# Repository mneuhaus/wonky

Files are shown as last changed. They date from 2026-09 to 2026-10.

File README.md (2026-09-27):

# wonky

A pre-release CAD kernel written in Rust, with Onshape FeatureScript and build123d
frontends. Geometry uses floating-point coordinates with exact predicates for
sign and topology decisions. Unsupported or undecidable operations return named
refusals rather than fabricated geometry or silent partial success.

## Status

The Rust kernel is under active development. FeatureScript compatibility and
solid-modeling coverage are incomplete. [CAD-Acid](docs/cad-acid.md) is the public
benchmark; its per-case evidence and explicit failures matter, not a blanket
compatibility claim. Other CAD kernels are independent validation oracles, not
production geometry engines.

## Layout

- `rust/`: Rust workspace, geometry kernel, contracts and vendored dependencies.
- `src/`: JavaScript frontends, interpreter, bridges and export integration.
- `bin/`: command-line entry points.
- `viewer/`: model inspection UI.
- `fixtures/`: public synthetic cases and frozen reference data with provenance.
- `docs/`: architecture, algorithms, research and known limitations.
- `twin/`: experimental hardware-protocol simulator.

## Build and test

Install JavaScript dependencies with `pnpm install --frozen-lockfile` when using a
pnpm lockfile, or `npm ci` with the checked-in npm lockfile. Python tools use `uv`.

```sh
cd rust && cargo test --offline --locked --workspace
# From the repository root:
NODE_OPTIONS=--max-old-space-size=8192 node scripts/test-lane.mjs full --jobs=2
uv run --project twin pytest twin/tests
```

The Node suite explicitly skips local-only fixtures and unavailable retired Bend
inputs. Rust dependencies are vendored. Some integration tests additionally need
Python oracle dependencies; consult their diagnostics for requirements.

## Local-only fixtures

Product sources and derived captures are not all public. In particular, R20
sources and derived geometry, and the historical r10b product fixtures, are not
included. Tests that require these inputs report an explicit local-only skip.
A passing public suite does not validate the omitted products. Private report
terms can be supplied via `WONKY_PRIVATE_TERMS`; publication environments should
set `WONKY_REQUIRE_PRIVATE_TERMS=1` to require that local list.

## Bend kernel (retired)

The Bend code is retained as historical work, not an active implementation.
It does not build from a public checkout: the unlicensed vendored
bend-collections library and four copyleft reference ports are intentionally
excluded. Native Bend captures are also local-only. No new Bend work is planned.

## Licence

No licence has been granted for wonky's own code yet; all rights reserved.
Third-party material retains its respective licences and attribution.
See [THIRD_PARTY_NOTICES.md](THIRD_PARTY_NOTICES.md).

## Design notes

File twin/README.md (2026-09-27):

# Wonky twin

Kinematic SKR Pico endpoints and a Feetech SC servo bus speaking the pinned
sorter's protocols over three real PTYs in one process. Run from the workspace
root with `uv run --project twin wonky-twin up --with-backend`; stop with Ctrl-C.
Tests: `uv run --project twin pytest`. The backend source is the read-only
`tmp/twin-sorter/8bd54541` archive. Its unchanged dependency lock permits reuse
of `tmp/twin-sorter/65472c9d/software/sorter/backend/.venv` without writing the
source archive. The launcher writes only isolated run state and enables servos.

The ideal-drive joint trajectory is a staircase of microstep pulses. Events
are timestamped at 100 µs boundaries, speed updates at 1 ms boundaries. Before
every command and snapshot, events are advanced to that instant, never into
the future. Endstop threshold crossings therefore occur at the actual joint
pulse time; HOME observes a crossing no later than the next 100 µs poll.
This is not continuous mechanical/contact simulation or measured hardware.

Protocol quirks intentionally retained: a fragment shorter than eight encoded
bytes survives its delimiter and corrupts the next frame; 246-byte PING has no
reply; INIT preserves position while simulated reboot resets the counter but
holds the mechanical pose. Handler validation uses the declared header length,
including PING truncation. A declaration exceeding the received payload gets
an explicit NACK, rather than emulating firmware reads into CRC/stale memory.
TMC configuration writes use the firmware's shadow CHOPCONF, independent of raw
register writes; INIT leaves TOFF=3 while the separate nEN gate is disabled.

## SC bus and trace

The default tray is id 2, SC09 (300°). `--tray-id 17` selects SC15 (210°)
instead; two servos never compete for the same `rock` joint. Ids 15/16 are SC15
flaps shown as numbers, id 18 drives `return`. Joint limits, axes and home pose
come from the frozen `fixtures/r20-motion.json`. All EEPROM limits, `zero_raw`
and `raw_per_deg` are **nominal**, not calibration measurements. Limits round
to the nearest raw count (at most half a count, also exposed in the snapshot).

Implemented: PING/READ/WRITE, big-endian EEPROM/PID/torque registers, 6-byte
GOAL_POSITION with nonzero goal time and zero speed, interpolated
PRESENT_POSITION, MOVING, nominal zero LOAD/CURRENT and nominal voltage/temp.
Unsupported writes/instructions and speed-controlled/zero-time goals return
status 0x40, angle-limit violations 0x02. Bad checksums get echo only. The PTY
emulates adapter echo even when a servo is missing or does not answer.
Retargeting starts from the actual in-flight pose, not the old target.

Torque off holds the tray/flaps at their instantaneous pose. The return arm
instead **snaps home under idealized gravity**, cancelling its trajectory. This
is an explicit kinematic assumption, not a gravity/contact-time simulation.
Unpowered goals do not move the joint; re-enabling requires a fresh goal.

Snapshots add `sc_bus` (raw actual/goal, trajectory timestamps, torque, nominal
calibration/telemetry, fault events and instantaneous coupling error), and
`joints.rock` / `joints.return`. Every 1 ms tick is retained in a bounded 120 s
numeric ring. On shutdown the CLI writes `sc-trace-<epoch>.json` and
`sc-samples-<epoch>.json` beside its run file. Samples are
`[sim_ns, rock_deg, return_deg, rock_torque, return_torque]`. The wire history is
bounded to 20,000 transactions; use short isolated runs for full-stroke checks.
`wonky_twin.sc_trace.check_trace` independently replays accepted wire goals and
torque commands, compares every retained pose tick and PRESENT_POSITION read,
and counts every coupling violation. Dump/transition ticks are NOT exempt.

For programmatic fault scenarios, call `twin.sc.inject(id, kind, count)` under
`twin.lock`: `nack_goal` refuses with status 0x02, `no_reply_goal` refuses with
no servo response, `uncalibrated` exposes EEPROM 500..520. Counts are wire
transactions, so three unanswered attempts exhaust the backend's retries.
This is pre-execution refusal, not lost ACK after executing a command.

Run the real-backend diagnostic (sandbox, no HTTP listener) with
`uv run --project twin python -m wonky_twin.sc_acceptance --output
 twin/evidence/sc-acceptance.json`. It records the normal double-drop reject
branch, then separately labelled controller-component probes using real
absolute-degree TrayServo objects, real ScServoBus clients and synthetic
perception counts. Exit 1 preserves evidence of unmet upstream acceptance; it
does not patch the backend or convert those blockers into passing tests.
The full-app Safe Home proof lives in `tests/test_live_backend.py`.

## OPEN

- **TW5 return trigger:** pinned `controller.py:_servo_or_none` omits
  `zero_raw` / `raw_per_deg` when constructing TrayServo. The actual confirmed
  double-drop reject path therefore sets `return_skipped` and routes to the
  chute. Supplying an absolute servo in a component probe is NOT application
  end-to-end acceptance.
- **TW5 NACK:** `ScServoBus._transact` records nonzero status but returns a
  successful payload. A refused GOAL_POSITION does not fault the tray. No
  reply does fault it; uncalibrated limits refuse initialization.
- **TW5 coupling/dwell:** `(return=180, rock=-45)` differs by 90° from the
  literal coupling law. Even excluding that deliberate dump pose, the pinned
  planner begins lowering before rock has interpolated back to -135°. The
  trace checker reports this transition violation instead of teleporting the
  joint or widening the 5° tolerance. A timed target dwell is not necessarily
  a full 1 s at the measured pose.

- **D5, blocked:** the backend's background `waveshare_inventory` calls
  `serial.tools.list_ports.comports()` without consulting `SORTER_MCU_PORTS`.
  The MCU-bus override is not a global no-enumeration guarantee. Requires a
  sorter-side inventory/discovery gate. The sandbox prevents real serial
  access, but does not prevent enumeration; no monkeypatch/workaround here.
- **D6, blocked:** backend `main.py` hard-codes port 8000 and has a conflicting
  process guard. Requires a sorter-side configurable-port/ownership seam.
  Launch refuses an occupied 8000 without touching its listener. Refusal is
  not alternate-port support; no port interception or backend patch here.

The full suite retains the failing D5/D6 acceptance tests. Neither is skipped
or relabeled as passing. A passing homing run does not close those blockers.

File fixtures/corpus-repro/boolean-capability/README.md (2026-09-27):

# Repros: cluster boolean-capability

Minimal FeatureScript inputs for the corpus cluster "opBoolean outside the
admitted Boolean paths" ([analysis](../../../docs/corpus/cluster-boolean-capability.md)).
Each feature is one real corpus failure reduced to the refused `opBoolean` and
the operations that build its operands. Corpus numbers are kept where the
failure depends on them. The files do not read anything from `~/Workspace/cad`.

Checked on 2026-09-23 (00:38, and again at 04:13 against the unchanged production
Boolean code) with the production CLI on the default JS path:
`node bin/wonky.mjs fixtures/corpus-repro/boolean-capability/<file> --check --feature <feature>`.
The messages are shortened after the first clause; all four are exactly the
corpus messages of the cluster. Each feature runs in 0 to 3 s.

| file `#feature` | sub-cause | stands for (corpus units) | observed |
|---|---|---|---|
| `coaxial-revolution.fs#ringUnion` | coaxial-revolution | fs95 ring unions (56) | `61:9: opBoolean supports coaxial cylinder primitives, … general trimmed-face booleans are not implemented` |
| `coaxial-revolution.fs#countersunkHead` | coaxial-revolution | countersunk screws: cylinder ∪ cone (26) | `70:9:` same message |
| `through-hole-admission.fs#obliqueHole` | pierce-admission (oblique caps) | hopper panels fs421/fs269/fs244 (13) | `61:5: opBoolean through holes need a tool axis perpendicular to exactly two faces of the target` |
| `through-hole-admission.fs#steppedHole` | pierce-admission (extra perpendicular faces) | fs87/fs88 diagonals (4) | `61:5:` same as above |
| `through-hole-admission.fs#arcPlateHole` | pierce-admission (arc edges) | fs422/fs425 guides (8) | `61:5: opBoolean supports coaxial cylinder primitives, …` (the pierce gate excludes ranged edges) |
| `through-hole-admission.fs#unitedPlateHole` | pierce-admission (ranged line edges) | switchPinCapR4, drilledHangerU2, upperMotorHanger (3) | `61:5:` general message |
| `general-trimmed-face.fs#socketHex` | general | hex sockets in coaxial screws fs95/fs88/fs273 (18) | `57:5:` general message |
| `general-trimmed-face.fs#bandNotch` | general | channel bases fs398/fs550/fs386 (16) | `57:5:` general message |
| `general-trimmed-face.fs#bossUnion` | general | rounded ends (stadium unions) fs276/fs398/fs509 (6) | `62:5:` general message |
| `general-trimmed-face.fs#ringBoss` | general | fs95 screw bosses on ring walls (next blocker of 28) | `62:5:` general message |
| `general-trimmed-face.fs#spokeTrim` | general-trim | fs95 bottomSpoke/switchBracket, fs88 motorBracket (10) | `57:5: opBoolean through hole must land in material; this axis misses the face it would pierce` |
| `nary-union.fs#threeToolUnion` | nary | `unite(context, id, [a, b, c])` helpers (13) | `34:9: opBoolean currently requires two tools for union/intersection, or one target and one tool for subtraction` |
| `nary-union.fs#bridgedThreeToolUnion` | nary (first two tools disjoint, the third connects them) | fs95 `motorBracket` `join` | `48:9:` same as above |

After W1 (2026-09-23), production `opBoolean` is N-ary
(`ModelingContext.naryBoolean`): both `nary-union.fs` features build one body
of 15000 mm³ with the production CLI. See
[docs/corpus/w1.md](../../../docs/corpus/w1.md).

## Through the bake-off route

`node scripts/corpus/boolean-bakeoff.mjs` freezes the operands of each refused
`opBoolean` (production probe), runs them through the corefine mesh Boolean
and the recover prototype (native CPU builds), exports STEP with the kernel's
serializer and measures it with OpenCascade. Results:
`out/corpus/boolean-capability/bakeoff.json`.

| repro | result | volume vs closed form |
|---|---|---|
| ringUnion, countersunkHead, steppedHole, arcPlateHole, unitedPlateHole, socketHex, bandNotch, spokeTrim | exact: OCCT-valid STEP | ≤ 2.4e-14 relative |
| obliqueHole | recovered, but the kernel's cylinder pcurve export refuses it (`InvalidSource`): the rims are circles on the F64 tool axis, the caps are the planar kernel's F32 planes, tilted by 3e-7 rad | – |
| bossUnion | recover refuses: `mesh boundary does not traverse its exact curve once` (plane tangent to the cylinder at the stadium corners) | – |
| ringBoss | recover refuses: `cylinder/cylinder intersection off a common axis is a space quartic` (the axes are parallel, so the exact curves are lines) | – |

Both N-ary features build one body of 15000 mm³ (closed form: 6000 + 2 × 4500)
once the call is decomposed into binary calls
(`WONKY_CORPUS_STUB=nary node scripts/corpus/boolean-probe.mjs <file> <feature>`).
`bridgedThreeToolUnion` needs the component-aware decomposition: a left fold
that continues with the first result body returns two bodies, because the
first pair is disjoint.

## With F32x2 prisms (simulation)

With every polygon prism built by the existing F32x2 line/arc extruder
(`WONKY_CORPUS_SIMULATE=linearc node scripts/corpus/boolean-probe.mjs <file> <feature>`,
the fix proposed by the boolean-invalid-topology analysis), `obliqueHole`,
`steppedHole`, `unitedPlateHole`, `bossUnion` and `spokeTrim` all refuse with
the general message. Every F32x2 prism edge carries a `curveRange` (18 of 18
on `steppedHole`), and the pierce gate (`src/boolean.mjs:108`) keeps ranged
edges out. That fix therefore needs the gate to admit ranged lines at the
same time.

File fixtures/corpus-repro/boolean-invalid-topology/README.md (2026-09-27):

# Repros: planar arrangement Boolean refuses F32-built operands

Cluster `boolean-invalid-topology` of the corpus run. The analysis is in
[docs/corpus/cluster-boolean-invalid-topology.md](../../../docs/corpus/cluster-boolean-invalid-topology.md).
Every file is standalone and does not depend on `~/Workspace/cad`.

All were re-checked on 2026-09-23 at 04:13 with the production CLI on the
default JS path (`node bin/wonky.mjs <file> --check [--feature F]`). The
records are in `out/corpus/boolean-invalid-topology/repros-recheck.jsonl`,
with `uptime` per record. These are inputs, not tests: they document current
behaviour.

## After W2 (2026-09-23, 19:25)

Production now builds polygon prisms and their rigid copies in F32x2 in Bend
(`kernel/polygon-prism.bend`, wired in `src/kernel.mjs`; docs/corpus/w2-plan.md task D).
W2 also fixed a false negative in the planar arrangement's plane equality
(`kernel/ports/planar-boolean-arrangement.bend` `plane_equal`): its F32x2 cross filter
required an exactly zero cross, but `R.mul` is not commutative in its last bits, so a
prism side face of `slanted-prism-union.fs` was not equal to itself and the face
ownership map refused (stage 6). The exact certificate still decides.
Re-checked with the production CLI on the JS path (`tmp/w2/wire/repros.sh`):

| File (feature) | Observed after W2 |
|---|---|
| `wedge-union.fs` (`slanted`) | builds: 41 vertices, 79 edges, 40 faces, 319 mm³ |
| `wedge-union.fs` (`diag45`, `square`) | unchanged: 394 mm³, 494 mm³ |
| `slanted-prism-union.fs` | builds: 56 vertices, 106 edges, 52 faces, 206767.2 mm³ |
| `slanted-prism-cut.fs` | builds: 48 vertices, 91 edges, 45 faces, 48766.666667 mm³ |
| `rotated-box-cut.fs` | builds: 8 vertices, 12 edges, 6 faces, 36339.234517 mm³ |
| `slanted-prism-intersection.fs` | builds: 16 vertices, 24 edges, 10 faces, 43659.488134 mm³ |
| `many-vertex-prism-cut.fs` | unchanged: `37:9: … subtraction unresolved: UnsupportedArrangement (stage 1, detail 0)` (input size) |
| `next-blocker-chamfer.fs` (`chamferOnEdge`) | builds: 12 vertices, 20 edges, 10 faces, 2170 mm³ (= 2800 − 14 · 45) |
| `next-blocker-chamfer.fs` (`slantedCut`) | builds: 14 vertices, 23 edges, 11 faces, 2285.694444 mm³ (= 2800 − 14 · 36.736111) |
| `next-blocker-chamfer.fs` (`chamfer45`) | unchanged: 1904 mm³ |

Both chamfers get further than the simulation below predicted (`AmbiguousContact` stage 2
and `UnsupportedArrangement` stage 6): the simulation built line/arc-extruder bodies with
other carrier words, and it ran before the `plane_equal` fix.

## Before W2

The last column is the result with the fix simulated, which builds every
polygon prism and its rigid copies in F32x2
(`node scripts/corpus/diagnose-planar-admission.mjs <file> [feature] --simulate linearc`).

| File (feature) | Stands for | Observed | With the fix simulated |
|---|---|---|---|
| `wedge-union.fs` (`slanted`) | **minimal**: a 3-vertex wedge with a 35° hypotenuse, united with a box | `33:5: Native planar arrangement union unresolved: InvalidTopology (stage 1, detail 0)` | builds, 319 mm³ |
| `wedge-union.fs` (`diag45`) | control: 45° hypotenuse | builds: 41 vertices, 79 edges, 40 faces, 394 mm³ | builds |
| `wedge-union.fs` (`square`) | control: rectangle | builds: 44 vertices, 84 edges, 42 faces, 494 mm³ | builds |
| `slanted-prism-union.fs` | fs95 unions, e.g. `interface-r3.fs#bottomSpoke` | `33:9: … union unresolved: InvalidTopology (stage 1, detail 0)` | builds, 206767.2 mm³ |
| `slanted-prism-cut.fs` | `project-component-4c7a33fe.fs` `noseCut`, fs95 `retainingKey`/`switchBracket` cuts | `33:9: … subtraction unresolved: InvalidTopology (stage 1, detail 0)` | builds, 48766.667 mm³ |
| `rotated-box-cut.fs` | the 8 r10b copies `r10bTransferEdge` (`buildTransferEdge > cut`), unchanged r10b numbers | `35:9: … subtraction unresolved: InvalidTopology (stage 1, detail 0)` | builds, 36339.2345 mm³ |
| `slanted-prism-intersection.fs` | fs95 `bottomSpoke` R4/R5 (`flareClip`) | `33:9: Native convex-tool intersection unresolved: UnsupportedArrangement (tool 0, face 0)` | builds, 43659.488 mm³ |
| `many-vertex-prism-cut.fs` | `channel-bases-r7.fs`: a 384-vertex polygonized arc band | `37:9: … subtraction unresolved: UnsupportedArrangement (stage 1, detail 0)` | unchanged: input size limit (256 vertices) |
| `next-blocker-chamfer.fs` (`chamferOnEdge`) | second level: a slanted face that starts on an existing edge | `37:5: … subtraction unresolved: InvalidTopology (stage 1, detail 0)` | `AmbiguousContact (stage 2, detail 11)` |
| `next-blocker-chamfer.fs` (`slantedCut`) | second level: a slanted cut in general position | `37:5: … subtraction unresolved: InvalidTopology (stage 1, detail 0)` | `UnsupportedArrangement (stage 6, detail 0)` |
| `next-blocker-chamfer.fs` (`chamfer45`) | control: 45° chamfer | builds: 22 vertices, 40 edges, 20 faces, 1904 mm³ | builds |

On the bake-off `recover` route
(`scripts/corpus/boolean-invalid-topology/bakeoff-recover.mjs`):

- with today's F32 operands, the wedge, slanted union, slanted cut and rotated
  cut are refused at leaf intake (`vertex off its surface by 7.7e-7 … 3.6e-5`);
- with F32x2 operands, all four build as OCCT-valid exact B-reps;
- both second-level chamfers build as OCCT-valid exact B-reps from bake-off
  `prism` primitives.

The last column of the table is the expected result once the F32x2
construction exists. `wedge-union.fs` also states it in its header (319 mm³,
that is 175 + 180 − 36).

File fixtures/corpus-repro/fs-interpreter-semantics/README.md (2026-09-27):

# Repros: fs-interpreter-semantics

Minimal FeatureScript inputs for the cluster "Interpreter semantic gaps"
(67 units, 58 files, 13 families; see
[docs/corpus/cluster-fs-interpreter-semantics.md](../../../docs/corpus/cluster-fs-interpreter-semantics.md)).
They do not depend on `~/Workspace/cad`. These are inputs, not tests.

Checked on 2026-09-22 with `node bin/wonky.mjs <file> --check` on the default JS
path. The "with prototype fix" column runs the same CLI with the in-memory
prototype, `node --import ./scripts/corpus/fs-interpreter-semantics/prototype/register.mjs bin/wonky.mjs <file> --check`.
It does not change any file under `src/`.

| File | Units | Production CLI | With prototype fix |
|---|---:|---|---|
| `length-bounds-default.fs` | 21 | `13:9: Expected a length with units (for example 10 * millimeter)` | builds, 25 mm cube (LENGTH_BOUNDS default 0.025 m) |
| `boolean-default.fs` | 15 | `12:9: Feature precondition failed` | builds (`open` = false) |
| `annotation-filter-and.fs` | 16 | `15:50: FeatureScript conditions must be boolean` | builds (only the annotation's `Default` is evaluated). An unpicked query parameter is not resolved by this feature; a feature that resolves one gets an explicit capability error (supply it with --param, e.g. part=qNothing()). |
| `angle-bound-spec.fs` | 9 | `8:14: Expected AngleBoundSpec` | builds |
| `color-type-tag.fs` | 2 | `16:9: Expected Color` | builds (`color()` returns a `Color`-tagged map) |
| `units-source-error.fs` | 4 | `15:22: Incompatible units in expression` | same error. This is correct: the corpus source adds a unitless vector to a length vector. |

With explicit parameters, production already builds the first two, for example
`--param 'size=25*millimeter'` and `--param 'open=false'`.

Re-checked on 2026-09-23: same results.

After W1 (2026-09-23), the production CLI gives the "with prototype fix"
results: `length-bounds-default.fs` 15625 mm³, `boolean-default.fs`,
`annotation-filter-and.fs`, `angle-bound-spec.fs` and `color-type-tag.fs`
1000 mm³ each. `units-source-error.fs` still fails with
`15:22: Incompatible units in expression`. See
[docs/corpus/w1.md](../../../docs/corpus/w1.md).

The two files in `next/` are not part of this cluster. They are the Boolean
that 19 units hit once the cluster is fixed, and they fail in production today
independent of it. Both are the boolean-capability cluster's
`pierce-admission` subcause: after earlier planar cuts or unions, the cap
planes are split into several coplanar faces and the edges are ranged.

| File | Units | Production CLI | Bake-off recover route |
|---|---:|---|---|
| `next/lochwand-hole-in-notched-panel.fs` | 17 lochwand + 1 gt2 mini-r1 (through holes) | `29:9`: general trimmed-face `opBoolean` message | exact, OCCT-valid, volume 1189758.850 mm³ (closed form) |
| `next/blind-pilot-in-stepped-body.fs` | 1 mini_camera (blind pilot bore, 1 mm floor) | `31:9`: same message | exact, OCCT-valid, volume 12146.907 mm³ (closed form) |

The same hole in the panel without the notch builds in production. A
through-hole admission fix ("pierce v2") would cover the first file but not
the second: a blind pocket needs a floor the hole arm does not build. The
bake-off run is `scripts/corpus/fs-interpreter-semantics/next-bakeoff.mjs`;
see `docs/corpus/cluster-fs-interpreter-semantics.md` §4.4.

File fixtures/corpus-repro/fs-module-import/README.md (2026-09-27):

# fs-module-import repros

Minimal inputs for the cluster "FeatureScript module imports cannot be
resolved". The analysis is in
[docs/corpus/cluster-fs-module-import.md](../../../docs/corpus/cluster-fs-module-import.md).
The inputs do not depend on `~/Workspace/cad`. They are inputs, not tests. They
record current behavior and need no change to stay valid. All were checked on
2026-09-23 with the production CLI on the default JS path.

## Unresolved imports (the corpus signature)

Run `node bin/wonky.mjs <file> --check` from the repository root.

| File | Stands for | Observed |
|---|---|---|
| `part-studio-import.fs` | `NS::build` of a Part Studio, 95 files. Reduced from `cad-project-040/src/buildplate-r16-rear.fs`. | `13:23: Unresolved Onshape module 'Parts': d9c8543f8a347821ee2e2194 at version 188904c7a670c9866e4b06de. Supply its frozen source or B-rep snapshot.` |
| `feature-studio-import.fs` | `NS::function` of a Feature Studio in another document, 3 files. Reduced from `machine-interface-r11/top-full-module-r4/module-r4.fs`. | `12:5: Unresolved Onshape module 'SourceR11': 889f3a9e…/3a4a721e…/6d0c52f9… at version 929e2218…. Supply its frozen source or B-rep snapshot.` |
| `local-path/main.fs` + `lib.fs` | An fsocct `version: "local"` library, 1 file. Reduced from `cad-project-043/fsocct/examples/canonical_m3_tool.fs`. | `12:5: Unresolved Onshape module 'M3': ./lib.fs at version local. Supply its frozen source or B-rep snapshot.` |

## With a snapshot present (`snapshot/ (local only)`)

`snapshot/ (local only)idioms.fs` imports the `base` Part Studio of r10b at the r10b
microversion. `snapshot/ (local only)modules.json` uses schema `wonky-onshape-inputs/1`. It
is bound to the SHA-256 of `idioms.fs` and holds one captured body, the `T06
R6d 249.2mm rear hopper wall` (part `Zu2DD`). The files
`modules/base/parts.json` and `modules/base/Zu2DD.body.json` are byte copies
of the files in `fixtures/r10b/modules/base/`. Their hashes therefore match the
r10b capture of 2026-09-21. Each feature exercises one corpus idiom.

Run `node bin/wonky.mjs fixtures/corpus-repro/fs-module-import/snapshot/ (local only)idioms.fs --check --feature <name>`.

| Feature | Corpus idiom (cluster files) | Observed before stage 1 | After stage 1 (revision-keyed loader) |
|---|---|---|---|
| `nameLookup` | `loadedContext` plus a name table, as in r10b (36 files) | builds: `model/src/wall: 16 vertices · 24 edges · 10 faces · volume not evaluated · closed topology` (positive control) | builds (unchanged) |
| `instantiatorIdQuery` | `qCreatedBy(<instantiator id>)` after `instantiate` (15 files) | the file's own check: `42:15: qCreatedBy(instantiator id) found 0 bodies; Onshape finds 1` | builds: 1 body (the instantiator id is recorded in `createdBy`) |
| `noLoadedContext` | `addInstance` without `loadedContext` (56 files) | `51:5: loadedContext must belong to the specified frozen module build` | `51:5` refusal lifted; next: `Body 'P10 R6d 180mm upper core - raised accessible idler' was not captured in this input snapshot` (the snapshot holds 1 of 17 parts; all solids are selected) |
| `instanceTransform` | `addInstance` with a `transform` (14 files) | `62:5: addInstance field 'transform' is not implemented` | builds: the wall moved by +10 mm in z |
| `sourceFeatureId` | `qCreatedBy(makeId("<source feature id>") + …)` (3 files) | `74:89: 'makeId' is not defined or not implemented by this prototype` | unchanged if `makeId` is missing; with `makeId`: `qCreatedBy over an imported source context is not implemented: frozen Onshape inputs do not record which source feature created each part` |
| `containsPoint` | `qNthElement(qContainsPoint(qBodyType(qEverything(…))))` (56 files select source parts dynamically) | `85:68: 'qNthElement' is not defined or not implemented by this prototype` | unchanged (stage 3) |
| `importedVolume` | an imported source body identified by `evVolume` (fs95, 14 files) | builds: evVolume integrates the imported body in Bend (kernel/volume.bend, closed form, bound in the operation evidence) | fixed (r20-gate analytic-volume) |
| `importedBox` | an imported source body identified by `evBox3d` (fs10, fs11, fs16, fs19: 7 files) | `111:5: Tight bounds over analytic imported faces are not implemented` | unchanged (stage 3) |

Before stage 1, the source binding refused an existing capture for any other
source, even one that imports the same immutable Onshape revision:

```sh
node bin/wonky.mjs fixtures/corpus-repro/fs-module-import/snapshot/ (local only)idioms.fs --check --feature nameLookup \
  --modules fixtures/r10b/modules.json
# …/idioms.fs: Frozen module manifest does not match the FeatureScript source SHA-256
```

This is why 16 corpus files failed even though they import only revisions
that are already captured for r10b (same element and microversion). After
stage 1 manifests bind revisions ([docs/onshape-inputs.md](../../../docs/onshape-inputs.md)),
so the same command builds `model/src/wall`, and the body records
`provenance.sourceBinding: "mismatch"`. The inputs in this directory are
unchanged; `test/modules-revision.test.mjs` runs every feature above.

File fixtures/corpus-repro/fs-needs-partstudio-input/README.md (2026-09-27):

# fs-needs-partstudio-input repros

Analysis: [docs/corpus/cluster-fs-needs-partstudio-input.md](../../../docs/corpus/cluster-fs-needs-partstudio-input.md).
Checked on 2026-09-23 (04:12 and later) with the production CLI on the default JS path
(`node bin/wonky.mjs <file> --check`). These are inputs, not tests.

| File | Stands for | Observed |
|---|---|---|
| `modify-existing-part.fs` | 26 fixed-frame R29/R30 files, 4 c-channel files, 3 return-hardware files, the flush-return guide and the rotor closure (count guard, then a bounds guard) | `15:19: Derive exactly one source part into this Part Studio first` |
| `volume-selected-source.fs` | 14 TOP-clearance files (source part picked by `evVolume`) | `14:15: Expected exactly the declared current TOP source body; matching count=0` |
| `source-block.fs` | The 40 x 20 x 10 mm part both repros expect. It stands in for the earlier Part Studio feature. | builds: `model/block: 8 vertices · 12 edges · 6 faces · 8000 mm³` |
| `catch-without-binding.fs` | 2 misclassified files: `cad-project-028/sorter.fs`, `cad-project-038/scripts/skirt_collar.fs` | `14:143: Expected '(', found '{'` (parser gap; the corpus probe flagged it as a model throw). After W1 (2026-09-23): builds, 2 bodies of 1000 mm³ |

Next blockers behind the guard (they need no Part Studio input; the lines are
copied unchanged from the corpus):

| File | Stands for | Observed |
|---|---|---|
| `next-blocker-fixed-frame-n3.fs` | Level 1 of 20 fixed-frame R29/R30 files: `n3 = n1 - n2` (`fixed-frame-r30.fs:81-83`) | `33:9: Native planar arrangement subtraction unresolved: InvalidTopology (stage 1, detail 0)`. F32-built slanted operands; with F32x2 prisms simulated: `AmbiguousContact (stage 2, detail 15)` |
| `next-blocker-line-arc-joins.fs --feature tinyFilletArcJoin` | Level 2 of the same 20 files: a 0.19° fillet arc between two lines (sketch `n4s0`) | `27:9: Native line/arc sketch unsupported: SelfIntersectionOrTouch` |
| `next-blocker-line-arc-joins.fs --feature splitStraightEdge` | Level 1 of 5 older fixed-frame files (sketch `n2s0`): two exactly collinear consecutive lines | `46:9: Native line/arc sketch unsupported: SelfIntersectionOrTouch` |

Both Part Studio repros build a through hole once `source-block.fs` runs first
in the same context. The CLI cannot do that. The prototype harness can
(`tmp/corpus/cluster-partstudio/seeded-build.mjs`, analysis only):

```
node tmp/corpus/cluster-partstudio/seeded-build.mjs \
  fixtures/corpus-repro/fs-needs-partstudio-input/modify-existing-part.fs \
  --seed-fs fixtures/corpus-repro/fs-needs-partstudio-input/source-block.fs
# {"ok":true,"bodies":1,...}
```

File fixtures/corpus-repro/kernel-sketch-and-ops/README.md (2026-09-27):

# Repros: sketch/profile validation and operation limits

Cluster `kernel-sketch-and-ops` of the corpus run. The analysis is in
[docs/corpus/cluster-kernel-sketch-and-ops.md](../../../docs/corpus/cluster-kernel-sketch-and-ops.md).
Every file is standalone: it does not depend on `~/Workspace/cad`. All were checked
on 2026-09-23 with the production CLI on the default JS path
(`node bin/wonky.mjs <file> --check [--feature F]`), first at 00:10 and again at 04:20
(`node scripts/corpus/kernel-sketch-and-ops/recheck.mjs`, output in
`out/corpus/cluster-kernel-sketch-and-ops.recheck.jsonl`). The observed output is below.

These are inputs, not tests. They document current behaviour.

## After W2 (2026-09-23, 19:25)

Production now builds every polygon prism with the Bend profile ring merge and the F32x2
polygon prism (`kernel/profile-ring.bend`, `kernel/polygon-prism.bend`, wired in
`src/kernel.mjs` `extrudeInBend`/`transformInBend`; docs/corpus/w2-plan.md task D).
Re-checked with the production CLI on the JS path; the table further down is the record
from before W2.

| File (feature) | Observed after W2 |
|---|---|
| `cap-normal-far-from-origin.fs` (`tiltedOctagonFar`) | builds: 16 vertices, 24 edges, 10 faces, 7677.8832 mm³ |
| `cap-normal-far-from-origin.fs` (`tiltedRectangleFar`) | builds: 8 vertices, 12 edges, 6 faces, 1454.4 mm³ (the key pocket, 40.4 × 6 × 6) |
| `cap-normal-far-from-origin.fs` (`tiltedOctagonNear`) | unchanged: 7677.8832 mm³ |
| `through-hole-tilted-panel.fs` | builds: 10 vertices, 15 edges, 7 faces, 62690.946551 mm³ (= 280 · 70 · 3.2 − π · 1.7² · 3.2) |
| `collinear-polyline-vertex.fs` | builds: 8 vertices, 12 edges, 6 faces, 1600 mm³; vertex 2 merged exactly (deviation 0) |
| `profile-over-256-vertices.fs` | builds: 600 vertices, 900 edges, 302 faces, 2513.090386 mm³ (= 120000 · sin 1.2°) |
| `next-tilted-pocket-subtraction.fs` | `27:9: Native planar arrangement subtraction unresolved: UnsupportedArrangement (stage 6, detail 0)` |
| `next-pierce-after-copy.fs` | builds: 3959.787614 mm³, then 3919.575228 mm³ (pierce gate, W2 task A) |
| `loft-*.fs`, `line-arc-sketch-with-holes.fs` | unchanged (not in W2's scope) |

Near-collinear vertices (0 < deviation ≤ the profile tolerance) are merged too and recorded
as a regularization (`construction.profileMerge`, `exactness: 'regularized'`);
`src/kernel.mjs` `PROFILE_MERGE` switches that off. Whether it stays on under `strict` is
Marc's decision.

## Before W2

| File (feature) | Cause | Observed |
|---|---|---|
| `cap-normal-far-from-origin.fs` (`tiltedOctagonFar`) | cap normal | `19:5: Face vertices do not lie on the analytic plane` |
| `cap-normal-far-from-origin.fs` (`tiltedRectangleFar`) | cap normal | `19:5: Plane frame is not orthonormal` |
| `cap-normal-far-from-origin.fs` (`tiltedOctagonNear`) | control | builds: 16 vertices, 24 edges, 10 faces, 7677.88 mm³ |
| `through-hole-tilted-panel.fs` | cap normal, seen by the through-hole Boolean | `23:9: opBoolean through holes need a tool axis perpendicular to exactly two faces of the target` |
| `loft-two-polygons.fs` (`prismatoid`) | loft, planar sides | `27:9: opLoft currently requires two coaxial circular profiles` |
| `loft-two-polygons.fs` (`twistedOctagon`) | loft, twisted sides | `36:9: opLoft currently requires two coaxial circular profiles` |
| `loft-two-polygons.fs` (`squareToCircle`) | loft, polygon to circle | `47:9: opLoft currently requires two coaxial circular profiles` |
| `loft-tapered-slot.fs` (`taperedSlot`) | loft, lines and concentric arcs (next blocker of 10 fs398 channel-base units) | `32:9: opLoft currently requires two coaxial circular profiles`; exact result 4140 + 798π = 6646.990938 mm³ |
| `loft-tapered-slot.fs` (`slotExtrudeControl`) | control | builds: 8 vertices, 12 edges, 6 faces, 7865.574951 mm³ |
| `collinear-polyline-vertex.fs` | collinear vertex | `13:9: Profile has collinear or nearly collinear consecutive edges` (after W2 task C, before D: `15:9: Face loop has collinear or nearly collinear consecutive edges`) |
| `profile-over-256-vertices.fs` | vertex limit | `16:9: A profile must have 3–256 vertices` |
| `line-arc-sketch-with-holes.fs` | inner loops | `18:9: A line/arc sketch cannot mix entities with rectangle, polyline or circle profiles` |
| `next-pierce-after-copy.fs` | next blocker (not this cluster) | `wonky: Bend Real serialization requires a finite magnitude <= 1e20 without F32 exponent underflow` (JS RangeError, no source location) |
| `next-tilted-pocket-subtraction.fs` | next blocker (cluster boolean-invalid-topology) | `27:9: Native planar arrangement subtraction unresolved: InvalidTopology (stage 1, detail 0)` |

With the analysis harness (`scripts/corpus/kernel-sketch-and-ops/harness.mjs`,
analysis stubs only, no production change), these build:

- `--stub frame`: both far cap-normal features and the tilted-panel hole;
- `--stub loftplanar`: `prismatoid`, with volume 3626.6667 mm³ (the exact
  prismatoid volume);
- `--stub collinear`: `collinear-polyline-vertex.fs`;
- `--stub pvol`: `next-pierce-after-copy.fs`.

Other in-flight fixes, simulated in memory (04:20 re-check):

- **F32x2 polygon prism** (the boolean-invalid-topology fix,
  `scripts/corpus/diagnose-planar-admission.mjs --simulate linearc`): both far
  cap-normal features build (7677.8832 mm³). The tilted pocket moves from
  `InvalidTopology (stage 1)` to `UnsupportedArrangement (stage 6, detail 0)`.
  The tilted-panel hole reports the general-Boolean refusal, because the
  simulation's bodies carry curve ranges that the through-hole arm does not
  take. That result is a limit of the simulation.
- **Bake-off route** (`WONKY_CORPUS_STUB=hybrid-all scripts/corpus/boolean-probe.mjs`,
  corefine and recover prototypes, test only):
  - The tilted pocket is recovered from the F32 operands. OCCT reports it
    valid, with 11 faces and 7316.39927 mm³ against the closed-form
    7316.4 mm³ (relative error 1.0e-7).
  - The tilted-panel hole is recovered and the kernel validator accepts it,
    but STEP export refuses it: `STEP cylindrical parameter curves unresolved:
    InvalidSource`.

The cap-normal failures depend on how the F32 coordinates round. The
coordinates are therefore computed exactly as in the corpus source. A
hand-rounded origin can make the same prism build.

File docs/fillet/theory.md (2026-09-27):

# Fillets and chamfers: mathematics and algorithms

Status: 23 September 2026, fillet landscape part 1 (survey). Nothing in this
document is implemented. It is the theory that the prototype ports of part 2
should be built from and judged against.

**Labels.** Every claim that matters carries one of:

- **DOCUMENTED**: stated in a source that was read (the deep-read notes in
  `docs/research/sources/`, a paper, vendor docs, or kernel code).
- **MEASURED**: checked by running something in this repo. The numeric checks
  are in `tmp/fillet/theory-checks.mjs` (run with `node`).
- **INFERRED**: derived here from documented facts. The derivations are
  written out so that they can be checked.
- **HEARSAY**: remembered or second-hand and not verified in this pass.

The sources are cited by their note name, for example
`occt-modeling-algorithms-guide-and-tkfillet-chfi3d-fillets-c.md` (short:
"OCCT note"). The notes carry the URLs, licences and page references.

**Licences, short form** (the notes have the details):

| source | licence | what may be used |
|---|---|---|
| OCCT (ChFiKPart, BlendFunc, ChFi3d) | LGPL-2.1 + exception | ideas and algorithms only; AGENTS.md forbids OCCT in production, and translated code would be LGPL-derived. OCCT is an oracle via `uv run`, never a dependency |
| monstertruck / truck | Apache-2.0 | may be ported with attribution |
| remus | Apache-2.0 | contract layer and types may be ported with attribution |
| Onshape std library (`fillet.fs`, enums, bounds) | MIT | may be copied with the notice |
| Parasolid FD, ACIS docs | proprietary documentation | vocabulary and behaviour only, no text |
| HP/CoCreate patents US5615317A, US6133922A | expired | methods free to implement |
| Geomagic setback patent US8004517B1 | in force until 2027-12-17 | check before any commercial release |
| papers (Choi-Ju, Kós-Martin-Várady, Lukács, Dahl, Shene, Wallner-Pottmann, Rossignac-Requicha) | journal copyright | mathematics may be re-derived freely |

## 0. Reading guide and the one-page summary

1. A constant-radius fillet is the envelope of a ball of radius `r` that
   touches both faces. Its **spine** (the ball-centre path) is the
   intersection of the two faces' offsets by `r` toward the ball; its **contact
   curves** are the spine moved back by `r` along each face normal; its cross
   section is a circular arc. Everything else in this document is a special
   case, an existence condition, or what happens at the ends (section 2).
2. **Two symmetry theorems decide when the fillet is analytic** (section 4):
   - if both faces are invariant under one translation direction `d` (planes
     containing `d`, cylinders with axis parallel to `d`) the problem is a 2D
     fillet in the plane perpendicular to `d`, and the fillet is a
     **cylinder**;
   - if both faces are surfaces of revolution about one common axis (plane
     perpendicular to it, coaxial cylinder, cone, torus, sphere centred on it)
     the problem is a 2D fillet in the meridian half-plane, and the fillet is a
     **torus** (a **sphere** when the arc centre lies on the axis).

   Every other pair gives a pipe surface around a non-circular spine. That is
   exact only as a procedural surface or a rational B-spline, never as a
   plane, cylinder, cone, sphere or torus.
3. Chamfers follow the same two theorems: **plane** in the translation family,
   **cone** (or plane or cylinder) in the rotation family, a rational ruled
   surface otherwise.
4. The dihedral angle enters through the angle `θ` between the face normals:
   contact setback `r·tan(θ/2)`, centre distance `r/cos(θ/2)`, arc angle `θ`,
   section area `r²(tan(θ/2) − θ/2)` (section 3).
5. Vertices: a **sphere** corner exists whenever three blends of equal radius
   and uniform convexity meet (section 6). Everything else (unequal radii,
   mixed convexity, valence ≥ 4 without a common point) needs a setback
   n-sided patch, which is a new non-analytic surface type.
6. **wonky today** (MEASURED by reading `kernel/analytic.bend` and grepping
   `src/`): surfaces `Plane`, `Cylinder`, `Cone`; curves `Line`, `Circle`,
   `Ellipse`. Sphere and torus exist only in `kernel/proto/recover/geom.bend`
   (`SSphere`, `STorus`) and the bake-off test serializer. So wonky can hold
   exactly, today: every chamfer of the two symmetric families, plane/plane and
   other translation-family fillets, and linear variable-radius plane/plane
   fillets (a cone, section 8). It needs `Torus` and `Sphere` for cap-edge
   fillets and sphere corners, which are the most common FDM cases after
   plane/plane (section 11).

## 1. Conventions and definitions

### 1.1 Orientation

- A face `F` has a carrier surface and a `same_sense` flag
  (`kernel/analytic.bend`, type `Face`). `n_F(p)` is the **outward** unit
  normal of the face at `p`: the surface normal, negated when `same_sense` is
  false.
- Loops run counter-clockwise when viewed from outside, i.e. looking along
  `−n_F`, so material is on the left of each coedge. (INFERRED as the kernel
  convention; confirm against `kernel/topology.bend` before implementing.)
- An edge `E` between faces `F1` and `F2` has a unit tangent `t(p)` oriented
  **as the coedge of `F1`**.

### 1.2 Convexity

The edge is **convex** at `p` iff

```
(n1 × n2) · t > 0          n_i = n_{F_i}(p), t oriented along F1's coedge
```

concave iff `< 0`, and smooth (tangent faces) iff `n1 × n2 = 0`. INFERRED;
checked on a box: top face `n1 = +z`, front face `n2 = −y`, the top face's
counter-clockwise loop runs along `+x` on the front edge, and
`(z × −y)·x = +1`, which is convex, as it should be.

- Onshape's `EdgeConvexityType` has a fourth value, `VARIABLE`, for an edge
  whose convexity changes along its length (DOCUMENTED, Onshape FS note). ACIS
  refuses such edges with `BL_NON_U_CVXTY` and asks the user to split them
  (DOCUMENTED, ACIS note). The same test gives it: the sign of
  `(n1 × n2)·t` changes along the edge.
- The sign test is an exact-predicate candidate. Near zero the edge is nearly
  smooth and the fillet nearly vanishes (section 3.2). Decide with the
  filtered or exact path and return "smooth or undecidable" rather than
  guessing.

### 1.3 Ball side and oriented offsets

- The ball of a **convex** edge lies inside the material; it removes material
  (a *round*). The ball of a **concave** edge lies outside the material; it
  adds material (a *fillet*). DOCUMENTED (ACIS `…ad`, Rossignac thesis
  property 3.35).
- The **ball-side normal** of face `F_i` is `m_i = −n_i` for a convex edge and
  `m_i = +n_i` for a concave edge. It points from the surface toward the ball
  centre.
- The **oriented offset** of face `F_i` by `r` is `O_i = { p + r·m_i(p) }`.
  Dahl's thesis handles the same choice by oriented surfaces and signed ball
  radii (DOCUMENTED, Dahl §2.2, Fig. 2.2): the ball is placed where its
  orientation agrees with both surfaces.

### 1.4 Two semantics of "fillet"

- **Global (morphological)**, Rossignac & Requicha (DOCUMENTED, Rossignac
  note):
  - rounding `R_r(S) = (S↓r)↑r`, the opening: the union of all balls of
    radius `r` inside `S`;
  - filleting `F_r(S) = (S↑r)↓r`, the closing.
  - Properties: `R_r(S) ⊂ S ⊂ F_r(S)`, idempotence, `R_a(R_r S) = R_r S` for
    `a ≤ r`.
  - Side effects: global rounding disconnects thin necks (< 2r), global
    filleting bridges gaps (< 2r) between disjoint features and fills slots.
- **Edge-local (what CAD does)**: only the selected edges are blended; the ball
  touches exactly the two faces of the edge (plus overflow rules, section 10).
  This is Onshape/Parasolid, ACIS, OCCT.
- **Relation (INFERRED, from the Rossignac note):** away from the edge ends,
  and when the ball fits, the edge-local fillet equals the boundary of
  `R_r(Q)` (convex) or `F_r(Q)` (concave) for the local wedge `Q` at the edge.
  That makes the global operators a **test oracle** for the local operation.
  They are not the semantics wonky should implement for `opFillet`.

### 1.5 Vocabulary

Wonky should use the shared vocabulary of Parasolid, ACIS and Onshape so that
errors and docs line up with public material (DOCUMENTED terms, see the Vida,
ACIS and Parasolid notes):

| term | meaning |
|---|---|
| primary / support faces | the two faces being blended |
| spine | the path of the ball centre |
| spring curve / contact curve / trimline | where the blend touches a support |
| cross section / profile | the blend's curve in a plane transverse to the spine |
| cross curve | the blend's boundary where it stops (setback plane, cap face) |
| range | a blend's distance from a support (two ranges = asymmetric) |
| terminal / internal vertex | one / several blended edges end there |
| bi-blend | two blends meeting tangentially at a vertex |
| miter | two blends meeting non-tangentially |
| end cap / side cap | a face that terminates a blend / trims one side of it |
| setback | distance from a vertex at which an edge blend is stopped |
| overflow (smooth, cliff, cliff-end, notch) | Parasolid's names for a blend leaving its support faces |
| cliff edge | an existing edge that forms a blend boundary without tangency |

## 2. Constant-radius rolling-ball blends

### 2.1 Construction

For supports `S1`, `S2` with ball-side normals `m1`, `m2` and radius `r`
(DOCUMENTED as the standard construction: Choi-Ju note, Kós-Martin-Várady
§3.2 Fig. 6, Dahl Remark 2.1, ACIS `…bg`, Parasolid FD §29.2):

1. **Offsets.** `O_i = S_i + r·m_i`.
2. **Spine.** `s(t) ∈ O1 ∩ O2`. For each spine point there are parameters
   `(u_i, v_i)` with `S_i(u_i, v_i) + r·m_i(u_i, v_i) = s(t)`.
3. **Contacts.** `P_i(t) = s(t) − r·m_i(u_i(t), v_i(t))`. They come with their
   surface parameters, i.e. they are exact pcurves up to the accuracy of the
   spine.
4. **Section.** The characteristic circle of the ball at `s(t)` is the great
   circle in the plane through `s(t)` perpendicular to `s'(t)`. Both contacts
   lie on it: `s − P_i = r·m_i`, and `m_i ⟂ s'` because `s` moves on the
   offset `O_i`, whose normal at `s` is `m_i`. (INFERRED, standard.)
5. **Blend** = the shorter arc of the characteristic circle from `P1` to
   `P2` ("the portion of the pipe between the spring curves with smaller arc
   length", DOCUMENTED ACIS `…bg`).

The whole ball envelope is a **pipe surface**
`F(t, v) = s(t) + r·(cos v·N(t) + sin v·B(t))` with `(T, N, B)` the Frenet
frame of the spine (DOCUMENTED, Patrikalakis-Maekawa-Cho 11.6).

### 2.2 The exact cross-section arc

With `a = (P1 − s)/r`, `b = (P2 − s)/r`, `cos θ = a·b` (`θ` is the arc angle;
section 3 shows it equals the angle between the face normals):

- control points `P1`, `T`, `P2` with the apex
  `T = s + r·(a + b)/(1 + a·b)`, the intersection of the two contact tangents
  in the section plane, at distance `r/cos(θ/2)` from `s`;
- weights `(1, w, 1)` with `w = cos(θ/2) = sqrt((1 + a·b)/2)`;
- `B(σ) = [(1−σ)²P1 + 2σ(1−σ)w·T + σ²P2] / [(1−σ)² + 2σ(1−σ)w + σ²]`.

DOCUMENTED (Choi-Ju note, citing Lee 1987; the same arc is in monstertruck's
`ContactCircle`). The arc is exact for every `θ < π`. A single rational
quadratic cannot represent `θ ≥ π`; fillet arcs are always `< π` because
`θ < π` (section 3).

- Wonky has `Circle` curves already, so a cross curve that is an arc needs no
  rational form in the kernel. The rational form matters for (a) conic
  profiles (section 9), (b) NURBS export of non-analytic blends, and (c) the
  G1 end conditions of n-sided corner patches.

### 2.3 Existence conditions

A blend of radius `r` exists and is a regular surface when all of these hold.
Each is a named failure when it does not (section 10).

1. **Regular offsets.** The offset of `S_i` toward the ball must not have a
   cusp in the contact region:

   ```
   1 − r·κ_i > 0   for both principal curvatures κ_i of S_i,
   κ measured positive when S_i bends toward the ball
   ```

   DOCUMENTED as the offset singularity condition `κ = −1/d` (Patrikalakis
   11.3.1-11.3.2) and as ACIS's "geometric limitation on the blend radius"
   (a convex support whose radius is below the blend radius makes the spring
   curve loop; ACIS fails). For wonky's surfaces this is a scalar test
   (INFERRED):
   - plane: always true;
   - cylinder or cone of radius `ρ` with the ball **inside** it (`m` points to
     the axis): `r < ρ` (for a cone, `ρ` is the local radius divided by the
     cosine of the half-angle, the principal radius of curvature, evaluated
     over the contact region);
   - ball outside a cylinder or cone: always true;
   - sphere of radius `ρ`, ball inside: `r < ρ`;
   - torus: the tightest principal radius toward the ball, which is the minor
     radius (tube side) or `major − minor` on the inner equator
     (Patrikalakis note, "κmax is attained on the inner equator").
2. **The offsets intersect.** `O1 ∩ O2` must be non-empty near the edge. It
   is empty when, for example, the ball is larger than the available gap
   (a plane and a cylinder whose offsets miss each other).
3. **The pipe is regular on the used arc.** The pipe `F(t, v)` above has
   `|F_t × F_v| = r·|1 − r·κ_s(t)·cos v|·|s'|` (standard canal-surface
   Jacobian). With `v` measured from the spine's principal normal `N`
   (toward the spine's centre of curvature), the used arc must satisfy

   ```
   r·κ_s(t)·cos v < 1    for every v on the arc from P1 to P2
   ```

   DOCUMENTED for the whole pipe as "local self-intersection iff r·κ ≥ 1"
   (Patrikalakis 11.6; Dahl Thm 3.26). The **restriction to the used arc** is
   INFERRED and matters: remus found that the old bound `r ≤ ρ/2` for an inside
   plane/cylinder torus "refused sound geometry" because the used quarter tube
   never reaches the self-intersecting part of a spindle torus (DOCUMENTED,
   remus note). Section 4.6 works this out.
4. **No global self-intersection.** Two distant parts of the pipe must not
   meet: spine self-distance `> 2r` between non-neighbouring parameters,
   plus end-circle checks (DOCUMENTED, Patrikalakis 11.6.3 body/body,
   end/body, end/end).
5. **Contacts stay on their faces.** `P_i(t)` must lie inside face `F_i` for
   every `t` of the edge. When it does not, the blend overflows (section 10.3).

### 2.4 The general (non-closed-form) solver

For pairs outside the symmetric families the spine has no closed form. Two
documented residual systems solve one section at a time:

- **OCCT `BlendFunc_ConstRad`** (DOCUMENTED, OCCT note, LGPL, ideas only).
  Unknowns `(u1, v1, u2, v2)`; guide point `G(t)` on a guide curve, section
  plane normal `ν = G'/|G'|`:
  - `E1 = ν·(P1 + P2)/2 − ν·G(t) = 0`: the contact midpoint lies in the
    section plane;
  - `E2..4 = P1 + r·(ν·n1·ν − n1)/|ν × n1| − P2 − r·(ν·n2·ν − n2)/|ν × n2| = 0`:
    the centres computed from both contacts, with normals projected into the
    section plane, coincide.

  Newton per section, marching along `t` (`BRepBlend_Walking`).
- **monstertruck contact circle** (DOCUMENTED, monstertruck note, Apache-2.0,
  portable). For a point `p` on the edge and current contacts `p0`, `p1` with
  normals `n0`, `n1`:
  - solve the 3×3 linear system with rows `(e', n0, n1)` (edge tangent, then
    the two normals) and right-hand side
    `(e'·p, n0·p0 − s·r, n1·p1 − s·r)` for the centre `c`;
  - target contacts `q_i = c + s·r·n_i`;
  - project each surface onto its target by one Gauss-Newton step with the
    first fundamental form, `[Su·Su Su·Sv; Su·Sv Sv·Sv]·Δ = [Su·d, Sv·d]`;
  - iterate (up to 100 times in monstertruck).

  v-derivatives of any order come from differentiating the linear system by
  Leibniz expansion (DOCUMENTED, `der_routine`).
- **Kós-Martin-Várady inner projection** (DOCUMENTED, Kós note §3.2.3): move a
  point onto the spine by `x ← x + α·v1 + β·v2` with
  `[1 g; g 1]·[α β]ᵀ = [r − d1, r − d2]ᵀ`, `g = v1·v2`, then slide along
  `v1 × v2`. Its sensitivity `dc/dR = (v1 + v2)/(1 + v1·v2)` is the spine's
  derivative with respect to the radius, useful for radius sweeps and for the
  "largest radius that fits" diagnostic.

**Section-plane choice matters.** OCCT and monstertruck put the section plane
perpendicular to a guide (the original edge). The rolling-ball definition puts
it perpendicular to the spine. They coincide in both symmetric families
(section 4) and differ in general. For constant radius the surface is the same
pipe either way; only its parametrisation differs. For variable radius the
choice changes the geometry (section 8). INFERRED.

**Bend fit** (INFERRED, consistent with the notes): the per-section work is
small, uniform and branch-light (3×3 or 4×4 solves, surface evaluation), so
sample sections at fixed `t`, solve each independently (fork-join or GPU
lanes), certify chord deviation between samples, and subdivide failing
intervals. That replaces the sequential marcher. The existence tests of
section 2.3 are per-sample and should run before any construction.

### 2.5 Certification oracle for any constant-radius blend

Independent of how a blend was built (INFERRED from the Kós and Choi-Ju
notes; the maximum-ball residual is DOCUMENTED in Kós §3.3):

- sample points `x` on the blend face; for each, the ball centre is
  `c = x + r·N_blend(x)` (with the blend normal pointing to the ball side);
- assert `dist(c, S1) = dist(c, S2) = r` (to tolerance), with the closest
  points inside `F1`, `F2`;
- assert the blend normal equals `m_i` at the contacts (G1);
- the plane/plane closed form of the maximum-ball radius (DOCUMENTED, Kós
  §3.3.1, elimination INFERRED there):
  `(R−d1)² − 2g(R−d1)(R−d2) + (R−d2)² = (1−g²)R²`, larger root.

This catches wrong side, wrong spine, wrong radius and wrong trim without
reusing construction code.

## 3. The dihedral angle

Let `θ ∈ [0, π)` be the angle between the face normals at the edge point,
`cos θ = n1·n2 = m1·m2` (the `m`s differ from the `n`s by the same sign), and
`φ = π − θ` the opening angle of the wedge the ball sits in (the material
angle for a convex edge, the air angle for a concave one).

### 3.1 Plane/plane quantities

With `e` a point on the edge (INFERRED; the centre formula MEASURED in
`tmp/fillet/theory-checks.mjs`):

| quantity | formula | note |
|---|---|---|
| ball centre | `c = e + r·(m1 + m2)/(1 + m1·m2)` | satisfies `m_i·(c − e) = r`; no trig |
| centre distance from the edge | `r/cos(θ/2) = r/sin(φ/2)` | Onshape `findRadiusToOffsetRatio` uses `1/cos(θ/2)` (DOCUMENTED) |
| contact distance along each face | `r·tan(θ/2) = r·cot(φ/2)` | at 90° this is `r` |
| contact chord ("width") | `r·|m1 − m2| = 2r·sin(θ/2)` | Onshape converts width to radius by `radius = width/|n0 − n1|` (DOCUMENTED) |
| arc angle | `θ` | |
| arc length | `r·θ` | |
| section area between the corner and the arc | `r²·(tan(θ/2) − θ/2)` | MEASURED at `θ = 60°` (0.0537514 sampled vs 0.0537515) |
| volume removed or added along a straight edge of length `L` | `L·r²·(tan(θ/2) − θ/2)` | at 90°: `L·r²(1 − π/4)` |

Numerically stable forms (INFERRED): `tan(θ/2) = |n1 × n2|/(1 + n1·n2)`,
`cos(θ/2) = sqrt((1 + n1·n2)/2)`. No `acos` is needed except for the arc
angle itself, and the rational arc of section 2.2 needs only `cos(θ/2)`.

**A documented bug to avoid.** remus computed the contact setback from half
the normal angle where it needed the wedge half-angle. The two coincide only
at 90°; on a 178.9° ridge the contacts landed about `100·r` away instead of
about `0.01·r` (DOCUMENTED, remus note). Write every formula in terms of `m1`,
`m2` as above and test at 10°, 90°, 170° and 179°.

### 3.2 What the angle does

- **Sharp edges** (`θ → π`, wedge `φ → 0`, a knife edge): contacts run away as
  `r·tan(θ/2) → ∞`. The fillet needs ever wider faces; it overflows or fails
  with `FILLET_FACE_RANGE_TOO_LARGE` long before the formulas degenerate.
  The largest radius that fits a face of available width `w` is
  `r_max = w/tan(θ/2)`. INFERRED; this is also the useful diagnostic value
  ("radius 3 does not fit; 2.4 would").
- **Nearly smooth edges** (`θ → 0`): the fillet shrinks to nothing:
  contact distance `≈ r·θ/2`, section area `≈ r²θ³/24`. The blend is
  numerically delicate (two nearly equal normals) and topologically delicate
  (the fillet face is a sliver tangent to both supports). An exactly smooth
  edge has nothing to fillet: Onshape reports `FILLET_FAIL_SMOOTH` "Could not
  fillet smooth edges" (DOCUMENTED, Onshape FS note).
- **Right angle**: every quantity simplifies (`r`, `r·√2`, `π/2`); this is the
  dominant FDM case and must never be the only test angle.
- **Chamfer width** depends on the chamfer definition (section 5): for
  `FACE_OFFSET` it shrinks as the dihedral opens, for in-face distances it does
  not (DOCUMENTED, ACIS and Parasolid notes).
- **Convex vs concave with the same `θ`**: the section geometry is identical;
  only the side of the ball, the offset direction, the Boolean sign
  (remove vs add), and the curvature condition of section 2.3 change.

### 3.3 Convex vs concave in practice

| | convex edge (round) | concave edge (fillet) |
|---|---|---|
| ball | inside material | outside material |
| `m_i` | `−n_i` | `+n_i` |
| effect | removes material | adds material |
| offset regularity (section 2.3) bites when | a support curves toward the inside of the material, e.g. the top edge of a thin boss (ball inside the cylinder: `r < ρ`) | a support curves toward the air, e.g. the floor edge of a blind hole (ball inside the hole: `r < ρ`) |
| global side effect (section 1.4) | can consume faces and obliterate holes | can fill slots and bury small features |
| terminal-vertex capping (section 6.1) | an extended tool that leaves the body removes nothing, so over-extension is harmless when the neighbours are also convex | an extended tool that leaves the body adds material, so the blend must be cut by the cap face |

Plane/cylinder convexity is easy to get wrong; remus records it as a real
bug: reading the cylinder's `reversed` flag alone as "concave" (DOCUMENTED,
remus note). The convexity of section 1.2 decides, and the table below is its
consequence:

| configuration | edge | ball |
|---|---|---|
| top edge of a boss (cylinder's own end cap) | convex | inside the cylinder |
| rim of a through hole | convex | outside the hole cylinder |
| base of a post standing on a plate | concave | outside the post cylinder |
| floor edge of a blind hole | concave | inside the hole cylinder |

DOCUMENTED (remus `analytic.rs:798-814` table); the ball column INFERRED.

## 4. Analytic special cases

### 4.1 The two symmetry theorems

A constant-radius pipe is a cylinder iff its spine is a line, a torus iff its
spine is a circle, and a sphere iff the spine degenerates to a point.
(DOCUMENTED, ACIS `…bg`: "a straight-line spine gives a cylinder, a
circular-arc spine a torus, a point spine a sphere".) So the question "when is
a fillet analytic" is "when is `O1 ∩ O2` a line or a circle".

**Translation family (INFERRED, standard).** A surface is invariant under
translation along a unit direction `d` if it is a plane containing `d` or a
cylinder with axis parallel to `d`. If both supports are invariant under the
same `d`:

- their offsets are invariant too (offsets commute with the translation);
- their intersection, and therefore the spine, is a union of lines parallel
  to `d`;
- the whole construction is the extrusion along `d` of a 2D fillet in a plane
  perpendicular to `d`;
- the fillet is a **cylinder** of radius `r` with axis parallel to `d`; the
  contacts are lines; a chamfer is a **plane**.

Pairs: plane/plane (`d = n1 × n2`, always); plane/cylinder with the axis
parallel to the plane (`a·n = 0`); cylinder/cylinder with parallel axes.

**Rotation family (INFERRED, standard).** A surface is invariant under
rotation about an axis line `A` if it is a plane perpendicular to `A`, or a
cylinder, cone or torus with axis `A` (the same line, not only a parallel
one), or a sphere whose centre lies on `A`. If both supports are invariant
about the same `A`:

- the spine is a union of circles about `A` (parallels);
- the construction is the revolution about `A` of a 2D fillet in the meridian
  half-plane;
- the fillet is a **torus** with axis `A`, major radius = the radial coordinate
  of the 2D arc centre, minor radius `r`; a **sphere** when that radial
  coordinate is zero; the contacts are circles; a chamfer is a **cone** (a
  plane when the chamfer segment is perpendicular to `A`, a cylinder when it
  is parallel).

Common axes: plane + any coaxial surface → that surface's axis; plane + sphere
→ the line through the centre along the plane normal (always exists); sphere +
sphere → the line through both centres (always exists); sphere + cylinder,
cone or torus → that axis iff the centre lies on it; cylinder/cone/torus pairs
→ iff their axes are the same line.

**Evidence that this is the complete analytic list** (DOCUMENTED): Kós et al.
§4 table ("the blend is a cylinder: plane–plane (any angle); plane–cylinder
with axis ∥ plane; cylinder–cylinder with parallel axes. Torus: plane–sphere;
plane–{cylinder, cone, torus} with axis ⟂ plane; sphere–{cylinder, cone,
torus} with the sphere centre on the axis; coaxial {cylinder, cone, torus}
pairs"), Shene 1998 Thm 16 ("two cones can be blended by a torus if and only
if their axes are identical"), and OCCT's `ChFi3d_KParticular` table, which is
a subset. The claim that nothing outside the two families has a line or
circle spine is INFERRED; no counter-example is known.

**Degenerate spines.** A plane/cylinder pair whose plane contains the axis is
in the translation family. Its rotation-family look-alike, a plane containing
a torus or cone axis, is **not**: the offset plane no longer contains the axis
and the spine becomes a spiric or conic section. The same trap applies to
line edges in general: **a line edge does not imply a cylinder fillet.** A
plane through a cone's apex cuts the cone in generator lines, but the offset
plane misses the offset cone's (shifted) apex, the spine is a conic, and the
fillet is a pipe around a conic (INFERRED).

### 4.2 The 2D fillet solver

Both families reduce to one 2D problem: a circle of radius `r` tangent to two
oriented primitives in a plane. Primitives (INFERRED; each case is a textbook
construction, and Kós §4.3 gives the same bisector view):

- a **line** `{x : ν·x = δ}` with unit `ν` pointing to the ball side;
- a **circle** `{x : |x − q| = ρ}` with `σ = +1` if the ball is outside it,
  `σ = −1` if inside.

Offsets: line → `ν·x = δ + r`; circle → `|x − q| = ρ + σ·r`. The offset
circle must have positive radius: `σ = −1` needs `r < ρ` (section 2.3,
condition 1; equality is a degenerate case, see below).

Centre `c` = intersection of the two offsets:

| pair | solve | failure / degeneracy |
|---|---|---|
| line/line | 2×2 linear: `[ν1; ν2]·c = [δ1 + r; δ2 + r]` | `det = ν1 × ν2 → 0`: parallel lines, a smooth edge |
| line/circle | parametrise the offset line `x(s) = p0 + s·τ` (`p0 = (δ + r)ν`, `τ ⟂ ν`); `s² + 2s·τ·(p0 − q) + |p0 − q|² − (ρ + σr)² = 0` | discriminant `< 0`: the offsets miss, no spine; `= 0`: tangent offsets |
| circle/circle | offset radii `R_i = ρ_i + σ_i r`, `d = |q2 − q1|`, `a = (d² + R1² − R2²)/(2d)`, `h² = R1² − a²`, `c = q1 + a·u ± h·u⊥` | `h² < 0`: no spine; `d = 0`: concentric, no edge |

- **Root choice.** Two roots are the normal case (a line cuts a circle
  twice). Take the root whose contacts lie on the actual face segments
  adjacent to the corner `e` (the 2D image of the edge), i.e. whose ball sits
  in the wedge at `e`. Nearest-to-`e` is the usual heuristic (OCCT takes the
  intersection "closest to the spine start", DOCUMENTED); the contact-on-face
  test is the correct criterion and doubles as the range check.
- **Contacts.** Line: `c − r·ν`. Circle: `q + ρ·(c − q)/|c − q|` (the same
  formula for both `σ`).
- **Arc.** The arc of the circle `(c, r)` between the contacts that faces `e`.
  Its angle equals the angle between the primitives' ball-side normals at
  the contacts.

Extrusion (translation family): the fillet is the cylinder through `c` with
axis `d`, radius `r`; the contact lines are the contacts extruded along `d`.

Revolution (rotation family), in the meridian half-plane with coordinates
`(ρ, h)` (radial, axial):

- torus centre = axis origin `+ h_c·a`, axis `a`, **major `= ρ_c`, minor `= r`**;
- contact circles: the parallels at the two contacts' `(ρ, h)`;
- **sphere** when `ρ_c = 0` (radius `r`, centre on the axis);
- `ρ_c < 0` means the ball crosses the axis: refuse;
- regularity on the used arc (section 2.3, condition 3, specialised; see 4.6):
  every point of the used arc must have `ρ > 0`, except a single touching
  point on the axis in the sphere case.

### 4.3 Plane/plane

- Always the translation family, for any angle. Fillet: **cylinder**, axis
  `c + λ·t` with `c = e + r·(m1 + m2)/(1 + m1·m2)`, radius `r`. Contacts:
  lines `c − r·m_i + λ·t`. DOCUMENTED (OCCT `FilPlnPln`:
  `C = Pv + (R/cos(θ/2))·normalize(D1 + D2)`, which is the same point).
- Chamfer: **plane** (section 5).
- Representation today: exact (`Cylinder`, `Line`). End cross curves: a
  `Circle` arc when the cap face is a plane perpendicular to the edge, an
  `Ellipse` arc for an oblique planar cap (the plane/cylinder section,
  `kernel/analytic.bend` `plane_cylinder`), a quartic for a cylindrical cap
  that is not coaxial (not representable; section 11).
- FDM: box edges, `roundX` in `fixtures/r10b/r10b.fs` (DOCUMENTED, Onshape FS
  note), every edge of an extruded polygon.

### 4.4 Plane/cylinder

Three configurations (DOCUMENTED as a list in the Kós §4 table and the OCCT
eligibility table; the oblique case in the Choi-Ju note and Dahl Thm 2.6):

1. **Axis parallel to the plane** (plane normal `⟂` axis; the edge is a
   generator line; the plane at distance `δ < ρ` from the axis cuts the
   cylinder in two lines, `δ = ρ` is tangent): translation family,
   line/circle 2D solve, **cylinder** fillet. OCCT `FilPlnCyl` line overload:
   offset the cylinder to `ρ ± r`, fail if the concave case gives `r ≥ ρ`
   ("the fillet does not pass"), intersect with the offset plane, take the
   line closest to the spine start (DOCUMENTED).
2. **Axis perpendicular to the plane** (the cap edge, a circle): rotation
   family, **torus** or **sphere**. Closed form (DOCUMENTED, OCCT
   `FilPlnCyl` circle overload; signs INFERRED): plane at height `h0`,
   cylinder radius `ρ`, axis `a`.
   - `σ_h = sign(m_plane·a)` (ball above or below the plane), `σ_r = +1` if
     the ball is outside the cylinder (`m_cyl` points away from the axis).
   - Centre height `h0 + σ_h·r`; **major `= ρ + σ_r·r`**, minor `r`.
   - Contacts: circle of radius `ρ + σ_r·r` on the plane at height `h0`;
     circle of radius `ρ` on the cylinder at height `h0 + σ_h·r`.
   - `σ_r = −1` (boss top, blind-hole floor): valid iff `r < ρ` for a torus;
     `r = ρ` gives a **sphere** (OCCT switches to a sphere when
     `|ρ − r| ≤ Precision::Confusion()`, DOCUMENTED); `r > ρ` fails.
   - `σ_r = +1` (hole rim, post base): always a ring torus.
   - `ρ/2 < r < ρ` with `σ_r = −1` gives a **spindle torus** (major < minor).
     It is valid because the used band never reaches the self-intersection
     (section 4.6), but see section 11.2 for the STEP consequence.
3. **Oblique axis**: the edge is an ellipse; offset plane ∩ offset cylinder is
   an **ellipse** spine; the fillet is a pipe around an ellipse, which is not
   analytic. DOCUMENTED (Kós §3.2.5: plane/cylinder spines are conics;
   Dahl Thm 2.6: the plane/cone blend, cylinders included as cones with the
   apex at infinity, is rational of minimal bidegree (4, 2)).
   - Contact on the plane: the spine ellipse translated by `−r·m_plane`, an
     ellipse (DOCUMENTED, Choi-Ju note citing Dahl-Krasauskas eq. 2.10).
   - Contact on the cylinder: the spine point scaled radially from
     `ρ ± r` to `ρ`; because every spine point is at radius `ρ ± r`, the
     scaling factor is constant, so the contact is an affine image of a planar
     ellipse, i.e. a planar **ellipse** (INFERRED, derivation in the Choi-Ju
     note).
   - So both trim curves are types wonky has (`Ellipse`); only the surface is
     new. FDM: a boss or hole meeting a sloped face, a pipe through an
     inclined wall.

### 4.5 Plane/cone, cylinder/cylinder, cylinder/cone, cone/cone

- **Plane/cone.** Plane perpendicular to the cone axis: rotation family, 2D
  line/line in the meridian plane, **torus** (or sphere). OCCT `FilPlnCon`
  does exactly this (DOCUMENTED). Every other plane: the spine is a conic
  (ellipse, parabola or hyperbola, DOCUMENTED Kós §3.2.5, Dahl §2.3), the
  fillet is a rational pipe of bidegree (4, 2) (DOCUMENTED, Dahl Thm 2.6 for
  the ellipse; the hyperbolic and parabolic cases "can be derived using the
  same approach"). Wonky has no `Hyperbola` or `Parabola` curve; the hybrid
  Boolean plan already lists the plane/cone hyperbola as an Unresolved cause
  (hex-nut; DOCUMENTED, `docs/hybrid-boolean-plan.md` §2.3).
- **Cylinder/cylinder, "coaxial vs crossed".**
  - Coaxial cylinders of different radii never share an edge; equal radii are
    the same surface. So "coaxial cylinder/cylinder" has no fillet; its
    rotation-family relatives are cylinder/plane (cap edges), cylinder/cone
    and cylinder/torus.
  - **Parallel axes**: translation family, 2D circle/circle, **cylinder**
    fillet. FDM: vertical edges between arc segments of an extruded profile.
  - **Crossed axes (intersecting)**: the edge is a space quartic in general
    (two ellipses when the radii are equal, the Steinmetz case). The spine is
    the intersection of the two **offset** cylinders, radii `ρ1 ± r` and
    `ρ2 ± r`. It is a pair of planar ellipses iff the offset radii are equal
    and the axes intersect; otherwise a space quartic (INFERRED from the
    Steinmetz fact applied to the offsets). Equal offset radii happen for a
    concave tee of equal pipes (`ρ + r` on both sides) but not for a
    cross-drilled hole in a boss unless `ρ_boss − ρ_hole = 2r`.
    - With two points of oriented contact the blend is rational of minimal
      bidegree (6, 2); with one, (12, 2) (DOCUMENTED, Dahl §2.6, cones
      including cylinders).
    - Dahl's classification: fixed-radius blends of natural quadrics are
      rational **for every r** only in four configurations: plane/cone,
      cone/cone with two or with one point of oriented contact, cone/sphere
      with one point of oriented contact (DOCUMENTED, Dahl §1.1.1, §2.7).
      INFERRED consequence: a general unequal-radius tee has no rational
      blend; it must be approximated with a certified tolerance or refused.
    - remus refuses cross-drilled cylinder/cylinder rim fillets (DOCUMENTED,
      remus README); OCCT routes all cylinder/cylinder to walking (DOCUMENTED).
  - **Skew axes**: quartic spine, not rational in general (INFERRED).
- **Cylinder/cone, cone/cone.** Coaxial: rotation family, **torus**
  (DOCUMENTED, Kós table; Shene Thm 16). Otherwise quartic or conic spines as
  above.
- **Dupin cyclides are not constant-radius fillets.** A cyclide blending two
  cones with a common inscribed sphere is a *variable*-radius rolling-ball
  blend with circular trims (DOCUMENTED, Dupin note: Chandru-Dutta-Hoffmann
  p. 14, Shene Thm 16). Using one for `opFillet` would not reproduce Onshape's
  geometry. They are relevant for an explicit "transition" feature and for
  corner patches (Dahl 2014 uses one at a heterogeneous corner), not for
  constant-radius fillets.

### 4.6 Sphere and torus supports; the spindle-torus bound

- **Plane/sphere**: always rotation family (axis through the centre along the
  plane normal): **torus** (or sphere). The spine is a circle (DOCUMENTED,
  Kós §3.2.5 lists plane-sphere as a conic spine; Kós §4: torus).
- **Sphere/sphere**: always rotation family (axis through both centres):
  2D circle/circle, **torus** or sphere. monstertruck tests its generic
  rolling-ball surface against the closed form of exactly this case
  (DOCUMENTED, `tests/rbf_surface.rs`).
- **Sphere/cylinder, sphere/cone, sphere/torus**: torus iff the sphere centre
  is on the axis; otherwise a space quartic spine (the proto recover code
  already refuses the off-axis sphere/cylinder *intersection* as "a space
  quartic (curve type missing)", DOCUMENTED `kernel/proto/recover/geom.bend`).
- **Plane/torus**: torus iff the plane is perpendicular to the torus axis.
  A plane containing the axis cuts the torus in meridian circles, but the
  fillet is not a torus (section 4.1, degenerate spines). This is the
  "fillet of a fillet" case: e.g. a second fillet between a plate and an
  earlier cap-edge fillet.
- **Torus/cylinder, torus/cone, torus/torus**: torus iff coaxial.

**The used-arc bound for an inside torus (INFERRED; matches remus's
DOCUMENTED argument).** For `σ_r = −1` the spine circle has radius
`M = ρ − r` and curvature `κ_s = 1/M`; the principal normal points to the
axis. The used arc runs from the plane contact (the section direction along
the axis, `cos v = 0`) to the cylinder contact (radially outward,
`cos v = −1`). So `r·κ_s·cos v ≤ 0 < 1` on the whole used arc for every
`M > 0`. Equivalently, every point of the used band has radial coordinate
`M − r·cos v ≥ M > 0`. The self-intersecting part of a spindle torus
(`M + r cos v' < 0` in the outward convention) lies on the inner side of the
tube, which the fillet never uses. Hence the correct admission bound is
`r < ρ` (plus `r = ρ` as the sphere), not `r ≤ ρ/2`.

### 4.7 Case table

Legend for the last column: **today** = representable with wonky's current
types; **+T/S** = needs `Torus` and/or `Sphere`; **+pipe** = needs a
non-analytic pipe surface (procedural or rational B-spline); **+curve** = also
needs a curve type wonky lacks.

| supports | configuration | spine | fillet | contacts | chamfer | wonky |
|---|---|---|---|---|---|---|
| plane/plane | any angle | line | cylinder | lines | plane | today |
| plane/cylinder | axis ∥ plane | line | cylinder | lines | plane | today |
| plane/cylinder | axis ⟂ plane (cap edge) | circle | torus; sphere at `r = ρ` inside | circles | cone | +T/S (chamfer today) |
| plane/cylinder | oblique | ellipse | pipe, rational (4,2) | ellipses | rational ruled | +pipe |
| plane/cone | axis ⟂ plane | circle | torus / sphere | circles | cone | +T/S (chamfer today) |
| plane/cone | other planes | conic | pipe, rational (4,2) | conics | rational ruled | +pipe, +curve (hyperbola, parabola) |
| plane/sphere | any | circle | torus / sphere | circles | cone | +T/S |
| plane/torus | plane ⟂ axis | circle | torus / sphere | circles | cone | +T/S |
| plane/torus | other | spiric (quartic) | pipe | quartics | ruled | +pipe, +curve |
| cylinder/cylinder | parallel axes | line | cylinder | lines | plane | today |
| cylinder/cylinder | crossed, equal offset radii | two ellipses | pipe, rational (6,2) | quartics | ruled | +pipe, +curve |
| cylinder/cylinder | crossed or skew, general | quartic | pipe, not rational in general | quartics | ruled | +pipe (approximate), +curve |
| cylinder/cone, cone/cone | coaxial | circle | torus / sphere | circles | cone / plane / cylinder | +T/S (chamfer today) |
| cylinder/cone, cone/cone | other | conic or quartic | pipe | | ruled | +pipe, +curve |
| sphere/sphere | any | circle | torus / sphere | circles | cone | +T/S |
| sphere/{cyl, cone, torus} | centre on axis | circle | torus / sphere | circles | cone | +T/S |
| sphere/{cyl, cone} | centre off axis | quartic (rational for one oriented contact point, (8,2)) | pipe | | | +pipe, +curve |
| torus/{cyl, cone, torus} | coaxial | circle | torus / sphere | circles | cone | +T/S |

Sources: section 4.1-4.6 (DOCUMENTED Kós, OCCT, Dahl, Shene; INFERRED
completeness).

## 5. Chamfers

### 5.1 Three definitions of "distance"

Chamfers are simpler than fillets geometrically (a ruled surface between two
contact curves) and harder semantically, because kernels disagree on what the
distance measures (DOCUMENTED, ACIS note §2, Parasolid FD §29.2.2, Onshape
help):

| definition | contacts | who |
|---|---|---|
| **face offset** | offset the supports by `d1`, `d2` toward the chamfer side, intersect the offsets (a spine, as for fillets), project the spine back onto each support | Parasolid ("offset surfaces … intersected; the resulting curves … projected"), Onshape `ChamferMethod.FACE_OFFSET` (the default, UI "Offset"), ACIS R10 and R17-advanced as "two balls of different radii rolling together" |
| **in-support distance** | the contact on each face lies at distance `a_i` from the edge, measured in that face | ACIS R17 standard chamfer; Onshape `APEX_RANGE` (UI "Tangent", "measured from the intersection of the tangent of the two adjacent faces") |
| **distance + angle** | distance `a` on one face, chamfer at angle `α` to that face | Onshape `OFFSET_ANGLE` (bounds 0.1° to 179.9°, default 45°) |

The mapping of Onshape's two methods onto the kernel definitions is INFERRED
(Onshape FS and help notes). For planar faces at 90° all definitions agree;
off 90° and on curved supports they differ. Which of Onshape's `width1` /
`width2` belongs to which face under `TWO_OFFSETS` must be probed with the
Onshape bridge, as must `APEX_RANGE` on curved faces (HEARSAY that it projects
tangent-line points onto the faces; not documented anywhere read).

### 5.2 Plane/plane formulas

In the section plane, edge at the origin, face 1 along the positive x axis,
face 2 along `(cos φ, sin φ)`, the chamfer on the wedge side (`φ` the wedge
angle, section 3). INFERRED derivation; the face-offset and distance-plus-angle formulas are MEASURED numerically in `tmp/fillet/theory-checks.mjs`:

- **Face offset** `d1`, `d2`: the spine point is `(x, d1)` with
  `x·sin φ − d1·cos φ = d2`, so the in-face contact distances are

  ```
  s1 = (d2 + d1·cos φ)/sin φ     on face 1
  s2 = (d1 + d2·cos φ)/sin φ     on face 2
  ```

  - Symmetric `d`: `s = d·cot(φ/2) = d·tan(θ/2)`. At 90°, `s = d`; the chamfer
    narrows as the dihedral opens, which is Parasolid's documented behaviour.
  - At 90° the offset of face 1 appears as the in-face distance on face 2.
    Naming must be pinned by an oracle.
  - **Undefined chamfer**: `s1 ≤ 0` iff `d2 ≤ −d1·cos φ`, which can only happen
    for an obtuse wedge (`φ > 90°`) and `d2/d1 ≤ |cos φ|`. This is Parasolid's
    "if there is a great difference between the ranges … the chamfer is not
    defined at all" (Fig. 29-5) as a formula.
- **In-support** `a1`, `a2`: contacts at `(a1, 0)` and `a2·(cos φ, sin φ)`
  directly.
- **Distance + angle** `a`, `α`: contact 1 at `(a, 0)`; the chamfer line leaves
  it at angle `α` to face 1 (the triangle's interior angle at contact 1);
  contact 2 is its intersection with face 2:
  `a2 = a·sin α / sin(φ + α)`, valid iff `0 < α < π − φ` (law of sines in the
  triangle edge, contact 1, contact 2, whose angles are `φ`, `α` and
  `π − φ − α`). At 90° and 45° this gives `a2 = a`.
- The chamfer surface is the **plane** through the two contact lines. It is
  not tangent to either support ("In general, chamfer blends are not tangent
  continuous with the faces adjoining the original edge", DOCUMENTED Parasolid
  §29.2).

### 5.3 The families

- **Translation family**: contacts are two lines parallel to `d`, so the
  chamfer is a **plane**. The 2D contacts come from the same line/line,
  line/circle, circle/circle offsets as section 4.2 with the ranges `d1`, `d2`
  in place of `r` (face offset), or from arc length along the 2D primitives
  (in-support).
- **Rotation family**: the chamfer segment in the meridian half-plane from
  `(ρ1, h1)` to `(ρ2, h2)` revolves into a **cone** with half-angle
  `α = atan2(ρ2 − ρ1, h2 − h1)` measured from the axis; a **plane** (annulus)
  when `h1 = h2`, a **cylinder** when `ρ1 = ρ2`. Cap-edge chamfers of holes
  and bosses, the most common FDM chamfer (the 45° countersink-like edge),
  are cones. DOCUMENTED as OCCT's `ChPlnCyl` → cone or plane and `ChPlnCon` →
  cone; ACIS limits standard chamfers to plane and cone.
  - Wonky's `Cone{origin, axis, x, radius, angle}` holds this exactly.
    Put `origin` at the axis point at `h1`, `radius = ρ1`, and the half-angle
    with the sign convention of `kernel/analytic.bend` (confirm whether
    `angle` is signed before implementing).
- **Everything else**: the chamfer is the ruled surface joining corresponding
  contact points. For the oblique plane/cylinder face-offset chamfer the two
  contacts are planar ellipses (section 4.4), and the correspondence through
  the rationally parametrised spine ellipse is rational, so the chamfer is a
  rational ruled surface of bidegree (2, 1) (INFERRED). It needs a B-spline
  or ruled-surface type; it is not a quadric in general.

### 5.4 Representation today

Every chamfer of the two symmetric families is representable **today**:
planes, cones, cylinders, with line and circle trims. This is the cheapest
complete tier of the whole fillet/chamfer feature, and for FDM (45° chamfers
on down-facing edges to avoid overhangs) it is as important as fillets
(INFERRED, Onshape help note: "Chamfers matter as much as fillets").

## 6. Vertex blends

### 6.1 Terminal vertices: one blended edge ends

The blend runs until the ball stops rolling onto the faces it meets and is
trimmed there by a **capping face** (DOCUMENTED, ACIS `…ca`). For each end:

- **Cap face perpendicular to the edge** (Marc's `roundX`: X-parallel edges of
  a box end at the ±X faces): the cross curve is the blend surface cut by the
  cap plane, a **circular arc** for a cylinder fillet. The cap face loses a
  corner and gains the arc. Exact today.
- **Oblique planar cap**: cylinder ∩ plane is an **ellipse** arc
  (`plane_cylinder` in `kernel/analytic.bend`). Exact today. For a torus
  fillet cut by a plane the section is a circle only when the plane contains
  the axis or is perpendicular to it; otherwise a spiric quartic
  (DOCUMENTED as a refusal reason in `kernel/proto/recover/geom.bend`,
  "plane/torus section is a spiric curve").
- **Curved cap**: cylinder fillet ∩ non-coaxial cylinder is a space quartic
  (not representable).
- **Capping by extension.** When the end face does not reach the blend (the
  blend is wider than the end face locally, typical at mixed-convexity
  vertices), the cap face's carrier is extended until it cuts the blend
  (DOCUMENTED, ACIS: "Extending capping faces"; Parasolid: "extending at most
  two of the adjoining faces"). For analytic carriers extension is free (the
  carrier is unbounded); for B-spline carriers it is a known failure source
  (`FILLET_REQUIRES_SURFACE_EXTENSION`, Parasolid `bsurf_c`).
- **Convexity decides whether over-extension is harmless** (INFERRED; section
  3.3): a convex blend's removal region extended beyond a convex end face lies
  in the air and removes nothing, so a Boolean construction does not need an
  exact cap there; a concave blend's added region extended beyond the end face
  adds material in the air, so it must be cut by the end face's half-space;
  a convex blend ending at a **concave** corner would cut into the neighbouring
  material if extended, so it must be capped exactly (this is the
  mixed-convexity capping that ACIS special-cases, DOCUMENTED `…ca`).

Parasolid: one blended edge at a 3-edge vertex "normally possible", failing
when "the end surface is undefined"; at a vertex with more edges only if the
ranges are small enough that the blend ends on edges at that vertex
(DOCUMENTED, Parasolid FD §29.3-29.4).

### 6.2 Two blended edges at a vertex

- **Tangent (bi-blend)**: the edges continue each other with G1 faces; the two
  blends share the characteristic circle at the vertex and "mate exactly"
  (DOCUMENTED, ACIS `…se`). See section 7.
- **Mitered**: the edges meet at an angle, both of the **same convexity**.
  The two blend surfaces are cut along their mutual intersection, the miter
  curve. For two equal-radius cylinder fillets whose axes intersect (two
  top edges of a box meeting at a corner whose vertical edge stays sharp) the
  two cylinders have equal radii and intersecting axes, so they meet in
  **planar ellipses** in the bisector planes (INFERRED, the Steinmetz fact);
  the miter is an `Ellipse` arc, exact today. ACIS uses a "curved miter" for
  constant rounds on coplanar straight or circular edges and requires at most
  two other, non-smooth edges (DOCUMENTED). Parasolid: two of three edges at
  a vertex are legal only if both add or both remove material (DOCUMENTED
  §29.4). Whether Onshape's result equals the intersection miter must be
  checked with an oracle.
- **Mixed convexity** (one convex, one concave): not unique. ACIS refuses to
  fix a mixed-convexity miter in one step; the order in which the user
  applies the blends gives two different valid shapes (DOCUMENTED, ACIS
  `…ve`, Figs. 1-33/1-34). Parasolid returns `PK_blend_fault_edge_c`
  (`FILLET_ADJOINING_EDGE_NOT_FILLETED`) for mixed two-of-three. Wonky should
  refuse with a "non-unique; sequence the fillets" error.

### 6.3 Blend meeting a sharp edge of opposite convexity: the horn torus

A common FDM case: a rectangular boss on a plate, the concave base edges
filleted, the boss's vertical (convex) edges left sharp. At the vertex where a
vertical edge meets the plate, the ball rolling along one base edge must get
round the sharp convex edge to the next base edge.

- By the closing definition (section 1.4) the ball stays outside the material,
  touching the plate and the **edge line** itself while it pivots. Its centre
  is at height `r` above the plate and at distance `r` from the edge line, so
  it moves on a circle of radius `r` about the edge line (INFERRED).
- The envelope is a **horn torus** (major radius = minor radius = `r`) with the
  vertical edge as its axis, used over the exterior angle of the corner
  (90° of sweep for a right-angled boss). It is tangent to the plate, meets
  both base-edge cylinders G1 along their end cross circles, and touches the
  vertical edge at a single point at height `r`, where the horn torus is
  singular.
- DOCUMENTED support: ACIS entity-entity blending allows exactly one
  "stationary blend", "the osculating torus of a plane against a line normal
  to it", and vertex-face geometry is "only the torus against a plane"
  (ACIS note §9). Parasolid's `vx_blend_data` smooths blends "past sharp
  edges of opposite convexity" (DOCUMENTED §30.3.8). Whether Onshape
  produces the horn torus by default is HEARSAY; it needs an oracle fixture.
- If the sharp edge is **not perpendicular** to the plate, the centre locus is
  offset plane ∩ cylinder of radius `r` about the edge line, an ellipse: a
  pipe around an ellipse, not a torus (INFERRED).
- The dual case: convex rounds on the top edges of an L-shaped extrusion
  meeting at a sharp **concave** vertical edge give the same horn torus with
  the ball inside the material.
- Representation: `Torus` with major = minor, plus a degenerate vertex where
  the torus touches its axis. STEP needs care (section 11.2).

### 6.4 Three or more blended edges: the sphere corner

**Planar corner** (DOCUMENTED as OCCT `ChFiKPart_Sphere`, Parasolid "a piece
of sphere at the vertex", ACIS "simple vertex blend surfaces … spheres, tori";
the linear system is from the Várady-Rockwood note):

- all faces at the vertex planes `n_i·x = d_i`, all blended edges the same
  radius `r`, uniform convexity (all convex or all concave);
- the centre `c` solves `m_i·c = m_i·p_i + r` for every face (`p_i` on face
  `i`), i.e. `n_i·c = d_i − r` for convex, `d_i + r` for concave;
- valence 3: a 3×3 solve, solvable whenever the three normals are independent
  (a genuine corner);
- valence ≥ 4: overdetermined; a sphere exists iff the offset planes share a
  point (true for symmetric pyramids, false in general). Decide by an exact
  rank test on the plane coefficients (Várady-Rockwood note);
- the corner face is a **spherical polygon** bounded by the edge fillets'
  cross curves. Each edge cylinder's axis passes through `c` (its axis is the
  locus at distance `r` from its two planes on the ball side, and `c` is on
  it), so each cylinder is tangent to the sphere along the **great circle** in
  the plane through `c` perpendicular to that axis. The corner is bounded by
  arcs of those great circles; for a box, a spherical octant with three 90°
  arcs.

**Curved corners** (INFERRED generalisation): for any three faces blended
pairwise with the same `r` and uniform convexity, the three spines
`O1∩O2`, `O2∩O3`, `O1∩O3` meet at the point `O1∩O2∩O3` (three equations,
three unknowns; generically isolated). The ball there touches all three faces,
and each edge blend's characteristic circle at that point is a great circle of
that ball. So the sphere corner exists whenever the point exists and the three
great-circle arcs bound a proper spherical triangle (angles below `π`). This
covers, for example, a box corner where one edge was already a cylinder fillet
of the same radius. Check the triangle condition explicitly; OCCT implements
only the planar case (DOCUMENTED).

**Oracle.** Rounding all edges of a convex polyhedron with one radius equals
`(S↓r) ⊕ ball(r)` (Minkowski sum of the inner parallel body with a ball;
Rossignac: `S = R_r(S) ⇔ S = A↑r`). For an `a×b×c` box,
`V = a'b'c' + 2r(a'b' + b'c' + a'c') + πr²(a' + b' + c') + (4/3)πr³` with
`a' = a − 2r` etc. (DOCUMENTED formula in the Rossignac note, from the Steiner
formula).

Representation: `Sphere` surface plus great-circle `Circle` arcs; the vertices
where three arcs meet are the contact points. Needs `Sphere` (not in
production today).

### 6.5 Unequal radii, mixed convexity, valence ≥ 4: setback patches

No sphere fits when the radii differ or convexity is mixed. The options,
cheapest first:

1. **Sequential blending (order semantics).** Blend the edges one feature at
   a time; later blends see earlier blend faces as supports. Parasolid and
   ACIS both document that results depend on the order and that overlapping
   blends that fail together can succeed one after another (DOCUMENTED:
   Parasolid `overlap_c`, ACIS "Vertex Blend Order"). This is how most
   Onshape users build parts anyway (one fillet feature per radius), and it
   **stays analytic in the common FDM case**. INFERRED example: an extruded
   rounded rectangle (vertical edges already arcs of radius `R_v`, i.e.
   cylinder faces) whose top edges are then filleted with `r`:
   - along the flat sides: plane/plane → cylinders;
   - around each corner: top plane / vertical cylinder, axis perpendicular to
     the plane → a cap-edge torus with major `R_v − r` (ball inside, convex);
   - a **sphere** when `r = R_v`; **refuse or overflow** when `r > R_v`
     (condition 1 of section 2.3; what Onshape does there is HEARSAY and a
     fixture);
   - the chain cylinder → torus → cylinder is G1 (section 7).
2. **Setback vertex blend** (Várady-Rockwood; ACIS `VBL_SURF`; Parasolid
   setbacks). Each edge blend is stopped at a setback distance from the
   vertex by a cross curve; the hole is filled by one multi-sided patch.
   - Boundary structure: up to `2n` sides, `n` cross (profile) curves
     alternating with `n` spring curves on the primary faces; a
     uniform-convexity vertex gives `n` sides (the springs shrink to points),
     a mixed one more (DOCUMENTED, ACIS and the Geomagic patent via the
     Várady-Rockwood note).
   - **No-setback rule** (DOCUMENTED, ACIS): intersect each edge's spring
     curves with the neighbouring edges' spring curves, take the intersection
     farther from the vertex, put the cross curve through it: "the smallest
     practical setback". INFERRED planar formula: on a face where edge `e1`
     (spring line at distance `s1 = r1·tan(θ1/2)` inside the face) and edge
     `e2` (spring line at `s2`) meet at angle `β`, the spring lines cross at
     distance `x = (s2 + s1·cos β)/sin β` along `e1` from the vertex; take the
     larger `x` of `e1`'s two faces.
   - **Setback plane**: perpendicular to the edge through the point at the
     setback distance; its section of a constant-radius blend is a circular
     arc (DOCUMENTED, ACIS). Oblique setbacks tilt it.
   - **Patch**: an n-sided transfinite surface interpolating position and
     cross-boundary derivative ("ribbons") on every side. The classic form is a
     convex combination of linear Taylor interpolants,
     `Σ_k W_k(p)·(C_k(s_k(p)) + d_k(p)·D_k(s_k(p)))` with Charrot-Gregory
     weights `W_k = Π_{j≠k} d_j² / Σ_m Π_{j≠m} d_j²` (Choi-Ju note; the exact
     domain mapping is unverified there). ACIS adds a **bulge** factor in
     `[0, 2]` for interior fullness, 0 suggested for mixed convexity
     (DOCUMENTED).
   - Guarantees: G1 only as good as the ribbon compatibility at the corners;
     no fairness or non-self-intersection guarantee (DOCUMENTED, Choi-Ju and
     Várady-Rockwood notes). ACIS exports the patch as `n` four-sided
     B-splines (DOCUMENTED).
3. **Explicit refusal** with the Onshape names:
   `FILLET_VERTEX_EDGES_COMPLICATED` for complex vertices (Parasolid
   `vertex_c`: some 4-valent vertices and valence ≥ 5 unless every edge is
   blended), `FILLET_ADJOINING_EDGE_NOT_FILLETED` for illegal two-of-three.

Representation: a setback patch is a **new non-analytic surface type**
(Gregory or multi-sided Bézier, exported as B-splines). It can satisfy wonky's
"approximations need explicit tolerances" rule only if the patch is *exact by
definition*: its defining data (ribbons, weights, bulge) is the model, and
there is no "true" surface being approximated (INFERRED, Várady-Rockwood
note). Every other kernel with open source stops here: OCCT fills unequal
corners with approximated Plate/Coons surfaces, monstertruck has no corner
logic, ogeom-rs discards the corner state (DOCUMENTED, Várady-Rockwood note).

## 7. Edge chains and tangent continuation

- **Chains.** A fillet request on one edge normally extends to the maximal
  chain of edges connected G1 (tangent-continuing) with it ("The fillet is
  automatically extended to all edges in a smooth continuity with the original
  edge", DOCUMENTED OCCT guide; OCCT's `ChFiDS_Spine`). Onshape makes this
  `tangentPropagation`: default **false** in `opFillet` and in the
  programmatic `fillet(...)` defaults, but **true** in the UI (DOCUMENTED,
  Onshape FS note). Wonky must report which edges a propagation added.
- **The ACIS six situations** are a precise propagation rule at each vertex of
  a candidate chain (DOCUMENTED, ACIS `…sm`):

  | situation | at the vertex | result |
  |---|---|---|
  | 1 | exactly two tangent-continuing non-smooth edges, same convexity | continue; the vertex disappears from the blend |
  | 2 | two tangent-continuing edges of different convexity | stop |
  | 3 | two non-smooth edges not tangent-continuing, needing a G1-discontinuous face without an edge | unsupported |
  | 4 | more edges: the two same-convexity edges continue, the rest are smooth "slant" edges | continue; blend faces join G1 across iso-parametric cross edges where the springs hit the slant edges |
  | 5 | as 4 but some other edges are non-smooth | stop; miter where the springs meet the unblended edges |
  | 6 | no tangent-continuing edge | stop |

- **Why a tangent chain is G1** (INFERRED): at a shared vertex of two
  tangent-continuing edges, the supports on each side are G1 across the
  vertex, so both blends have the same ball there, and both are tangent to
  that ball along the same characteristic circle. Two surfaces tangent to one
  sphere along one circle are G1 along it. The join is **not G2** in general
  (a cylinder meets a torus with a curvature jump across the circle).
- **Supports change along the chain** (situation 4). The top-edge chain of a
  rounded rectangle keeps the top plane on one side while the other side
  changes plane → cylinder → plane across smooth slant edges. The blend
  changes type (cylinder → torus → cylinder) at cross circles where the
  springs cross the slant edges. Each piece is analytic; the pieces meet along
  exact circles. That is the most common FDM fillet chain, and it is
  representable with `Cylinder` + `Torus` + `Circle`.
- **Closed chains.** A circular cap edge is one closed edge; its torus fillet
  is a full band with a seam. The seam needs care (OCCT #1371: a closed rim
  with a seam vertex returned a self-intersecting solid while reporting
  success, DOCUMENTED). A closed chain of several edges (the top of a rounded
  rectangle) has no end caps at all ("periodic" in ACIS terms when it has no
  miters or vertex blends).
- **Radius along a chain.** A constant-radius request keeps `r` across the
  chain. Different radii on consecutive tangent edges need a variable-radius
  transition or a vertex treatment; Parasolid's `range_c`
  (`FILLET_RANGE_INCONSISTENT_EDGE`) is the fault when radii clash at a
  vertex with a tangent third edge (DOCUMENTED).
- **Convexity along a chain** must stay uniform (situation 2 stops). An edge
  whose own convexity changes is `VARIABLE` and must be split (section 1.2).

## 8. Variable radius

### 8.1 Canal surfaces

A variable-radius rolling-ball blend is the envelope of spheres with centre
`m(t)` and radius `r(t)` (DOCUMENTED, Lukács note via Peternell-Pottmann eqs.
2.1-2.4 and Dahl ch. 3):

- sphere `(x − m)² − r² = 0`, envelope condition `(x − m)·ṁ + r·ṙ = 0`;
- the characteristic circle is a **small** circle of the sphere, in a plane
  perpendicular to `ṁ` offset from the centre; the tangent cone half-angle
  `φ` satisfies `sin φ = ṙ/|ṁ|` (DOCUMENTED, Dahl p. 53);
- **reality**: the envelope exists iff `|ṁ|² − ṙ² > 0` (a radius ramp faster
  than the spine advances collapses the section). Evaluate it as
  `(|ṁ| − ṙ)(|ṁ| + ṙ)` to avoid cancellation (Lukács note);
- **regularity**: Dahl eq. 3.45, `|r| < Λ1/(cos θ − Λ1Λ2)` for all `t`, `θ`,
  reducing to `r·κ_spine < 1` for constant `r`;
- **G1 / G2 between canal pieces**: iff their curves `(m(t); r(t))` in
  Minkowski space `R^{3,1}` share tangent lines (G1) or are G2 (DOCUMENTED,
  Dahl §3.3).

The spine is no longer an offset intersection ("a variable offset is
ill-defined on a surface", DOCUMENTED ACIS `…bg`): it is a curve on the
**bisector** of the two supports, the set of centres of spheres in oriented
contact with both (Dahl p. 9-10: a 2-dimensional surface in `R^{3,1}`;
choosing a radius law is choosing a curve on it).

### 8.2 How the radius law is attached

- Onshape: radii at vertices and at points on the edge by arc length
  (`vertexSettings`, `pointOnEdgeSettings`), `smoothTransition`; zero radius
  allowed only at the ends of a chain (`VRFILLET_INTERNAL_ZERO`); bounds
  `[0, 500] m` (DOCUMENTED, Onshape FS note). The interpolation law between
  the given radii is not documented (HEARSAY; it needs probing).
- ACIS: radius as a function of the **edge** parameter; the ball of radius
  `r(v)` has its centre in the plane perpendicular to the edge at `v`
  (DOCUMENTED). OCCT `BlendFunc_EvolRad` does the same with a guide.
- Consequence (INFERRED): the section plane follows the edge, not the spine,
  so the same law on the same edge gives different surfaces in different
  kernels unless the spine is a translate of the edge. Pin the definition and
  compare to Onshape.
- Parasolid VRB rules (DOCUMENTED): radii at ≥ 2 points including both
  vertices; zero allowed at the ends, not in the middle; not on an edge
  without vertices; rho all zero or all non-zero.

### 8.3 Exact special cases

- **Linear radius along a straight plane/plane edge** (INFERRED): the centres
  lie on a line in the bisector plane (distance `r(t)/sin(φ/2)` from the edge),
  and the radius is linear in the position along that line, so the envelope
  of the spheres is a **right circular cone** whose axis is the centre line.
  The cone is tangent to both planes (every sphere is), and the contacts are
  lines through the cone apex. `Cone` holds it exactly **today**. This only
  holds if the kernel's radius law is linear in arc length along the edge;
  Onshape's default law must be checked first.
- **Rotation family with a radius varying around the axis**: not analytic.
- **Dupin cyclides** are variable-radius blends with circular trims between
  cones with a common inscribed sphere (DOCUMENTED, Dupin note). They are
  exact rational biquadratic patches, but their radius law is imposed by the
  geometry, not chosen by the user, so they do not implement Onshape's
  variable fillet.
- Everything else: a canal surface, rational only if `m` and `r` are rational
  (Dahl Lemma 3.6 / Alg. 3.8, DOCUMENTED via the Lukács note), otherwise
  approximated.

### 8.4 Failure modes specific to variable radius

- ramp too steep (`|ṙ| → |ṁ|`): the section collapses (DOCUMENTED);
- snapshot and sliding-disc surfaces leave "a slight crease" across a
  G1-but-not-G2 support edge (DOCUMENTED, ACIS `…bg`);
- OCCT routes all variable radius through walking with no closed form;
  monstertruck rejects closed wires with `f(0) ≠ f(1)` (DOCUMENTED).

Priority for FDM: low. Constant-radius plane/plane and cap-edge fillets
dominate (DOCUMENTED as a judgement in the OCCT and Lukács notes).

## 9. Cross-section profiles
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

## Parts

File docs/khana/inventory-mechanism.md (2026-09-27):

# cad_khana inventory: the mechanism side

Workflow `khana-design`, task `inv-mechanism` (2026-09-24). Scope: everything in
cad_khana that composes assemblies and checks them relationally:
`src/cad_khana/mechanism/**` (assembly, assertions, check, diagnostics, pick,
hints), `core/tessellation.py`, `_paths.py`, the mechanism-relevant CLI and
diff code, the mechanism tests, the README and the mechanism parts of the
skill. Printability (`inspect`, FDM, bores, ...) and tooling (viewer, draw,
export, environment) have their own inventories; they appear here only where
the mechanism code calls them.

Evidence legend used in every section:

- **[C]** read in code (file:line given);
- **[M]** measured by running the installed `khana` 0.0.2 on copies in
  `tmp/khana/oracle/` (the parity oracle; it never feeds the kernel);
- **[I]** inference from code or geometry, not run.

Path abbreviations:

| prefix | path |
| --- | --- |
| `U/` | `~/Workspace/cad/cad-khana/src/cad_khana/` (upstream source, read only) |
| `UT/` | `~/Workspace/cad/cad-khana/tests/` |
| `B/` | `~/.local/share/uv/tools/cad-khana/lib/python3.13/site-packages/build123d/` (build123d 0.10.0 in the installed tool) |
| `W/` | `<repo>/python/cad_khana/` (wonky's compat package) |
| `O/` | `<repo>/tmp/khana/oracle/` (oracle scripts and outputs) |

## 0. Provenance and versions

- Upstream git HEAD is `22f0ad0` (2026-06-11, "skill: document warnings +
  contact ratio") [M: `git log -1`]. The working tree is **not clean**:
  `src/cad_khana/mechanism/pick.py` and `tests/mechanism/test_pick.py` are
  untracked, `cli.py` is modified (+55 lines, only the `khana pick` command)
  and `skills/cad-khana/SKILL.md` is modified (+39 lines: the "Review loop"
  section and a fit-test label bullet) [M: `git status`, `git diff --stat`].
  pick is therefore local, uncommitted work in Marc's checkout (file mtime
  2026-06-12), not a released cad_khana feature.
- The installed tool (`uv tool`, receipt `directory = .../cad/cad-khana`) is
  version 0.0.2 and is an older snapshot: its `cad_khana/mechanism/` has no
  `pick.py` and its CLI has no `pick` command [M: `ls` of the tool's
  site-packages]. The installed skill `~/.claude/skills/cad-khana/SKILL.md`
  likewise lacks the "Review loop" section (upstream `SKILL.md:119-137`) [M:
  diff].
- Tool venv: build123d 0.10.0, cadquery_ocp 7.8.1.1.post1 (OCCT 7.8),
  ocp_tessellate 3.3.0 [M: dist-info names]. `pyproject.toml` pins only
  `build123d>=0.8`, Python `>=3.13,<3.14` [C: `pyproject.toml`]. wonky's
  build123d shim follows build123d 0.13; the numeric behavior below is 0.10.0.
- There is no `__init__.py` anywhere in upstream `src/cad_khana` (PEP 420
  namespace packages) [C: file listing].

## 1. Module map

| file | lines | public names | role |
| --- | --- | --- | --- |
| `U/mechanism/assembly.py` | 341 | `PlacedPart`, `RevoluteJoint`, `SubAssembly`, `DetailOverride`, `Assembly` | immutable assembly builder, joints, overrides, flattening |
| `U/mechanism/assertions.py` | 100 | `NoInterference`, `Clearance`, `ExpectedInterference`, `Assertion`, `evaluate` (+ `_intersection_volume`, `_placed`) | declared relational checks and their evaluation |
| `U/mechanism/check.py` | 64 | `check`, `CheckResult` (+ `_export_default`, `_set_export_default`) | coordination: export, evaluate, compute, write `mechanism.json`, exit |
| `U/mechanism/diagnostics.py` | 123 | `SCHEMA_VERSION`, `INTERFERENCE_VOLUME_EPSILON_MM3`, `BBox`, `PartDiagnostics`, `Interference`, `AssertionResult`, `Diagnostics`, `compute` (+ `_placed`, `_bbox`, `_part_diagnostics`, `_interference`) | per-part facts and all-pairs interference |
| `U/mechanism/hints.py` | 44 | `match_hint` (+ `_PATTERNS`) | regex repair hints for crashed scripts |
| `U/mechanism/pick.py` (uncommitted) | 104 | `describe_face`, `describe_edge`, `describe_vertex`, `face_relations` (+ `_EPS_DOT`, `_EPS_MM`, `_vec`, `_face`, `_edge`, `_vertex`) | viewer-index to geometry facts |
| `U/core/tessellation.py` | 32 | `TESSELLATION_TOLERANCE_MM`, `TESSELLATION_ANGULAR_TOLERANCE`, `Triangle` (+ `_triangle`, `_tessellate`) | triangle soup for printability (no mechanism caller) |
| `U/_paths.py` | 25 | `resolve_out` | `out=` anchoring |
| `U/cli.py` (mechanism parts) | 285 | `build`, `check`, `pick` commands, `_write_error_diagnostics`, `_run_script` | runs scripts, writes error `mechanism.json` |
| `U/diff.py` (mechanism parts) | 265 | `diff` (mechanism branch) | text diff of two `mechanism.json` |

## 2. Assembly model (`U/mechanism/assembly.py`)

All classes are `@dataclass(frozen=True)`; every builder method returns a new
object via `dataclasses.replace` [C: `assembly.py:15,24,64,87,102`].

| name | signature | semantics [C] |
| --- | --- | --- |
| `PlacedPart` | `(name: str, part: Part, location: Location, color: Color \| None = None, material: str \| None = None)` | a leaf: the unplaced part plus its placement (`assembly.py:15-21`). No validation of any field. |
| `RevoluteJoint` | `(axis: Axis, angle_deg: float = 0.0)` | single-DOF joint on a sub-assembly, axis in the parent's frame (`:24-36`). |
| `RevoluteJoint.with_angle` | `(angle_deg) -> RevoluteJoint` | copy with a new angle (`:38-39`). |
| `RevoluteJoint.transform` | property `-> Location` | `T(p) · R(d, angle) · T(-p)` built as `pivot * rotation * pivot.inverse()` with `rotation = Location((0,0,0), (dx,dy,dz), angle_deg)` (`:41-61`). At angle 0 it still builds the product (a float identity, not an exact one). |
| `SubAssembly` | `(name: str, assembly: Assembly, location: Location = Location(), joint: RevoluteJoint \| None = None)` | nested assembly placed in the parent frame (`:64-78`). |
| `SubAssembly.effective_location` | property | `location` without joint, `joint.transform * location` with one (`:80-84`): the joint rotates the already placed sub-assembly about an axis in the parent frame. |
| `DetailOverride` | `(part: Part, location: Location \| None = None, material: str \| None = None, color: Color \| None = None)` | one entry of `with_detailed_geometry` (`:87-99`). |
| `Assembly` | `(parts: tuple[PlacedPart,...] = (), subassemblies: tuple[SubAssembly,...] = (), assertions: tuple[Assertion,...] = ())` | the tree (`:102-106`). |
| `.with_part` | `(name, part, location=None, color=None, material=None)` | appends `PlacedPart(name, part, location or Location(), color, material)` (`:108-117`). Duplicate names are accepted silently. |
| `.with_subassembly` | `(name, assembly, location=None, joint=None)` | appends a `SubAssembly` (`:119-132`). |
| `.with_joint` | `(path: str, joint)` | dotted path (`"rotor.platform_dump"`), each segment resolved in its own frame; sets the leaf's joint; `KeyError(f"no sub-assembly named {head!r}")` if a segment is missing (`:134-158`). Every sub-assembly with the matching head name is updated (no uniqueness). |
| `.with_joint_angle` | `(path: str, angle_deg)` | as above, updates the angle; `ValueError("sub-assembly ... has no joint to update")` if the leaf has none, `KeyError` for a missing segment (`:160-189`). |
| `.with_materials` | `(mapping: dict[str,str])` | replaces `material` of every part whose name is a key, recursively (`:191-207`). |
| `.with_detailed_geometry` | `(mapping: dict[str, DetailOverride \| Part])` | bare `Part` means `DetailOverride(part=p)`; swaps recurse into the whole tree and keep placement/material/color unless the override gives them (`or` fallback, so an override can never clear a value to `None`); names not found anywhere are **additions** at the top level and need an explicit `location`, else `ValueError("with_detailed_geometry: addition ... requires an explicit location")` (`:209-264`). |
| `._swap_detail`, `._all_part_names` | private | helpers (`:247-270`). |
| `.assert_no_interference` | `(a, b, name=None)` | records `NoInterference(a, b, name or f"no_interference:{a}/{b}")` (`:272-278`). |
| `.assert_clearance` | `(a, b, min_mm, name=None)` | records `Clearance(a, b, min_mm, name or f"clearance:{a}/{b}>={min_mm}")` (`:280-293`). |
| `.assert_interference` | `(a, b, reason=None, name=None)` | records `ExpectedInterference(a, b, name or f"interference:{a}/{b}", reason)` (`:295-315`). |
| `.placed_parts` | property `-> tuple[PlacedPart,...]` | own parts first, then each sub-assembly's `placed_parts` with `location = eff * inner.location` (`:317-334`). This flat list is what every check uses. |
| `.compound` | property `-> Compound` | `Compound(children=[p.part.moved(p.location) ...] + [sub.assembly.compound.moved(sub.effective_location) ...])`, a nested compound tree (`:336-341`). Used by export. |

Module-level names that are importable from `assembly.py` only because they
are imported there: `Axis`, `Color`, `Compound`, `Location`, `Part`
(`assembly.py:5`) and `Assertion`, `Clearance`, `ExpectedInterference`,
`NoInterference` (`:7-12`).

Error behavior of the builder [C, M]:

- Assertions reference part **names** that are not checked at declaration.
  An unknown name is a `KeyError` at evaluation time inside `check()`
  (`assertions.py:42,56,81`) [M: `O/keyerror/`: `KeyError: 'ghost'`, status
  `error`, `hint: null`].
- Duplicate part names: `{p.name: ...}` dicts keep the last one
  (`assertions.py:99`, `diagnostics.py:116-117`), while all-pairs interference
  iterates the list, so a duplicate interferes with itself and is reported as
  `("a", "a")` [M: `O/probe/probe.json` `duplicate_names`:
  `parts_keys ["a"]`, `interferences [["a","a",500.0]]`].
- `part` can be any build123d shape. A `Face` "part" has volume 0, is
  `is_valid` true and never interferes [M: `probe.json` `face_as_part`].

## 3. Assertions (`U/mechanism/assertions.py`)

| name | semantics [C] | threshold |
| --- | --- | --- |
| `_intersection_volume(a, b)` | `a & b`; `None` -> 0.0; object with `.volume` -> that; else sum of member volumes (`:17-32`) | none |
| `NoInterference(a, b, name).evaluate(parts)` | passes iff `volume <= INTERFERENCE_VOLUME_EPSILON_MM3`; detail `"interference volume {v:.4f}mm^3"` (`:35-45`) | 0.001 mm³ (`diagnostics.py:13`) |
| `Clearance(a, b, min_mm, name).evaluate(parts)` | `dist = parts[a].distance_to(parts[b])`; passes iff `dist >= min_mm`; detail `"clearance {d:.4f}mm below min {min}mm"` (`:48-63`) | **no epsilon** |
| `ExpectedInterference(a, b, name, reason=None).evaluate(parts)` | passes iff `volume > 0.001`; detail `"expected interference absent (volume {v:.4f}mm^3)"` plus `"; reason: ..."` (`:66-88`) | 0.001 mm³ |
| `Assertion` | type alias `NoInterference \| Clearance \| ExpectedInterference` (`:91`) | |
| `_placed(p)` | `p.part.moved(p.location)` (`:94-95`) | |
| `evaluate(assembly)` | `parts = {p.name: _placed(p) for p in assembly.placed_parts}`; evaluates every assertion in declaration order (`:98-100`) | |

Notes [C/M]:

- For build123d `Part` inputs, `Part & Part` always returns a `Compound`,
  never `None`: `Compound.__and__` wraps any result (`B/topology/composite.py:506-513`;
  `Part` subclasses `Compound`, `composite.py:841`). The `None` branch in
  `_intersection_volume` and the `hint` about `a & b` returning `None`
  (`hints.py:12-15`) only apply to raw `Solid`s [M: `probe.json`
  `cube_states.*.and_type == "Compound"`, `solid_states.separated.and_type == "NoneType"`].
- `Compound.volume` sums the volumes of contained `Solid`s and `Shell`s
  (`composite.py:195-198`).
- Asserted pairs are intersected twice per `check()`: once in `evaluate`
  (`assertions.py:42/81`) and again in `compute` (`diagnostics.py:88`) [C].
- Failure texts round to 4 decimals, so a failing overlap of 4e-5 mm³ cannot
  occur (below epsilon) but a clearance failure can print `0.2000mm below min
  0.2mm` for `d = 0.19999999` [I from format strings].

## 4. `check()` (`U/mechanism/check.py`)

Signature: `check(assembly: Assembly, out: str | Path = "outputs", *, export: bool | None = None) -> CheckResult`
(`check.py:29-34`). `CheckResult(exports: tuple[Path,...], diagnostics: Diagnostics)` (`:15-18`).

Order of operations [C]:

1. `out_path = resolve_out(out)`; `mkdir(parents=True, exist_ok=True)` (`:35-36`).
2. Export first: `export_assembly(assembly, out_path)` when
   `export` (default: module global `_export_default`, which `khana check`
   sets to `False`, `cli.py:104-108`, `check.py:21-26,37-38`). So a failing
   check still leaves fresh `assembly.stl`/`assembly.step` (tested,
   `UT/mechanism/test_check.py:114-124`).
3. `evaluate_assertions(assembly)` (`:39`), `failed = any(not passed)` (`:40`).
4. `compute(assembly)` then `replace(..., exports=..., assertions=..., status="assertion_failed" if failed else "ok")` (`:41-46`).
5. Write `out/mechanism.json` as `json.dumps(asdict(diagnostics), indent=2) + "\n"` (`:47-49`).
6. `viewer.push(assembly)` if `khana view` enabled it; `draw.draw(...)` if
   `khana draw` enabled it (`:50-60`).
7. `raise SystemExit(1)` if any assertion failed (`:62-63`), else return.

Consequences [C/I/M]:

- `status` is only ever `"ok"` or `"assertion_failed"` from `check()`.
  Unasserted interferences do **not** affect it [M: `O/ok/outputs/mechanism.json`
  has two interferences and `status: "ok"`].
- `status: "error"` is written only by the CLI when the script raises
  (`cli.py:47-53,80-92`), into `--out` (default `<script dir>/outputs`,
  `cli.py:81-82`), **not** into the directory the script passed to
  `check(out=...)`. A script that checks into `checks/A-C0.20/` and later
  crashes leaves the previous run's `mechanism.json` there untouched [I].
- `SystemExit(1)` ends the script at the first failing `check()`. Scripts that
  loop `check()` over poses (`cad-project-003/.../preload_z/coupon.py:120-124`)
  report only up to the first failing pose [I]. The CLI re-raises
  `SystemExit` without printing anything (`cli.py:85-86`) [M:
  `O/fail/build.log` is empty, exit code 1].
- `khana check` means "no export", not "no geometry": `compute` still runs
  every pairwise Boolean [M: `O/check-mode/outputs/mechanism.json`
  `exports: []`, 5 parts].

## 5. Diagnostics (`U/mechanism/diagnostics.py`)

Constants: `SCHEMA_VERSION = "0.2"` (`:12`), `INTERFERENCE_VOLUME_EPSILON_MM3 = 0.001` (`:13`).

| dataclass | fields [C] |
| --- | --- |
| `BBox` | `min: (x,y,z)`, `max: (x,y,z)` (`:16-19`) |
| `PartDiagnostics` | `bbox`, `volume_mm3`, `surface_area_mm2`, `center_of_mass_mm`, `is_valid`, `face_count`, `edge_count`, `vertex_count` (`:22-31`) |
| `Interference` | `a`, `b`, `volume_mm3`, `centroid` (`:34-39`) |
| `AssertionResult` | `name`, `passed`, `detail = None` (`:42-46`) |
| `Diagnostics` | `schema_version = "0.2"`, `status = "ok"`, `error = None`, `hint = None`, `parts = {}`, `interferences = ()`, `assertions = ()`, `exports = ()` (`:49-58`) |

`compute(assembly) -> Diagnostics` (`:114-123`): places every part, computes
`_part_diagnostics` per name (dict: last duplicate wins), and
`_interference(a, b)` for every `itertools.combinations(placed, 2)` pair in
`placed_parts` order (so pairs read `housing/pin`, not assertion order) [M:
`O/ok`].

`_part_diagnostics(shape)` (`:73-84`) and the OCCT call under each field:

| field | build123d call | OCCT underneath [C] |
| --- | --- | --- |
| `bbox` | `bounding_box()` (`diagnostics.py:65-70`) | `BRepBndLib.AddOptimal_s` (`B/geometry.py:1098-1124`, `optimal=True` default); the `tolerance` argument does not enlarge an optimal box |
| `volume_mm3` | `Compound.volume` | sum of `BRepGProp.VolumeProperties_s` over solids and shells (`composite.py:195-198`, `shape_core.py:199-208,778-798`) |
| `surface_area_mm2` | `Shape.area` | `BRepGProp.SurfaceProperties_s` over all faces (`shape_core.py:313-320`) |
| `center_of_mass_mm` | `Compound.center()` (default `CenterOf.MASS`) | `VolumeProperties_s(...).CentreOfMass()` (`composite.py:563-590`) |
| `is_valid` | `Shape.is_valid` | `BRepCheck_Analyzer(...).IsValid()`, parallel (`shape_core.py:446-455`) |
| `face/edge/vertex_count` | `len(faces())` etc. | `TopExp_Explorer` deduplicated by `hash` (`shape_core.py:3000-3011`) |

`_interference(a, b)` (`:87-111`): `inter = placed(a) & placed(b)`; `None` ->
no row; a shape with `.volume` -> its volume and its own `center()`; a
`ShapeList` -> sum of volumes and the **largest** piece's center; drop if
`volume <= 0.001`. For `Part` inputs the result is always a `Compound`, so the
centroid is the mass centroid of **all** overlap pieces together, which for
two disjoint overlap regions lies between them, possibly outside both [C, I].

## 6. `mechanism.json` (schema 0.2)

Written by `check()` (`check.py:47-49`) and, on a script crash, by the CLI
(`cli.py:47-53`). Field order is the dataclass order. Floats are raw Python
`repr` (full precision, e.g. `5199.999999999999`); tuples become arrays.

```text
{
  "schema_version": "0.2",                      // string, constant
  "status": "ok" | "assertion_failed" | "error",
  "error": null | string,                        // full traceback text (error only)
  "hint": null | string,                         // match_hint(traceback) (error only)
  "parts": {                                     // {} on error
    "<leaf name>": {                             // placed_parts leaf name; duplicates collapse
      "bbox": {"min": [x,y,z], "max": [x,y,z]},  // mm, world frame, optimal box
      "volume_mm3": number,
      "surface_area_mm2": number,
      "center_of_mass_mm": [x,y,z],
      "is_valid": boolean,
      "face_count": int, "edge_count": int, "vertex_count": int
    }
  },
  "interferences": [                             // every pair with overlap > 0.001 mm^3
    {"a": name, "b": name, "volume_mm3": number, "centroid": [x,y,z]}
  ],
  "assertions": [                                // declaration order
    {"name": string, "passed": boolean, "detail": null | string}
  ],
  "exports": [absolute path string, ...]         // [] under `khana check` / export=False / error
}
```

There is no `kind` field (tested, `UT/mechanism/test_check.py:55-58`); `khana
diff` uses the absence of `kind` to recognize a mechanism file
(`U/diff.py:22-23`).

Real example, generated by the installed `khana build` on
`O/ok/assembly.py` (housing, lid face-touching on top, a pin through the
housing, an unasserted clip overlap, a lever in a sub-assembly on a 30°
revolute joint) [M], shortened to two of five parts:

```json
{
  "schema_version": "0.2",
  "status": "ok",
  "error": null,
  "hint": null,
  "parts": {
    "housing": {
      "bbox": {"min": [-20.0, -15.0, 0.0], "max": [20.0, 15.0, 20.0]},
      "volume_mm3": 24000.0,
      "surface_area_mm2": 5199.999999999999,
      "center_of_mass_mm": [-1.9942134277144827e-16, -3.5527136788005004e-17, 10.0],
      "is_valid": true, "face_count": 6, "edge_count": 12, "vertex_count": 8
    },
    "lever": {
      "bbox": {"min": [24.499999999999996, -2.0, 4.133974596215562],
               "max": [34.16025403784438, 2.0, 10.866025403784437]},
      "volume_mm3": 80.0, "surface_area_mm2": 136.0,
      "center_of_mass_mm": [29.33012701892219, 4.163336342344337e-18, 7.5],
      "is_valid": true, "face_count": 6, "edge_count": 12, "vertex_count": 8
    }
  },
  "interferences": [
    {"a": "housing", "b": "pin", "volume_mm3": 212.05750411731103,
     "centroid": [6.701415625141238e-17, -2.680566250056495e-16, 10.0]},
    {"a": "housing", "b": "clip", "volume_mm3": 31.999999999999993,
     "centroid": [19.000000000000004, -6.938893903907233e-18, 10.0]}
  ],
  "assertions": [
    {"name": "no_interference:lid/housing", "passed": true, "detail": null},
    {"name": "clearance:lever/housing>=0.5", "passed": true, "detail": null},
    {"name": "interference:pin/housing", "passed": true, "detail": null}
  ],
  "exports": [
    "<repo>/tmp/khana/oracle/ok/outputs/assembly.stl",
    "<repo>/tmp/khana/oracle/ok/outputs/assembly.step"
  ]
}
```

The full five-part file is `O/ok/outputs/mechanism.json`. Variants [M]:

- `O/fail/outputs/mechanism.json`: lid lowered 0.1 mm, pin moved away:
  `status: "assertion_failed"`, details `"interference volume 120.0000mm^3"`,
  `"clearance 0.0000mm below min 0.2mm"`, `"expected interference absent
  (volume 0.0000mm^3); reason: press-fit bore not modeled yet"`; exit 1, no
  stderr.
- `O/error/outputs/mechanism.json`: script crashes before `check()`:
  `status: "error"`, `error` = traceback, `hint: "Missing .part accessor — use
  ...p.part"`, `parts: {}`, `assertions: []`.
- `O/keyerror/outputs/mechanism.json`: assertion on an undeclared part:
  `status: "error"`, `KeyError: 'ghost'`, `hint: null`.
- `O/check-mode/outputs/mechanism.json`: `khana check`: `exports: []`, no STL/STEP.
- `O/diff-ok-fail.txt`: `khana diff` ok -> fail.

## 7. Hints (`U/mechanism/hints.py`)

`match_hint(error_text) -> str | None` returns the first matching hint
(`hints.py:40-44`). Only the CLI error path calls it (`cli.py:48-50`).

| # | regex (`hints.py`) | hint |
| --- | --- | --- |
| 1 | `NoneType.*has no attribute 'part'` (`:7-10`) | use `with BuildPart() as p: ...; return p.part` |
| 2 | `has no attribute 'volume'` (`:11-15`) | `a & b` returns None when solids don't overlap; guard or use `assert_no_interference()` |
| 3 | `TypeError.*Location` (`:16-20`) | `Location((x, y, z))` / `Location((x,y,z), (rx,ry,rz))` |
| 4 | `BRep_API: command not done\|BRepAlgo_BooleanOperation` (`:21-25`) | OCCT boolean failed; check validity, tolerances |
| 5 | `StdFail_NotDone` (`:26-30`) | fillet/chamfer radius too large |
| 6 | `No module named` (`:31-36`) | only build123d, bd_warehouse, cad_khana importable |

All six are OCCT/build123d-text specific; none maps a wonky capability error.

## 8. Pick (`U/mechanism/pick.py`, uncommitted) and `khana pick`

Constants: `_EPS_DOT = 1e-3` (`:20`), `_EPS_MM = 0.02` (`:21`); coordinates
rounded to 4 decimals (`_vec`, `:24-25`), areas/lengths to 3.

| name | semantics [C] |
| --- | --- |
| `describe_face(shape, index) -> dict` | `{"face", "geom": geom_type.name, "area_mm2", "center"}`; for `PLANE` also `"normal"` at the center and `"plane_offset_mm" = normal·center` (`:42-55`) |
| `describe_edge(shape, index) -> dict` | `{"edge", "geom", "length_mm", "mid", "start", "end"}` from `position_at(0.5/0/1)`; `LINE` adds `"direction"`, `CIRCLE` adds `"radius_mm"` (`:58-75`) |
| `describe_vertex(shape, index) -> dict` | `{"vertex", "position"}` (`:78-80`) |
| `face_relations(shape, indices) -> list[dict]` | for every pair: if both planar, `"angle_deg" = acos(\|na·nb\|)`, `"parallel" = \|\|cos\|-1\| < 1e-3`, if parallel `"normal_offset_mm" = na·(cb - ca)` and `"coplanar" = \|offset\| < 0.02`; always `"min_distance_mm" = fa.distance_to(fb)` (`:83-104`) |
| `_face/_edge/_vertex(shape, index)` | index into `ocp_tessellate.ocp_utils.get_faces/get_edges/get_vertices` (TopExp map order), which the comment says differs from build123d's `.faces()` order (`:28-39`) |
| `khana pick SCRIPT --part NAME [--faces i,j] [--edges k] [--vertices m]` | runs the script with `run_name="__khana_pick__"` (the `__main__` block does not run), collects every `Assembly` in the namespace, maps `placed_parts` by name (last wins), places the part and prints JSON (`cli.py:204-256`) |

Measured on `O/pick/pick_probe.py` (upstream `pick.py` copied, run in the
installed tool) [M, `O/pick/pick.json`]:

- Two top faces tilted 2° relative to each other, 30 mm apart: `parallel:
  true`, `normal_offset_mm: -0.003`, `coplanar: true`. At 3°: `parallel: false`.
  The parallel window is `acos(0.999) = 2.56°`, and coplanarity is judged at
  the two face centers only; the tilted 20 mm face deviates up to
  `10 · sin 2° = 0.35 mm` from the other plane [I].
- A cylinder face reports `geom: "CYLINDER"`, area and a "center" of
  `[-3, 0, 0]` for an r = 3 bore on the z axis: build123d `Face.center()`
  for a non-planar face is the surface point at the middle of the uv box
  (`B/topology/two_d.py:1450-1480`), not the centroid; no radius or axis is
  reported for cylinders.
- `describe_edge` of a full circle gives `start == end`, no center or axis.
- An out-of-range index raises a raw `IndexError`; the CLI prints a traceback,
  no JSON.
- On this part the viewer order equalled build123d's `.faces()` order; the
  difference the code comment claims was not reproduced [M].

## 9. `core/tessellation.py` and `_paths.py`

- `TESSELLATION_TOLERANCE_MM = 0.1`, `TESSELLATION_ANGULAR_TOLERANCE = 0.3`
  (`U/core/tessellation.py:7-8`); `Triangle(centroid, normal, area)` (`:11-15`);
  `_triangle(a, b, c)` (zero-area triangles keep a zero normal, `:18-25`);
  `_tessellate(part)` = `part.tessellate(0.1, 0.3)` mapped to `Triangle`s
  (`:28-32`). No mechanism code calls it; printability does.
- `resolve_out(out)` (`U/_paths.py:9-25`): absolute paths unchanged; relative
  paths anchored at `sys.modules["__main__"].__file__`'s directory; cwd-relative
  when there is no `__main__` file (REPL). Tested (`UT/test_cli.py:193-258`).

## 10. The OCCT calls and their numerical behavior

| step | call chain [C] | tolerance behavior |
| --- | --- | --- |
| interference / expected interference | `Shape.__and__` -> `intersect` -> `_bool_op(BRepAlgoAPI_Common)`, `SetRunParallel(True)`, then `ShapeUpgrade_UnifySameDomain` clean (`B/topology/shape_core.py:875-891,1328-1392,2109-2178`) | no `SetFuzzyValue` on Common (fuzzy is only set in fuse paths, `shape_core.py:1274`, `composite.py:492`); `IsDone`/`HasErrors` are never checked, so a failed Common yields whatever shape it has; OCCT's own confusion tolerance (1e-7) applies |
| volume | `BRepGProp.VolumeProperties_s` (OCCT numerical integration over the faces; not re-checked here) | no error bound is requested or reported [C] |
| clearance | `distance_to` -> `BRepExtrema_DistShapeShape` `LoadS1/LoadS2/Perform` with defaults, returns `Value()` (`shape_core.py:1120-1147`) | default deflection (Precision::Confusion); `InnerSolution()` is not consulted |
| bbox | `BRepBndLib.AddOptimal_s` | tight |
| validity | `BRepCheck_Analyzer` | OCCT defaults |

What the numbers do [M, `O/probe/probe.json`, `O/probe/probe2.json`]:

| configuration (10 mm cubes unless stated) | Common volume | `distance_to` | `no_interference` | `clearance(min>0)` | `assert_interference` |
| --- | --- | --- | --- | --- | --- |
| separated 10 mm | 0 | 10.0 | pass | pass if min ≤ 10 | fail |
| face touch | 0 | 0.0 | pass | fail | fail |
| edge touch | 0 | 0.0 | pass | fail | fail |
| vertex touch | 0 | 0.0 | pass | fail | fail |
| overlap 5 mm | 500 | 0.0 | fail | fail | pass |
| identical | 1000 | 0.0 | fail | fail | pass |
| 4 mm cube fully inside 20 mm cube (`Part`s) | 64 | **8.0** (InnerSolution false) | fail | **pass for min ≤ 8** | pass |
| same with raw `Solid`s | 64 | 0.0 (InnerSolution true) | fail | fail | pass |

So "interference" means "Common volume > 0.001 mm³". Touching of any kind
(face, edge, vertex) is **not** interference: it passes
`assert_no_interference`, fails any `assert_clearance(min_mm > 0)` (distance
0) and fails `assert_interference`. There is no "contact" category in the
JSON; a touching pair is indistinguishable from a separated one in
`interferences`. The containment row is a real false pass: a part hidden
entirely inside another passes a 5 mm clearance assertion
(`probe2.json` `contained_part_clearance_min5: passed true`) while
`no_interference` fails with 64 mm³.

Overlap depth sweep (overlap of depth d over a square contact patch) [M]:

| contact patch | d = 1e-7 | 1e-6 | 1e-5 | 2e-5 | 1e-4 | 1e-3 | 1e-2 | 1e-1 |
| --- | --- | --- | --- | --- | --- | --- | --- | --- |
| 10 × 10 mm | 0 (pass) | 1e-4 (pass) | 0.001 (pass) | 0.002 **fail** | fail | fail | fail | fail |
| 1 × 1 mm | 0 (pass) | pass | pass | pass | pass | 0.001 (pass) | 0.01 **fail** | fail |
| 0.2 × 0.2 mm | 0 (pass) | pass | pass | pass | pass | pass | 4e-4 (pass) | 0.004 **fail** |

- Overlaps up to 1e-7 mm give a Common volume of exactly 0 (OCCT treats them
  as touching).
- The effective depth tolerance is `0.001 mm³ / contact area`: 1e-5 mm for a
  10 × 10 patch, 1e-3 mm for 1 × 1, 0.025 mm for 0.2 × 0.2 [I from the
  measured rows]. For a 300 × 30 mm rail contact it is ~1e-7 mm; for a thin
  rib edge it is tens of microns. The threshold is a volume, not a length, so
  its meaning depends on part scale.
- Line contact, pin d3 in bore d3.5, 10 mm long, pushed off-center:
  penetration 1e-4 mm -> 6.1e-5 mm³ (pass), 1e-3 mm -> 0.0019 mm³ (fail),
  1e-2 mm -> 0.060 mm³ (fail).

Gap sweep [M]: gaps of 1e-9, 1e-8, 1e-7 mm give `distance_to == 0.0`. For
every gap g in 1e-6 ... 1e-3 mm, `distance_to` comes out slightly below g
(1e-6 -> 9.999999992515995e-7; 1e-3 -> 0.0009999999999994458), so
`assert_clearance(min_mm=g)` **fails on the nominal gap**. The concentric pin
in its bore (analytic radial gap 0.25) measures `0.24999999999999983`, so
`assert_clearance(pin, bore, min_mm=0.25)` fails on nominal geometry [M
distance, verdict from `assertions.py:57`]. Marc's scripts work around this
with `min_mm=0.20-1e-6` (`cad-project-003/overnight-2026-09-05/manufacturing/coupons.py:135`,
`snap_coupon.py:59`).

Rotated exact contact is robust: a face-touching pair rotated together by a
`RevoluteJoint` about a skew axis at 7°, 30°, 33.3°, 45°, 60°, 89.9° never
reports interference [M, `probe2.json` `rotated_face_contact`].

Cost [M]: one Common on a curved pair ~10-15 ms, one distance ~0.6-2 ms;
`compute` on 24 simple boxes (276 pairs) 0.17 s. The skill states the check
is O(n²) "fine up to ~20 parts" (`SKILL.md:659`); there is no broad phase,
every pair runs a full Boolean.

Diff [C/M]: `khana diff` compares part scalars and COM with exact `!=`
(`U/diff.py:73-91`), so translating a part prints `volume_mm3: 212 → 212
(-0.0%)` noise; interference volume changes use an absolute 1e-6 mm³ threshold
(`diff.py:130`); face/edge/vertex counts are not diffed; schema must be
exactly `0.2` on both sides (`diff.py:34-41`).
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

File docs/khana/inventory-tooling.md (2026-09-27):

# cad_khana tooling: inventory and the unified wonky version

Research document of the khana-design workflow (task `inv-tooling`),
2026-09-24. It inventories cad_khana's **tooling**: the `khana` CLI, Marc's
watch loop and the OCP viewer push, HLR drawings, the STL/STEP/GLB exports,
the diagnostics diff, the environment probe, the output layout and the
agent-facing skill conventions. For each item it says what wonky already has
(replaced / partial / missing) and what the unified wonky version should be.
The mechanism and printability *semantics* (assertions, diagnostics, pick,
wall, overhang, bores, orientation) are inventoried in the sibling documents
of this workflow; they appear here only where the tooling touches them.

Nothing in this document changes code. The kernel rules of `AGENTS.md` apply
to every proposal: geometry stays in Bend, OpenCascade may only validate
exported artifacts, unsupported functionality is an explicit capability
error, analytic curves are never silently polygonized.

## 0. Sources, versions and evidence

| Tag | Source | State |
| --- | --- | --- |
| `ck:` | `~/Workspace/cad/cad-khana/` (upstream checkout, read only). Module paths below are relative to `ck:src/cad_khana/`. | pyproject version 0.0.2 (`ck:pyproject.toml`); local commits plus uncommitted `mechanism/pick.py`, `cli.py`, `printability/inspect.py`, `printability/structure.py`, `skills/cad-khana/SKILL.md` (`git status`, measured) |
| `khana` | installed uv tool `~/.local/share/uv/tools/cad-khana` | 0.0.2, built from the checkout before the `pick` work: `khana pick` does not exist (exit 2) [M `tmp/khana/tooling/help.txt`] |
| tool env | same uv tool | build123d 0.10.0, bd_warehouse 0.2.0, ocp_vscode 3.4.0, ocp_tessellate 3.3.0, OCP 7.8.1, Python 3.13.3 [M `tmp/khana/tooling/status.json`, site-packages listing] |
| `skill:` | `~/.claude/skills/cad-khana/SKILL.md` (754 lines, installed copy the agent loads, Jun 11) | no `pick` |
| `ck:skills/…/SKILL.md` | upstream skill, 791 lines | adds `khana pick` (line 97) and the review loop with viewer indices (lines 119-137) |
| cad-project-043 | `~/Workspace/cad/cad-project-043/skills/cad-khana/SKILL.md` (thin entry, 2026-09-10) and `references/field-notes.md` (the old SKILL.md body, archived) | "The cad-khana runtime is a separate dependency; this repository bundles its skill knowledge, not the library." |
| `FN:` | `ck:field-notes.md` (262 lines, Marc's cad-khana paper-cuts) | read |
| `fdm-skill:` | `~/.claude/skills/cad-fdm-design/SKILL.md` and `references/watch.py` | Marc's daily loop |
| `cad:` | `~/Workspace/cad/**` (Marc's projects, read only) | |
| oracle | `tmp/khana/tooling/` in this repo: copies run with the real `khana` (never feeding the kernel) | `help.txt`, `status.json`, `diff-probe.log`, `pin_hinge/`, `probe_export/`, `probe_anim/`, `probe_cli/` |

Evidence tags: **[M]** measured (a command was run; the artifact is named),
**[R]** read in code or docs (file:line), **[I]** inference or design
proposal.

## 1. Key findings

1. **The CLI is a thin runpy dispatcher; all behavior hides in module
   toggles read inside `check()`.** `khana build|check|view|draw` run the
   script as `__main__` (`ck:cli.py:84`) and differ only by global switches
   (`cli.py:104-108`, `114-118`, `183-189`) that `check()` reads
   (`mechanism/check.py:37-60`). Consequences, all measured: a script without
   `check()` gets no view and no drawing and no message
   (`khana draw inspect_only.py`, exit 0); `khana draw` and `khana view` also
   write STL/STEP; `khana view` exits 0 when no viewer listens; an assertion
   failure ends the process with exit 1 and **no console output**, and every
   later `inspect()` never runs, leaving stale JSON (FN:13-16, 197-200).
2. **Marc's real loop is not `khana view` but `watch.py`**: 15 copies in
   `cad:` (13 projects plus cad-project-043 and a worktree; two variants) and one
   in the fdm skill that `runpy.run_path` the assembly **without**
   `run_name`, so the `__main__` guard keeps `check()`/`inspect()` out, and
   re-push the cached assembly every 5 s because the standalone OCP viewer
   keeps no state (`fdm-skill:references/watch.py:1-12, 45, 51-63`,
   FN:17-21). Diagnostics run separately (`khana check`), slicer files are a
   third manual step (`fdm-skill:SKILL.md:53-62`).
3. **The STEP export carries no part names, colors or materials** [M]:
   PRODUCT names are the generic `'ASSEMBLY'`/`'SOLID'`, solids are unnamed,
   there are 0 `COLOUR_RGB`; only the assembly tree (NAUO) survives. XCAF
   names and sRGB colors are written **only into the GLB**
   (`export.py:128-157`). The task framing "STEP with XCAF colors/names" does
   not match the code; the skill itself says colors are ignored by STEP
   (`skill:251-258`).
4. **GLB export depends on an external `gltf-transform` binary** that is not
   installed on this machine: `export_glb` raises *after* writing an
   unjoined GLB [M]; Marc's `cad-project-013/camera_mount_assembly.py:358-373`
   monkeypatches the private `_gltf_transform_join` away. Animated GLB samples
   `PlacedPart.location` per keyframe and puts one `animgroup_N` node per
   jointed sub-assembly with LINEAR (slerp) rotation channels [M]; the joint
   itself (axis, angle, limits) is not in the file.
5. **Drawings are HLR line art without dimensions or common scale**:
   build123d's exact OCCT `HLRBRep_Algo`, ten fixed views, each fitted to its
   own bounds (`draw.py:249-260`), PNG polylines with 48 samples per curve,
   SVG with exact conic arcs; unknown `--format` silently writes nothing [M].
6. **`khana diff` compares two hand-kept JSON files by exact equality**:
   float dust shows up as changes ("min_wall_mm: 3 → 3 (-0.0%)"),
   face/edge/vertex counts, `min_wall_at`, bores, pins and warnings are not
   diffed, the output is text only and the exit code is 0 on a regression
   [M `tmp/khana/tooling/diff-probe.log`].
7. **Fixed output names collide.** `mechanism.json`, `assembly.step`,
   `assembly.stl` and `views/*.png` have no script stem: Marc's
   `cad-project-026/assembly.py:68` and `scissor_assembly.py:122` both write
   `outputs/mechanism.json`; that directory holds JSON from three different
   days [M `ls -la`].
8. **wonky already replaces the viewer half better than OCP** (live server,
   rebuild on save with the import closure watched, last-good plus failure
   state, reload-safe, revisions, ghost and delta strip, exact FDM overhang
   shading, kernel wall probe, revision-bound aliases instead of per-push
   topology indices). It **lacks** drawings, GLB, named/colored/structured
   STEP, check evaluation, check diffs, a status probe and an agent skill.
   Two concrete wiring gaps: `wonky-view` does not pass `--khana-checks`,
   read-only roots or a working directory to the Python build
   (`src/viewer/live/build-worker.mjs:85-93`, `src/viewer/live/pool.mjs:333-338`),
   so a Marc `assembly.py` with `check()` in `__main__` fails in live mode,
   and the compat `Assembly._wonky_metadata()` records no joints
   (`python/cad_khana/mechanism/assembly.py:237-247`), so no animation can
   reach the viewer or an export.

## 2. The `khana` CLI

### 2.1 Execution model [R]

- Typer app `khana` (`cli.py:18-23`), `--version` eager callback
  (`cli.py:26-44`), entry point `khana = cad_khana.cli:main`
  (`ck:pyproject.toml`, `[project.scripts]`).
- `_run_script` (`cli.py:80-92`) runs `runpy.run_path(script,
  run_name="__main__")` (`cli.py:84`). `SystemExit`/`typer.Exit` pass through
  (`cli.py:85-86`); any other exception prints the traceback and
  `khana <command> failed: …` to stderr and writes an error
  `mechanism.json` (`status: "error"`, `error`, `hint` from
  `mechanism.hints.match_hint`) into `--out`, default
  `<script-dir>/outputs` (`cli.py:47-53`, `81-82`, `87-92`).
- The commands only set module-level toggles; `check()` reads them
  (`mechanism/check.py:21-26`, `37`, `50-60`). `check()` then runs in this
  order: exports (`check.py:38`) → assertion evaluation (`39-40`) →
  `mechanism.json` (`47-49`) → viewer push if `khana view` (`50-51`) → drawings
  if `khana draw` (`52-60`) → `SystemExit(1)` on any failed assertion
  (`62-63`). A failing design is therefore still exported, pushed and drawn.
  `inspect()` also ends with `SystemExit(1)` (`printability/inspect.py:155`).
- Because `SystemExit` passes through `_run_script`, a failed assertion
  produces exit 1 and nothing on stdout/stderr [M: `pin_hinge` build and
  `check_r2` logs are empty]. The first failing `check()`/`inspect()` stops the
  script; later calls never write their JSON and old files stay on disk
  (FN:13-16, 197-200, 252-253) [M: `pin_hinge` tang inspect never ran].

### 2.2 Commands and flags

`khana --help` of the installed 0.0.2 lists build, check, view, draw,
status, diff [M `help.txt`]. `pick` exists only in the checkout.

| Command | Flags | Semantics | Exit | Evidence |
| --- | --- | --- | --- | --- |
| `khana build SCRIPT` | `--out PATH` (crash diagnostics only) | run script; `check()` exports `assembly.stl` + `assembly.step`, writes JSON | 1 on exception or failed assertion | `cli.py:95-98`; [M] pin_hinge exit 1, 2.4 s |
| `khana check SCRIPT` | `--out` | as build, `_set_export_default(False)`: no STL/STEP | as build | `cli.py:101-108`; [M] only `mechanism.json` |
| `khana view SCRIPT` | `--out` | as build plus `viewer.push(assembly)` inside `check()` | **0 even when no viewer listens** (CommsWarning traceback on stderr) | `cli.py:111-118`; [M `probe_cli/cli-probe.log`] |
| `khana draw SCRIPT` | `--out`, `--views-dir PATH` (default `<out>/views`), `--format png\|svg\|both` (default png), `--themeable` (SVG classes), `--view a,b` (subset of 10), `--part NAME` | as build plus `draw.draw()` inside `check()` | unknown `--view`: 2 before the script runs; unknown `--format`: **0 with an empty `views/`** | `cli.py:121-189`, `draw.py:540-543`; [M] |
| `khana pick SCRIPT` (checkout only) | `--part NAME` (required), `--faces`, `--edges`, `--vertices` (CSV indices) | runs the script as `__khana_pick__` (main block does not run), collects every `Assembly` in the module namespace, resolves OCP-viewer topology indices on `part.moved(location)` to JSON facts | 1 if no assembly or unknown part | `cli.py:204-256`; semantics in the mechanism inventory |
| `khana status` | none | JSON environment report | 1 when degraded (viewer unreachable) | `cli.py:259-265`; [M] exit 1 |
| `khana diff BEFORE AFTER` | none | text diff of two diagnostics JSON files | 2 on kind or schema mismatch, **0 on a regression** | `cli.py:268-277`; [M `diff-probe.log`] |
| `khana --version` | | `khana 0.0.2` | 0 | `cli.py:26-29`; [M] |

The README surface (`ck:README.md:53-57`) and the design doc surface
(`ck:CLAUDE.md`, "CLI surface") list build/check/view/draw/diff only;
`status` and `pick` are documented in the skills.

### 2.3 Output paths: `_paths.resolve_out`

`resolve_out(out)` (`_paths.py:9-25`): absolute paths unchanged; relative
paths anchored to the directory of `sys.modules['__main__'].__file__` (true
for `python script.py` and `runpy.run_path(..., run_name="__main__")`), else
cwd-relative. Used by `check()` (`check.py:35`), `inspect()`
(`inspect.py:91`) and `suggest_orientation()` (`orientation.py:124`). The CLI
`--out` is a different thing: only the crash-diagnostics directory
(`cli.py:67-77`), so a crash and a normal run may write to different
directories when a script passes its own `out=`.

## 3. Marc's daily loop: `watch.py` + OCP viewer

### 3.1 The documented loop [R]

`fdm-skill:SKILL.md:40-62`: one uv project per design with `<part>.py`
(parameters, pure part functions, `__main__` export of per-part STL/STEP to
`out/`), `assembly.py` (khana `Assembly`, assertions, `suggest_orientation`,
`inspect`), `watch.py` (copied from `references/watch.py`), `out/` (slicer
files) and `outputs/` (khana JSON). Start once per session, in the
background: `uv run python -m ocp_vscode` (port 3939) and `uv run watch.py`.
Loop: edit → `uv run khana check assembly.py` → read `outputs/*.json` → the
viewer updates itself; after geometry changes **also** run `uv run <part>.py`
("khana only writes `outputs/`, the slicer files in `out/` go stale
silently"). Review (`fdm-skill:SKILL.md:64-73`): Marc selects faces/edges in
the OCP viewer (f/e/v filters), quotes part + indices, the agent resolves them
with `khana pick`; indices are per pushed snapshot.

Real projects follow it: `cad:cad-project-026/bar.py:83` (`OUT = "out"`) and
`bar.py:273-285` (main-block exports), `cad-project-026/assembly.py:67-97`
(main block: `check`, four `inspect`, one `suggest_orientation`).

### 3.2 `watch.py` [M + R]

`find ~/Workspace/cad -name 'watch*.py'` plus md5 [M]: 12 copies of a
67-line variant (hash `08441e…`, identical to
`fdm-skill:references/watch.py`; also in cad-project-043 and in an improvement
worktree) and 3 copies of an older 60-line variant (`e2f99d…`:
`cad-project-033`, `cad-project-046`, `cad-project-048`). Lines below cite the
canonical copy.

| Aspect | Behavior | Lines |
| --- | --- | --- |
| Target | `SCRIPT = argv[1]` or `assembly.py` next to watch.py (old variant: fixed `assembly.py`) | 22 |
| Change detection | tuple of `st_mtime` of every `*.py` in the script directory except `watch.py`, polled every `INTERVAL = 5.0` s; subdirectories and non-Python inputs (JSON parameters, imported STEP) are not watched | 23, 26-32 |
| Stale imports | purge `sys.modules` entries whose file lives in the project root before rerunning (old variant lacks this, so edits to sibling modules were silently ignored) | 38-44 |
| How the model loads | `runpy.run_path(str(SCRIPT))` **without `run_name`**: the module is not `__main__`, so `check()`/`inspect()` in the main block do not run | 45 |
| What is taken | `module["assembly"]` (must be a module-level name) | 46 |
| Push | `cad_khana.viewer.push(assembly)` every 5 s, changed or not (keep-alive for reloaded tabs) | 20, 51-63 |
| Failure | traceback on stdout, "push/build failed, retrying"; the previous assembly keeps being pushed, the viewer shows no failure state [I from code] | 60-62 |

What is re-run on save: the whole assembly script and (new variant) freshly
imported sibling modules. Not re-run: diagnostics, the parts' `out/`
exports. FN:17-21 names the reason ("Viewer keeps no state for reloaded
tabs … A `khana watch` subcommand would be a natural home for this").

### 3.3 What the OCP viewer receives (`viewer.py`) [R]

`push(assembly)` (`viewer.py:19-25`): `placed_parts` (the flattened tree,
`mechanism/assembly.py:317-334`) moved to world, names = placed names,
colors = `placed.color or part.color`, passed only if any is set;
`ocp_vscode.show(*parts, names=…, colors=…)`. Tessellation happens in
`ocp_vscode`/`ocp_tessellate` with their defaults (deviation 0.1, angular
tolerance 0.2 rad: tool env `ocp_vscode/show.py:784-785`). Not pushed:
sub-assembly hierarchy, materials, joints, assertion results, interference
volumes, printability results. The viewer is the OCP CAD Viewer VS Code
extension or the standalone `python -m ocp_vscode` server on port 3939
(`skill:111-142`, with a Zed task pair). `set_auto`/`auto_enabled`
(`viewer.py:10-16`) are the `khana view` toggle.

## 4. Drawings (`draw.py`) [R + M]

| Aspect | Behavior | Evidence |
| --- | --- | --- |
| Views | 10 presets: `top`, `bottom`, `front`, `back`, `right`, `left` and `iso_ne/nw/se/sw` (camera octant in +Z-up/+Y-forward space); `DEFAULT_VIEW_NAMES`, `STANDARD_VIEWS` | `draw.py:63-84`, `skill:696-702` |
| Algorithm | build123d `Drawing(compound, look_at, look_from, look_up, with_hidden=True)` = exact OCCT `HLRBRep_Algo` + `HLRBRep_HLRToShape`, orthographic | `draw.py:471-483`; tool env `build123d/exporters.py:79-112` |
| Dedup | visible and hidden edges fingerprinted (conics by center/radii, others by rounded endpoints + midpoint, 1e-4) and de-duplicated, visible wins | `draw.py:109-171` |
| PNG | 1200 px square, 2× supersampling, 6 % margin, visible black 2 px, hidden grey (170,170,170); lines 2 samples, **every curve 48 samples** | `draw.py:86-102`, `273-298` |
| SVG | circles and ellipses as exact SVG arcs (large/sweep flags classified from sample points); lines and other curves as polylines; `--themeable` adds `class="cad-visible"`/`"cad-hidden"` next to the inline stroke | `draw.py:179-236`, `301-419` |
| Framing | each view is fitted to its own 2D bounds: **no common scale across views, no scale recorded, no scale bar** | `draw.py:243-260`, `394-407` |
| Content | no dimensions, labels, view names, title block, section views, colors or part names in the image | [M] SVGs of `probe_export/outputs/views/` |
| Scope | whole assembly or `--part` (framed alone, in its assembled position) | `draw.py:422-432` |
| Output | `<out>/views/<view>.png` / `.svg`, fixed names, overwritten, no model id or timestamp | `check.py:55`, `draw.py:497`, `514` |
| Cost | 20 files (10 × png+svg) in 2.7 s on a 3-part probe | [M] `probe_export/draw.log` |
| Failure modes | unknown `--format` → nothing written, exit 0 [M]; assemblies of imported STL meshes → exit 0, no views, no error (FN:86-87) | |

The skill's reading rules (load one view, pick it by question) are in
`skill:696-727`. Programmatic use in Marc's projects: only
`cad-project-013/camera_mount_assembly.py:375-379` (four views of a
mock-up). The drawings are the agent's shape-level channel (`ck:CLAUDE.md`
"two channels"); wonky's agent channel today is the viewer's exact
selection/overview text instead (section 11, row 12).

## 5. Exports (`export.py`)
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

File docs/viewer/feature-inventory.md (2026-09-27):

# Viewer feature inventory (regression checklist)

Baseline: 2026-09-22, audited code `viewer/app.js` (710 lines), `viewer/index.html`,
`viewer/style.css`, `src/review-server.mjs`, `src/review-scene.mjs`,
`bin/wonky-view.mjs`. Every row is something a user, a script or an agent can
observe today. Later stages keep each row working, or the spec retires it with
a reason. Rows marked **defect** record current behavior that is wrong; do not
preserve those, fix them deliberately (see `docs/viewer/audit-code.md`).
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

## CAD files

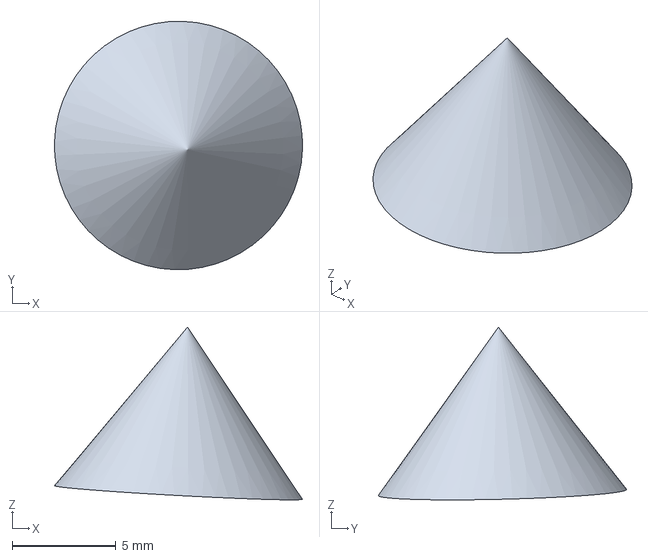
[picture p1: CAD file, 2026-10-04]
fixtures/cad-acid/occt-ext/catalog-errata/artifacts/AC25/V3/model.step
12.0 x 12.0 x 8.34 mm

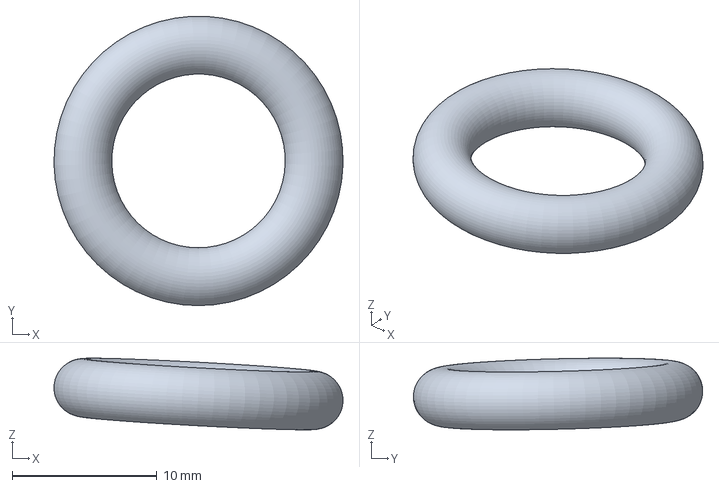
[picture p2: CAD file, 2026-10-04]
fixtures/cad-acid/occt-ext/catalog-errata/artifacts/AC26/V3/model.step
20.0 x 20.0 x 4.95 mm

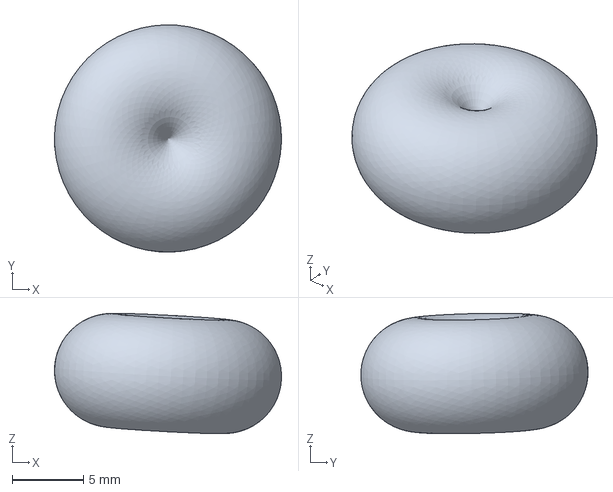
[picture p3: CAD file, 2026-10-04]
fixtures/cad-acid/occt-ext/catalog-errata/artifacts/AC48/V3/model.step
16.0 x 16.0 x 8.47 mm

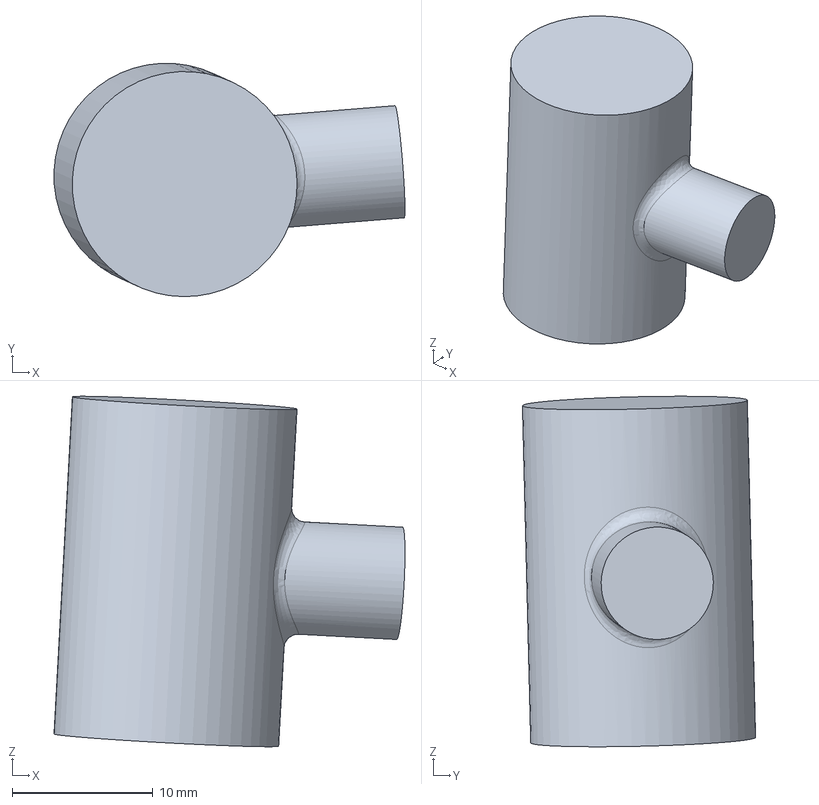
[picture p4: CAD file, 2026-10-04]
fixtures/cad-acid/occt-ext/CE9/cells/AC36/V3/model.step
24.9 x 16.6 x 24.9 mm

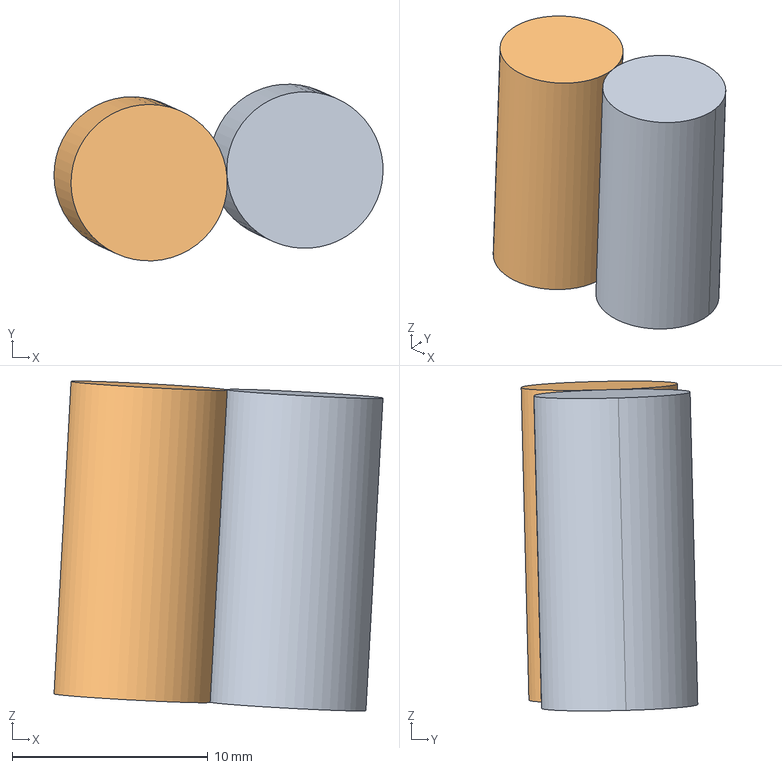
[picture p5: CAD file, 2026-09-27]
fixtures/cad-acid/occt/artifacts/occt-a/occt/precision/V3/AC44/model.step
16.8 x 9.03 x 16.9 mm

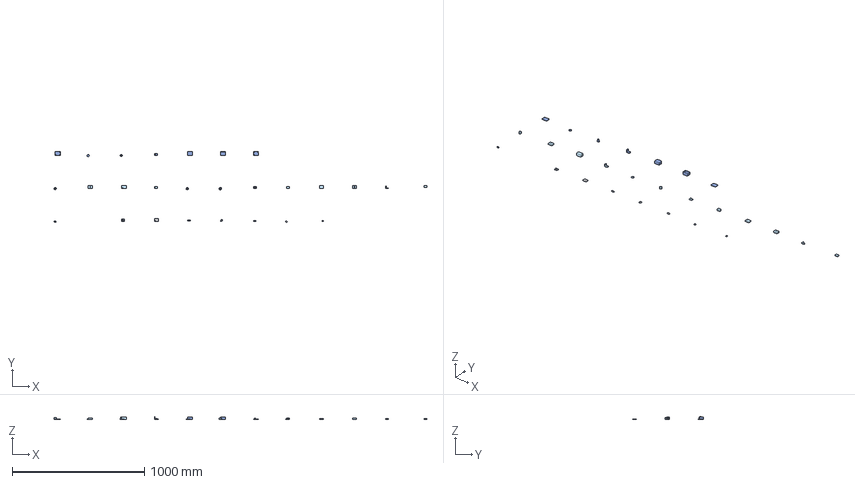
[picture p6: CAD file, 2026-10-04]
fixtures/cad-acid/onshape-ext/A/studios/acid-V5/model.step
2823.0 x 536.0 x 22.0 mm

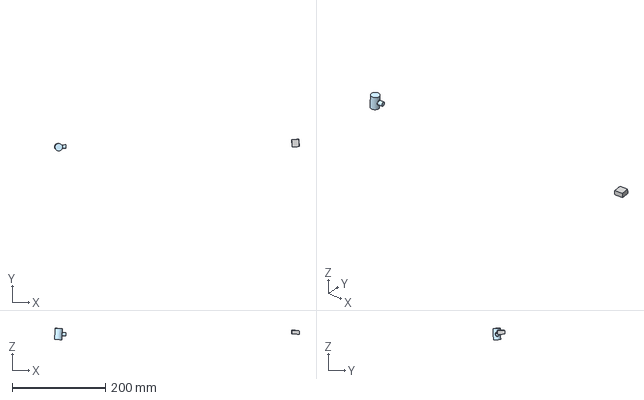
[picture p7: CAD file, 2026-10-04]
fixtures/cad-acid/onshape-ext/CE9-CE10/studios/acid-V3/model.step
524.6 x 25.5 x 24.9 mm

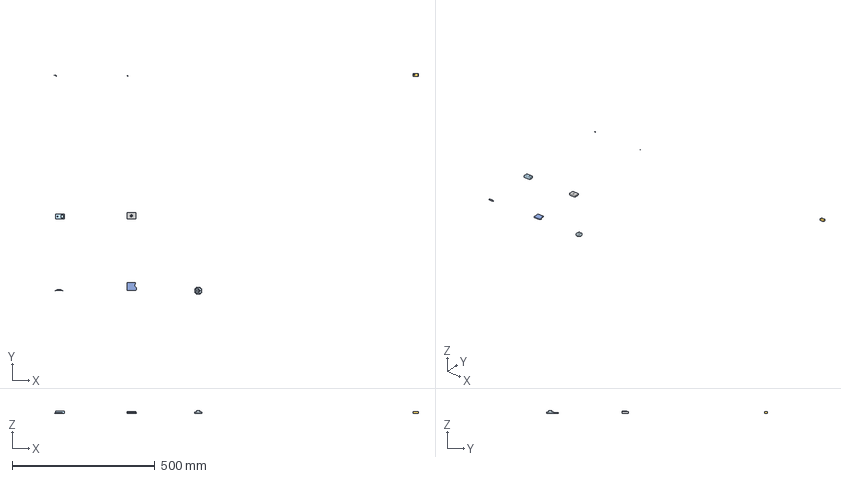
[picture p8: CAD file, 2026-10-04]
fixtures/cad-acid/onshape-ext/N24/studios/acid-V5/model.step
1272.8 x 773.5 x 12.0 mm

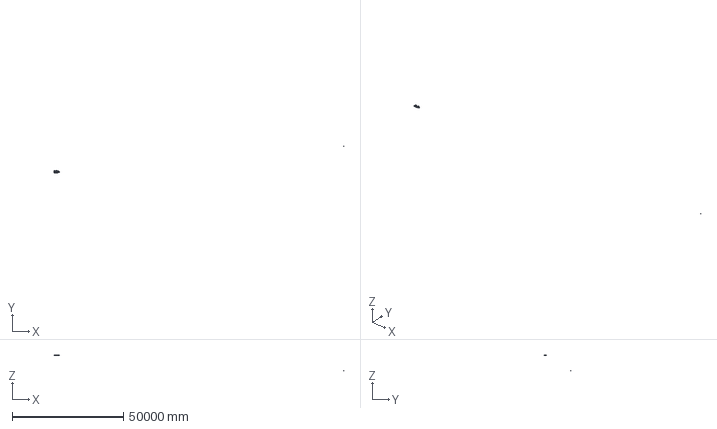
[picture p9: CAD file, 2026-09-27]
fixtures/cad-acid/onshape/studios/acid-V3/model.step
130488.7 x 12112.5 x 6871.4 mm

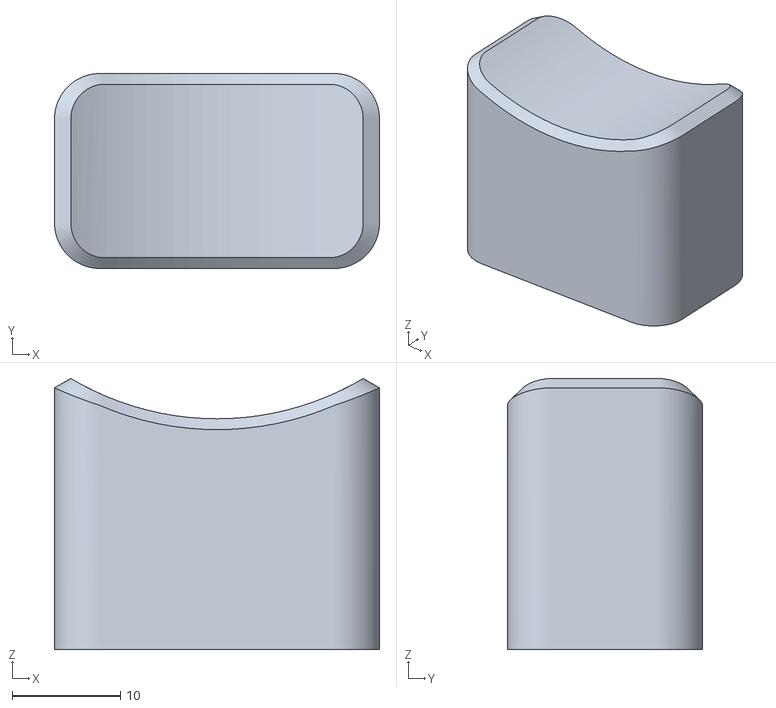
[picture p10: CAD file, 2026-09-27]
fixtures/fillet/onshape/fp17/fp17d.stl
30.0 x 18.0 x 25.0

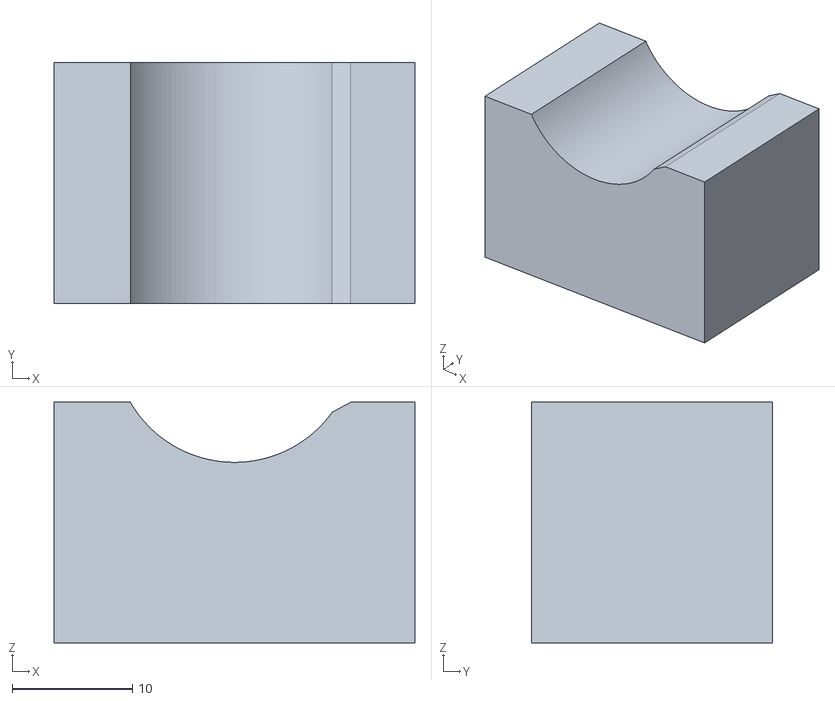
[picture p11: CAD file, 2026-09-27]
fixtures/fillet/onshape/fp18/fp18b.stl
30.0 x 20.0 x 20.0

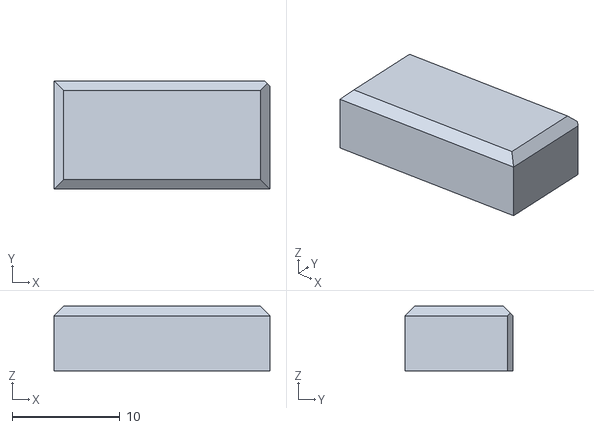
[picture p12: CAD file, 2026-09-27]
fixtures/fillet/onshape/fp19/fp19b.stl
20.0 x 10.0 x 6.00

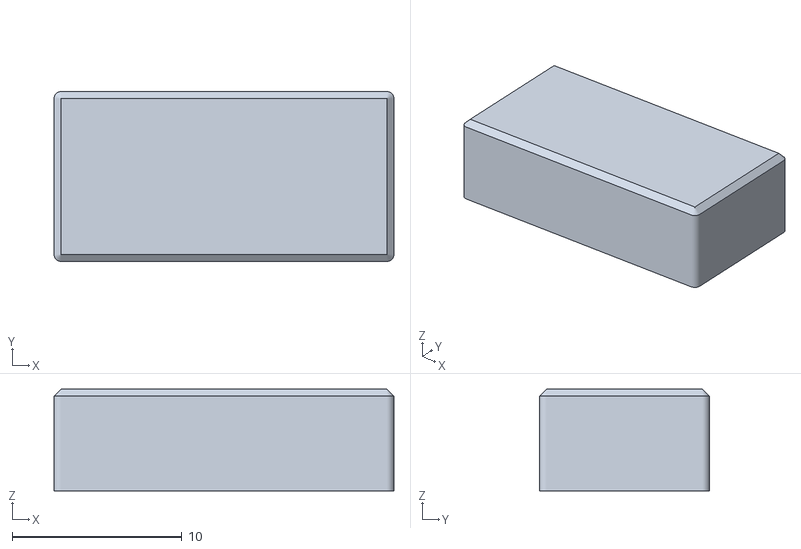
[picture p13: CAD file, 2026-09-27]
fixtures/fillet/onshape/fp20/fp20b.stl
20.0 x 10.0 x 6.00

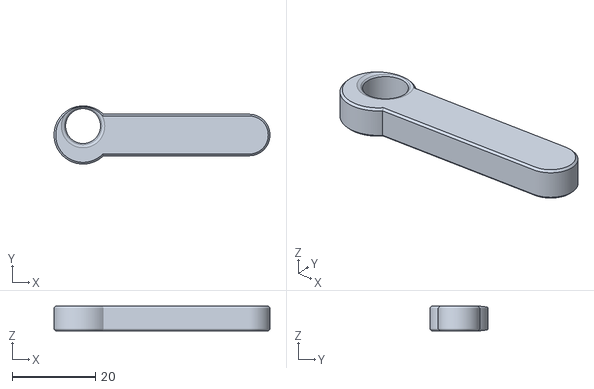
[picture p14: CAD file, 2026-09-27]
fixtures/fillet/onshape/fp21/fp21b.stl
52.0 x 14.0 x 6.00

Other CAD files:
fixtures/cad-acid/occt/artifacts/occt-b/occt/curved/V3/AC20/model.step
fixtures/cad-acid/occt/artifacts/occt-b/occt/curved/V3/AC22/model.step
fixtures/fillet/onshape/fp22/fp22c.stl
fixtures/rust/occt-oracle/exports/boolean-box-face-tangent-intersect.step
fixtures/cad-acid/occt-ext/CE9/cells/AC36/V0/model.step
fixtures/cad-acid/occt-ext/CE9/cells/AC36/V1/model.step
fixtures/cad-acid/occt-ext/CE9/cells/AC36/V2/model.step
fixtures/cad-acid/occt-ext/catalog-errata/artifacts/AC25/V0/model.step
fixtures/cad-acid/occt-ext/catalog-errata/artifacts/AC25/V1/model.step
fixtures/cad-acid/occt-ext/catalog-errata/artifacts/AC25/V2/model.step
fixtures/cad-acid/occt-ext/catalog-errata/artifacts/AC26/V0/model.step
fixtures/cad-acid/occt-ext/catalog-errata/artifacts/AC26/V1/model.step
fixtures/cad-acid/occt-ext/catalog-errata/artifacts/AC26/V2/model.step
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

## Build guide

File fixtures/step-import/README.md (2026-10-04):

These repository-authored fixtures describe one tetrahedron in three source
encodings: AP214 Part 21 with SI millimetres, Part 21 with conversion-based
inches, and the JSON bodydetails schema used by frozen R20 context captures.
The JSON is a synthetic fixture, not evidence of a live Onshape capture.
`provenance.json` binds the original bytes and unit rationale.

The importer is `wonky_geom::import::ImportDraft::{step,capture}`. Supply the
expected SHA-256, optional revision, instance path and resource limits, then
call `check()`. Both decoders feed the same identity-preserving planar Model
admission, including the unchanged G1–G8 checks. `ImportedModel::replay` verifies
source bytes and repeats decoding and admission. Coordinates lift binary64
words into rationals before exact unit conversion. Decimal lexemes and words
remain in the import state; unit definitions use exact conversion ratios.

I0 admits one selected, closed planar solid with straight edges. It preserves
source topology IDs, face/coedge senses and holes, derives exact line pcurves,
and never heals inconsistent incidences. STEP support includes bounded syntax,
forward references, complex unit/context entities, SI and conversion-based
inch units, and declared length uncertainty. Capture coordinates are metres
by the frozen API contract; absent tolerance remains unknown. Curved surfaces,
supplied pcurves, assemblies, multiple solid selection and repair are named
refusals pending subsequent stages. This does not connect the FeatureScript
lazy captured-body accessor yet (I3), nor claim SG90/R20 completion.

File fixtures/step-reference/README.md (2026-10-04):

These owned STEP inputs exercise reference observations, certified enclosures
and reference-body admission. They do not establish exact reconstruction, solid
validity, repair, or the mesh/viewer delivery of I1c.
Their immutable byte hashes, origin and licence are in `provenance.json`.

`analytical.step` contains closed, ring-bounded cylinder and truncated-cone
observations, two hemispheres and an upper half torus with an annular base,
SI millimetres, declared 1e-6 mm uncertainty, and nested translations 7 + 11 mm.
`rational-pcurves.step` extends the owned tetrahedron with a collinear rational
3D spline and matching rational planar pcurves. The historical planar fixtures
remain unmodified and also exercise exact inch conversion and unknown tolerance.

Rust tests in `wonky-geom/tests/reference_import.rs` check topology, semantic
circle-frame enclosures and whole-domain certificates, including disconnected
coedges, off-surface spline interiors, pcurve mismatch and an omitted torus face.
The local `reference-step` example prints observations and partial certificates;
it exits 2 because full reference admission is still unavailable. The two
third-party SG90 STEP files are deliberately absent from committed fixtures.

`tetra-reference.step` declares zero uncertainty for its owned rational geometry.
`spline-trim.step` puts the tetrahedron's triangular bottom trim on a rational
bilinear tensor surface, with explicit pcurves and declared 1e-6 mm uncertainty.
Their source geometry remains analytic; bounds are enclosures with reported slack.

The normal reference body report is available with:

```sh
WONKY_BACKEND=rust node bin/wonky.mjs fixtures/step-reference/spline-trim.step --json
```

It includes every face's outcome, enclosure method and slack, the union bbox,
source labels, uncertainty and digest. Reference bodies have `exact:false`;
modelling refuses `import/reference-body/<operation>` until exact repair/admission.
Area, volume, solid-interior validity and display exports are not evaluated here.

Spherical polar trimming currently supports an oriented single latitude ring.
Other spherical loop decompositions refuse `import/sphere-polar-trim-undecidable`
until their pole/winding proof is implemented.

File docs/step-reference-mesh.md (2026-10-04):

# STEP reference display meshes

Use the Rust backend and the normal STEP input entry point:

```sh
WONKY_BACKEND=rust node bin/wonky.mjs servo.step --format stl --deviation-mm 0.02 --out out/servo
WONKY_BACKEND=rust node bin/wonky.mjs servo.step --format html --out out/servo
WONKY_BACKEND=rust node bin/wonky-view.mjs servo.step --no-open
```

STL is binary, in world millimetres, with STEP item placements applied. Its
`<prefix>.stl.json` sidecar records `exact:false`, `approximation:"tessellated
mesh"`, requested deviation, producer-declared source uncertainty, provenance,
face coverage, watertightness, sampled maximum carrier deviation and the maximum
interpolation bound and combined deviation bound. Source uncertainty remains separate from display deviation.
Unknown uncertainty or an insufficient budget produces a named refusal.

The mesh reuses certified polylines of the retained STEP edges on every incident
face. Planar trims, periodic bands, spherical caps and tensor-product rational
B-splines use their retained carriers; no CAD library constructs the geometry.
Chart triangulation reuses the Rust kernel’s constrained Delaunay legalizer
with exact rational orientation and diagonal decisions. Interior refinement
uses second-derivative interpolation bounds. STEP boundary
vertex identity owns connectivity. Source-coordinate chart inversion precedes
item placement. The normal STL coordinate-welding checks run after float32
storage conversion; a gap, collapsed triangle or non-manifold edge refuses.

Mesh validation reconstructs trim domains from the retained source and checks
vertices against the exact analytic carrier predicates or rational spline
point enclosures in Rust. Sampled triangle deviations are measured at vertices,
edge midpoints and centroids; the reported sampled maximum is **not** an exhaustive
maximum. The separate interpolation bound covers each triangle's interior.
The trim is displayed with the certified edge-polyline deviation; it is never
promoted to an exact polygonal B-rep. Non-C1 spline knots and exhausted refinement
budgets currently refuse by name.

HTML and the live viewer show the same approximate geometry and preserve STEP
placement. Reference area and volume remain unavailable. Reference bodies still
refuse Boolean, fillet, chamfer, pattern and transform operations. The mesh does
not create an exact body or enable those modelling operations.

Committed tests use repository-owned synthetic STEP fixtures. Local third-party
SG90 input and its exported previews remain outside Git. A four-view rendering
is a display check, not geometric validity evidence.

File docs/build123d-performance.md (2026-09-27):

# Same-source build123d performance

`scripts/benchmark-build123d.mjs` executes each frozen Python file unchanged through two independent paths:

- Production Wonky `buildPython`: the existing `build123d` compatibility shim, private RPC pipes, and real Bend geometry compiled to JavaScript.
- An isolated Python worker with real `build123d==0.10.0` and `cadquery-ocp==7.8.1.1.post1`. This worker only constructs reference benchmark geometry. It never supplies shapes or fallbacks to Wonky.

Both use the same Python 3.13 interpreter, filename, source SHA-256 and literal parameters. Wonky retains its production `-I -S` runner, external-geometry import rejection, eager construction/validation and source tracking. No production source or kernel changes are required.

## Run

From the repository root, prepare the independent reference environment once:

```sh
uv venv --python 3.13 out/build123d-performance/reference-venv
uv pip sync --python out/build123d-performance/reference-venv/bin/python fixtures/performance-build123d/reference.lock
node --test test/benchmark-build123d.test.mjs
node scripts/benchmark-build123d.mjs --check --out out/build123d-performance/check-new
node scripts/benchmark-build123d.mjs --out out/build123d-performance/run-new
```

Each report directory must be new, preserving earlier failures and measurements. `--python PATH` selects an alternative isolated environment; installed versions must match the frozen lock. `--case ID` can be repeated for diagnosis. `--check` only tests geometry and makes no performance claim. Defaults are three warmup rounds, seven measured rounds, three cache-disabled Bend startup rounds and three fresh/cached startup rounds. At least three measured rounds are required for every timing population. Run the principal series after tests and other competing work finish; the harness itself executes engines sequentially.

The environment lock also pins `ocp-gordon==0.1.17`: unconstrained resolution currently selects 0.3.1, whose `OCP.collections` import requires OCCT 8 and breaks build123d 0.10's OCCT 7.8 environment. All transitive package versions, the lock hash and observed loaded module paths are recorded. The existing independent STEP validator separately uses its own pinned OCCT 8 environment.

## Workloads and correctness

The original local files in `fixtures/performance-build123d/cases/` range from one primitive to three primitives and two Boolean operations. They are a selected diagnostic subset, not the upstream build123d test suite or a CADBench score.

| File | Work | Analytic volume, mm³ |
|---|---|---:|
| `box.py` | One minimum-aligned box | 12000 |
| `translated-cylinder.py` | One cylinder and translation | 1280π |
| `coaxial-bore.py` | Two coaxial cylinders, subtraction | 2380π |
| `planar-union.py` | Two translated overlapping boxes, union | 15500 |
| `planar-pocket.py` | Two boxes, blind pocket subtraction | 18240 |
| `frame-with-tab.py` | Through opening followed by a tab union | 13840 |

`unsupported-fillet.py` and `unsupported-box-bore.py` are executed by both engines and retained as capability probes. Unsupported operations are recorded with their errors and never assigned timing ratios. A future implementation that supports them is reported explicitly; they do not automatically enter the frozen timed cohort.

Before timing, both engines must agree on solid count, volume and bounds against independent analytic expectations. Real OCCT construction must pass exact `BRepCheck_Analyzer`, and its point classifications must match the expected inside/outside probes. The existing `scripts/validate-step.py` then reads the Wonky STEP, checks strict validity, topology and volume, and classifies the same points. This reader does not report a bounding box; bounding agreement uses the separate native metrics. The volume tolerance is max(1e-5 mm³, 2e-5 relative), bounds tolerance 1e-5 mm and point tolerance 1e-7 mm. Probes avoid boundaries and distinguish pockets, bores, tabs and missing regions.

Every warmup and measured construction is checked again. Final timed Wonky exports pass independent validation again. Source files and the complete implementation snapshot must remain unchanged before any ratios are accepted. Failures, raw samples, STEP/B-rep files, strict validation reports and logs stay in the output directory. A failed candidate prevents overall acceptance; partial validated rows are not a full-cohort claim.

The planar B-reps may partition the same checked volume into different faces. Native face/edge/vertex counts are retained for each engine. Agreement of volume, bounds and selected point probes is not an exhaustive proof of arbitrary shape equality; the strict reader independently checks each Wonky boundary representation as exported.

## What the timers measure

| Phase | Observed boundary and limits |
|---|---|
| Cold Bend startup | New Node process to fully loaded adapter, kernel and exporter, with persistent compiled-Bend cache disabled. OS filesystem/page caches remain warm. |
| Cached startup | New Node process with persistent Bend cache; separately, a new Python process importing real build123d/OCCT. Repeated process-to-ready wall times include the benchmark worker's initialization and version reporting. |
| Warmed build | Existing public `buildPython(source)` boundary versus real Python compile+exec in a fresh namespace with imported build123d. Both include actual eager geometry construction. |
| Frontend | Reference Python compile time is observed directly. Wonky frontend, per-call Python startup, geometry and RPC cannot be individually timed through its existing adapter, so their fields remain `null`. They are included in the warmed build total. No subtraction estimate is presented. |
| Native revalidation | Additional validity checks after construction, timed separately. The two validators have different scopes; this is not an accuracy-equivalent validity benchmark. Eager construction checks remain inside build time. |
| STEP export | Serialization/export plus file write. Wonky also performs mandatory exporter revalidation. No fsync; ordinary OS cache effects apply. B-rep JSON output, hash reads and observations are outside this timer. |
| Independent validation | Fresh `uv run scripts/validate-step.py` wall time: imports, reader, strict validation, volume and point classification. It is a separate phase, not isolated reader computation. |

The reported Wonky/reference build ratio includes different API overhead: Wonky starts a fresh isolated Python shim process for **every** call, uses RPC, performs eager validation and retains source tracking; real build123d executes in an already imported Python process. This is an observed build API ratio, **not an isolated Bend/OCCT kernel speed ratio**. There is no fair pure-kernel measurement hidden behind it. Startup populations are reported separately rather than subtracted from build samples.

Case order rotates and engine order alternates across rounds. The report retains medians, interpolated quartiles, min/max and every raw sample; small populations are not confidence intervals. Hardware, OS, Node/Python/Bend/OCCT versions, free memory, CPU counters, load averages and macOS thermal status are recorded. Background activity, scheduling, frequency changes and power management are observed but not controlled. No native or GPU speed inference is made from Bend's JavaScript target.

## Recorded run: 22 September 2026

The principal run, [report.json](../out/build123d-performance/principal-1/report.json), ran from 10:15:46 to 10:24:34 UTC after the full repository tests finished and other project load jobs paused. Hardware: Apple M5 Pro, 18 logical CPUs, 64 GiB, arm64/Darwin 25.6.0. Software: Node 22.23.1, Python 3.13.3, Bend 2.0.25 JavaScript target, build123d 0.10.0, OCCT/OCP 7.8.1.1. Three warmup rounds preceded seven measured rounds per case. All six candidates passed both geometric gates; the implementation snapshot remained unchanged.

**Real build123d was faster at the measured construction API boundary in every shared case.** Values below are medians in milliseconds, with the interquartile interval in parentheses. The ratio is Wonky time divided by reference time; it includes the process/RPC/validation differences explained above.

| Same Python file | Wonky build, ms (IQR) | Real build123d, ms (IQR) | Wonky/reference |
|---|---:|---:|---:|
| `box.py` | 26.65 (26.53–31.21) | 0.4115 (0.3930–0.4280) | 64.8× |
| `translated-cylinder.py` | 25.70 (25.31–28.39) | 0.4429 (0.4371–0.4616) | 58.0× |
| `coaxial-bore.py` | 27.29 (27.00–29.27) | 2.529 (2.279–2.578) | 10.8× |
| `planar-union.py` | 1829.79 (1819.14–1982.13) | 4.872 (4.691–5.703) | 375.6× |
| `planar-pocket.py` | 3475.25 (3458.21–3548.63) | 3.655 (3.289–3.685) | 950.8× |
| `frame-with-tab.py` | 15851.09 (15653.60–15888.84) | 9.430 (8.551–10.438) | 1680.9× |

The small primitive results include approximately 26 ms of exposed Wonky build time, whose internal process/RPC/geometry components are not separately observable. The planar cases take much longer and retain more subdivisions: Wonky/reference face counts are 26/10 for the union, 46/11 for the pocket and 64/14 for frame+tab. These are observed differences, not a profile proving a specific internal bottleneck.

| Separate startup population, 3 samples | Median | Full range |
|---|---:|---:|
| Wonky, persistent Bend cache disabled | 93.653 s | 92.511–94.814 s |
| Wonky, compiled Bend cache enabled | 0.694 s | 0.691–0.779 s |
| Real build123d, fresh Python process | 1.078 s | 1.020–1.557 s |

STEP export-and-write medians for Wonky/reference were 0.309/4.125 ms (box), 1.852/3.752 ms (cylinder), 4.351/3.978 ms (bore), 0.407/4.729 ms (union), 0.611/4.782 ms (pocket) and 0.772/5.366 ms (frame+tab). These exporter timings do not reverse the construction result. Native revalidation and reference compile-only statistics remain separate in the report. The independent six-model strict STEP/probe validation took 1.331 s before timing and 1.381 s after timing, including fresh-process/import overhead.

Background activity remained observable: the one-minute system load average was 12.08 before warmed sampling and 11.59 afterward; macOS reported no recorded thermal/performance warning. One reference union sample was 22.05 ms against a 4.87 ms median. All samples and spread are retained; this is a local run rather than a hardware-independent speed estimate.

Fillet failed explicitly as `unsupported-api` (`Shape.edges`), and box/cylinder subtraction failed as `unsupported-geometry`; both reference constructions passed. Neither receives a speed ratio. The earlier [geometry-only preflight](../out/build123d-performance/geometry-check-1/report.json) also passed all six shared workloads, but its incidental durations were collected during repository tests and are not performance results. The [initial dependency-resolution failure](../out/build123d-performance/reference-initial-resolution-failure.json) is retained as setup evidence.

## Native CPU/Metal follow-up status — 22 September 2026

The table above measures the Bend JavaScript modeling path. No accepted
ARM64/Metal timings exist yet for these six programs. The separate
[historical hardware benchmark](hardware-performance.md) uses large batches of
independent cylinder comparisons and coaxial bores, not these planar workloads.
Its speed ratios cannot be applied to this table.

The [capture](../out/performance/native-build123d/captured.json) currently records
production calls/operands for union, pocket and frame-with-tab. It does not
contain a completed native executable or timing populations. The frame capture
explicitly reports `nativeChainExact: false`: the existing host B-rep roundtrip
changes low F32x2 words. Replaying separately captured operands can measure
those kernel calls, but excludes host adaptation and is not an equivalent
complete native model pipeline. Resolve and document that measurement boundary
before publishing a comparison.

The broader [prepared-solid optimization](../out/performance/prepared-solids/STATUS.md)
is also staging only, currently blocked at its first compile by a forward
reference. The production profiles exist; no optimization speedup or completed
integration is claimed. The dated status retains the
source hashes, evidence and next actions. The principal report's recorded
production file hashes still match at this documentation checkpoint.

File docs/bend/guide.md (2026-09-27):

# Bend 2.0.25 in wonky: the reference

This is the long form behind the `wonky-bend` skill (`.claude/skills/wonky-bend/SKILL.md`). It covers
the Bend that wonky writes: the errors agents actually hit here, with before/after code, the idioms
the kernel uses, performance traps, targets, testing, `R.*`, the exact predicates, the collections
adapters and the laws gate. The syntax cheat sheet is [syntax.md](syntax.md).

General Bend 2 knowledge (language core, Base API, proof technique, GPU tuning, the compiler repo) is
in the third-party `bend2-mega-skill`, which was written against 2.0.13/2.0.16. Section 13 lists every
place where our pinned 2.0.25 behaves differently from what that skill says.

**Evidence.** Every `bend` code block below is a complete file. It was compiled with the pinned
compiler, and its first comment lines state the outcome it must produce (`# expect: error <text>`
for "before" examples; no directive means `All terms check.`). Re-run all of them with:

```sh
node docs/bend/check-snippets.mjs     # report in tmp/bend-docs-check/results.txt
BEND_DOCS_CHECK_OUT=tmp/x node docs/bend/check-snippets.mjs   # another output dir; full log in full.txt
```

Imports written `import ./real.bend as R` resolve as if the file lived in `kernel/`. Error counts come from 591 unique errors observed in 10,378 Bend-related commands during development (2026-09-24). Claims marked **[unverified]** come from repo docs or development notes and were not reproduced.

## Contents

1. [The compile-fix loop](#1-the-compile-fix-loop)
2. [Errors, most frequent first](#2-errors-most-frequent-first)
3. [Idioms the kernel uses](#3-idioms-the-kernel-uses)
4. [Performance](#4-performance)
5. [Targets and native limits](#5-targets-and-native-limits)
6. [Testing lanes](#6-testing-lanes)
7. [R.*: F32x2 reals](#7-r-f32x2-reals)
8. [Exact predicates](#8-exact-predicates)
9. [bend-collections and kernel/lib](#9-bend-collections-and-kernellib)
10. [LAWS.bend and PROOF.bend](#10-lawsbend-and-proofbend)
11. [Module structure](#11-module-structure)
12. [Loader and cache](#12-loader-and-cache)
13. [Where 2.0.25 differs from the mega skill](#13-where-2025-differs-from-the-mega-skill)
14. [Unverified claims](#14-unverified-claims)

---

## 1. The compile-fix loop

Fastest feedback first. Timings are from 2026-09-24 on the shared M5 Pro. `bend` in commands means
`.tools/bend-2.0.25/bin/bend` (there is no `bend` on PATH; `npm run setup` installs the pin).

| step | command | typical time |
|---|---|---|
| 1. one file | `BEND_NO_TELEMETRY=1 .tools/bend-2.0.25/bin/bend kernel/x.bend --check-only` | 0.3-0.5 s |
| 2. the gate | `npm run -s check:bend` (= `bend PROOF.bend`) | 3.5 s |
| 3. JS reference, one def | `WONKY_BEND_CACHE=0 node --input-type=module -e "..."` (section 12) | ~1 s + run |
| 4. focused tests | `node scripts/test-lane.mjs files <x>.test.mjs` or `npm run -s test:changed` | seconds to minutes |
| 5. native emit (records widened, native code touched) | `bend x.bend -o out/x.c` | 1-30 s |
| 6. cpu1 run | `bend x.bend -o out/x && out/x --threads 1 --gpu off` | build 1.5 s for a tiny file |
| 7. integration / verify only | `npm test`, `npm run -s test:slow`, cpuN, Metal harnesses | minutes |

Rules for the loop:

- **Fix only the first error, then re-run.** The checker stops at the first failing def. A parse
  error's `observed` is the next character (`'1'`, `'('`), not the mistake: read the `Location:`
  line marked `>|`.
- **A kernel module is also an entry.** Tests `loadBend(kernel/x.bend)` and you check it with
  `bend kernel/x.bend --check-only`; both make `x.bend` the entry file. Check it standalone, not
  only through `PROOF.bend` (see the constructor clash in 2.3).
- **The checker never reports native limits.** A constructor over 255 fields passes `--check-only` and
  fails only at `-o x.c` (section 5.1). Emit C whenever you widen a record or touch native-bridge code.
- **Look names up instead of guessing:** `bend base U32.is_eq`, `bend base List.foldr`, `bend base --types`.
  `bend base U32.eq` answers `Base has no U32.eq`. `bend version` prints the version (`--version` is
  an unknown option in 2.0.25).
- **Set `BEND_NO_TELEMETRY=1`** (the scripts do; it skips the daily network ping).
- Put scratch files under `tmp/`, never next to kernel files other agents are editing.

---

## 2. Errors, most frequent first

| class | unique errors | share |
|---|---:|---:|
| types (inference, kinds, cases, operators) | 137 | 23% |
| affinity (consumed more than once) | 125 | 21% |
| names and definition order | 113 | 19% |
| match and scrutinee rules (236 raw: the most re-run class) | 94 | 16% |
| native, Metal and stack limits | 34 | 6% |
| syntax and keywords | 32 | 5% |
| laws and proofs | 27 | 5% |
| termination and fuel | 21 | 4% |
| CLI, runtime traps, imports | 8 | 1% |

### 2.1 Types (137)

**Cannot infer a let-bound literal, list, constructor or lambda (51).** Inference is minimal. A
let-bound value has no expected type.

```bend
# expect: error an annotated term (cannot infer)
import Base

def quarter() -> F32:
  +h = 0.5
  (h * h : F32)
```

Annotate with `{v : T}`, or use a typed let `x : T = v` (allowed outside `do` in 2.0.25):

```bend
import Base

def quarter() -> F32:
  +h = {0.5 : F32}
  (h * h : F32)

def pair_list() -> List<&2, U32>:
  xs = {[1, 2] : List<&2, U32>}
  xs

def bump(x: U32) -> U32:
  g : U32 -> U32 = y => (y + 1 : U32)
  g(x)
```

**Every arithmetic, comparison, bitwise and shift operator needs a type.** A bare one is an error,
even inside parentheses. Until 2.0.16 it silently meant `Nat`; the mega skill still says so. Inner
parentheses inherit the outer `: T` (`((a + b) * c : U32)` checks), call arguments do not:
`(F32.abs(a - b) * c : F32)` fails, `(F32.abs((a - b : F32)) * c : F32)` checks (a real corpus error). `&&`, `||` (Bool), `++` (String) and
`<>` (cons) are fixed to their types and need no annotation (`bend.ts` `INFIX_OPS`, `parse_term_ns`).

```bend
# expect: error a type for this operator
import Base

def add(a: U32, b: U32) -> U32:
  (a + b)
```

**Shifts take a `Nat`, equality is a call, xor is `.^.`.** `>>` is `U32.shrn(a, n: Nat)`.
`(a == b : U32)` and `(a ^ b : U32)` are parse errors (`expected : ')'`). `U32.shr(x)` shifts by one
and takes one argument.

```bend
# expect: error expected : Nat
import Base

def half(x: U32) -> U32:
  (x >> 1 : U32)
```

```bend
# expect: error expected : ')'
import Base

def same(a: U32, b: U32) -> Bool:
  (a == b : U32)
```

```bend
import Base

def half(x: U32) -> U32:
  (x >> 1n : U32)

def same(a: U32, b: U32) -> Bool:
  U32.is_eq(a, b)

def flip(a: U32, b: U32) -> U32:
  (a .^. b : U32)

def below(a: F32, b: F32) -> Bool:
  (a < b : F32)

def scaled(a: U32, b: U32, c: U32) -> U32:
  ((a + b) * c : U32)

def either(a: Bool, b: Bool, c: Bool) -> Bool:
  a && b || c

def greet(name: String) -> String:
  "hi " ++ name
```

```bend
# expect: error a type for this operator
import Base

def gap(a: F32, b: F32, c: F32) -> F32:
  (F32.abs(a - b) * c : F32)
```

```bend
import Base

def gap(a: F32, b: F32, c: F32) -> F32:
  (F32.abs((a - b : F32)) * c : F32)
```

**`Data` expected, `Type` observed (18).** A `Data` type can be copied with `+`; it cannot hold a
`Type` value: a function, an `Array`, a handle, or any `is Type` record such as `IdVec`.

```bend
# expect: error expected : Data
import Base

type Box is Type:
  Box{f: U32 -> U32}

type Holder is Data:
  Holder{b: Box}
```

```bend
import Base

type Box is Type:
  Box{f: U32 -> U32}

type Holder is Type:
  Holder{b: Box}
```

`+b: Box` on a parameter fails the same way. Thread `Type` values through (every `IdVec` operation
hands the vector back).

**Missing cases after a type grows (18).** 13 of the 18 were `cases for analytic.Sphere,
analytic.Torus`: `analytic.Solid` gained constructors and every old `match` broke. When you add a
constructor, grep the kernel for matches on that type and update every one.

```bend
# expect: error cases for
import Base

type Shape is Data:
  SCircle{r: F32}
  SSquare{s: F32}
  SSphere{r: F32}

def is_round(s: Shape) -> Bool:
  match s:
    case SCircle{_}:
      True{}
    case SSquare{_}:
      False{}
```

```bend
import Base

type Shape is Data:
  SCircle{r: F32}
  SSquare{s: F32}
  SSphere{r: F32}

def is_round(s: Shape) -> Bool:
  match s:
    case SSquare{_}:
      False{}
    case _:
      True{}
```

**Quantities must line up exactly (10).** `List<U32>` is `List<&1, U32>`; wonky uses `List<&2, T>`
everywhere, and there is no upcast. A def passed as `~f` must have exactly the expected parameter
quantities: `inc(+x: U32)` is `@+x:U32 -> U32`, not `U32 -> U32`.

```bend
# expect: error List<&1, U32>
import Base

def keep(xs: List<&2, U32>) -> List<U32>:
  xs
```

```bend
# expect: error @+x:U32 -> U32
import Base

def inc(+x: U32) -> U32:
  (x + 1 : U32)

def twice(~f: U32 -> U32, x: U32) -> U32:
  f(f(x))

def two(x: U32) -> U32:
  twice(~inc, x)
```

Fix: `def inc(x: U32) -> U32` (it uses `x` once), or a wrapper def with the plain signature.

### 2.2 Affinity: `x (consumed more than once)` (125)

A plain binder is used at most once per path. Mark reuse with `+` where the name is bound: parameter
`+x`, let `+y = ...`, pattern `case +h <> +t`, `Real{+hi, lo} = r`, Nat predecessor `case 1n+ +p`
(or `1n++p`). `+` needs a `Data` type. Uses in different match branches do not add up; the two
calls of a parallel let do. The most reported names were `acc` (15), `p` (10), `t` (8), `f` (7).

```bend
# expect: error acc (consumed more than once)
import Base

def twice_plus(acc: U32, x: U32) -> U32:
  ((acc + x : U32) + acc : U32)
```

```bend
# expect: error p (consumed more than once)
import Base

def countdown(n: Nat) -> List<&2, U32>:
  match n:
    case 0n:
      Nil{}
    case 1n+p:
      U32.from_nat(p) <> countdown(p)
```

```bend
import Base

def twice_plus(+acc: U32, x: U32) -> U32:
  ((acc + x : U32) + acc : U32)

def countdown(n: Nat) -> List<&2, U32>:
  match n:
    case 0n:
      Nil{}
    case 1n+ +p:
      U32.from_nat(p) <> countdown(p)

def dup_heads(xs: List<&2, U32>) -> List<&2, U32>:
  match xs:
    case Nil{}:
      Nil{}
    case +h <> t:
      h <> h <> dup_heads(t)
```

**`Bool.pick` consumes both arms**, so a tail used in both arms is consumed twice (and both arms are
computed, see 4.1). Use a match helper:

```bend
# expect: error rest (consumed more than once)
import Base

def push(+x: U32, xs: List<&2, U32>) -> List<&2, U32>:
  match xs:
    case Nil{}:
      [x]
    case +y <> rest:
      Bool.pick(List<&2, U32>, U32.is_eq(x, y), y <> rest, x <> y <> rest)
```

```bend
import Base

def push.k(same: Bool, x: U32, y: U32, rest: List<&2, U32>) -> List<&2, U32>:
  match same:
    case True{}:
      y <> rest
    case False{}:
      x <> y <> rest

def push(+x: U32, xs: List<&2, U32>) -> List<&2, U32>:
  match xs:
    case Nil{}:
      [x]
    case +y <> rest:
      push.k(U32.is_eq(x, y), x, y, rest)
```

**Closures are single-use, and `+` does not apply to functions.** Take a function you call twice as a
template `~f`. A `~` argument must be closed: top-level defs and closed lambdas, no locals.

```bend
# expect: error f (consumed more than once)
import Base

def app2(f: U32 -> U32, x: U32) -> U32:
  f(f(x))
```

```bend
import Base

def inc(x: U32) -> U32:
  (x + 1 : U32)

def app2(~f: U32 -> U32, x: U32) -> U32:
  f(f(x))

def plus2(x: U32) -> U32:
  app2(~inc, x)
```

### 2.3 Names and definition order (113)

**Define before use (81).** Every def and type must appear above its first use. 46 of the mined
cases were helpers such as `f.k`, `f.if`, `f.go` placed below their caller.

```bend
# expect: error a defined name
import Base

def count_eq(xs: List<&2, U32>, +k: U32) -> U32:
  match xs:
    case Nil{}:
      0
    case h <> t:
      count_eq.k(U32.is_eq(h, k), count_eq(t, k))

def count_eq.k(hit: Bool, rest: U32) -> U32:
  match hit:
    case True{}:
      (rest + 1 : U32)
    case False{}:
      rest
```

```bend
import Base

def count_eq.k(hit: Bool, rest: U32) -> U32:
  match hit:
    case True{}:
      (rest + 1 : U32)
    case False{}:
      rest

def count_eq(xs: List<&2, U32>, +k: U32) -> U32:
  match xs:
    case Nil{}:
      0
    case h <> t:
      count_eq.k(U32.is_eq(h, k), count_eq(t, k))
```

**No mutual recursion.** It can never be ordered. Merge the two defs into one with a selector
argument, or have the non-recursive half return a value the recursive caller acts on (section 3).

```bend
# expect: error a defined name
import Base

def is_even(n: Nat) -> Bool:
  match n:
    case 0n:
      True{}
    case 1n+p:
      is_odd(p)

def is_odd(n: Nat) -> Bool:
  match n:
    case 0n:
      False{}
    case 1n+p:
      is_even(p)
```

```bend
import Base

def parity(n: Nat, want_even: Bool) -> Bool:
  match n:
    case 0n:
      want_even
    case 1n+p:
      parity(p, Bool.not(want_even))
```

**Constructor names clash with Base (17).** Constructor names are global to a namespace, and the
entry file shares its namespace with Base, which owns `Done`, `Fail`, `Some`, `None`, `Nil`, `Con`,
`True`, `False`, `LT`/`EQ`/`GT`, `Tuple`, `Unit`, `WNil`/`WCon`, `Zero`/`Succ` and more.

```bend
# expect: error duplicate declaration: Done
import Base

type Walk is Data:
  Done{}
  Step{n: U32}
```

Prefix every constructor with its type (`WDone{}`, `WStep{..}`). The trap in wonky: a module that
declares `Done{}` **passes** when imported (by `PROOF.bend`, so `npm run check:bend` is green) and
**fails** when it is the entry, which is what `bend kernel/x.bend --check-only` and
`loadBend(kernel/x.bend)` do (verified with the CLI: `tmp/bend-skill/snippets/skill/delta/mods/done.bend`
vs `d18_import_done.bend`; the loader compiles the same entry file). Two types in one file also cannot share a constructor name.

**Keywords are not names (9).** `def type law match case do return for exs where is import Type
Data Kind Quant`. `as`, `if` and `cases` are not reserved. Rename: `SurfKind`, `where_of`, `exs_`.

```bend
# expect: error got the keyword 'Kind'
import Base

type Kind is Data:
  Planar{}
  Curved{}
```

**No field access with dots.** `p.x` is looked up as a def (dots are ordinary name characters, which
is why `f.k` helpers work). Destructure instead. There are no generated accessors (`B.FCtx.pos`
does not exist).

```bend
# expect: error a defined name
import Base

type P is Data:
  P{x: U32, y: U32}

def px(p: P) -> U32:
  p.x
```

```bend
import Base

type P is Data:
  P{x: U32, y: U32}

def px(p: P) -> U32:
  P{x, _} = p
  x
```

**Aliases are not transitive (5).** If `p.bend` imports `r.bend as R`, then `P.R.Real` does not
exist: import `r.bend` yourself (`tmp/bend-skill/snippets/errs/i_transitive.bend`). Qualify imported
types and constructors (`R.Real{hi, lo}`, `case RP.Positive{}:`); a bare `Positive{}` is `a declared
constructor (unknown: Positive)`. Import each module through one canonical relative path, otherwise
`one namespace per file (... is both 'a' and 'b')`.

### 2.4 Match and scrutinee rules (94 unique, 236 raw)

A `match` or a destructuring let (`K{a, b} = v`, `(a, b) = v`) sees only **a parameter or a field bound
by an earlier pattern**, in declaration order, and **before any let**. It never sees a computed value
or a let-bound local. Shape every def as "destructure parameters in order, then compute". Branch on
anything computed through a helper def (defined above, rule 2.3).

```bend
# expect: error a match on a parameter or field
import Base

type P is Data:
  P{x: U32, y: U32}

def scaled_sum(+k: U32, p: P) -> U32:
  k2 = (k * 2 : U32)
  P{x, y} = p
  ((x + y : U32) * k2 : U32)
```

```bend
import Base

type P is Data:
  P{x: U32, y: U32}

def scaled_sum(+k: U32, p: P) -> U32:
  P{x, y} = p
  k2 = (k * 2 : U32)
  ((x + y : U32) * k2 : U32)
```

Matching a later parameter before an earlier one fails the same way. Match in declaration order,
or use one multi-scrutinee match:

```bend
# expect: error a match on a parameter or field
import Base

def both(a: Bool, b: Bool) -> U32:
  match b:
    case True{}:
      match a:
        case True{}:
          3
        case False{}:
          2
    case False{}:
      0
```

```bend
import Base

def both(a: Bool, b: Bool) -> U32:
  match a b:
    case True{} True{}:
      3
    case False{} True{}:
      2
    case _ False{}:
      0
```

A computed scrutinee, a let-bound local, and a destructured call result are all rejected:

```bend
# expect: error cannot scrutinize a computed value
import Base

def nonzero(x: U32) -> U32:
  match U32.is_eq(x, 0):
    case True{}:
      0
    case False{}:
      1
```

```bend
# expect: error cannot scrutinize a local binder
import Base

def nonzero(x: U32) -> U32:
  zero = U32.is_eq(x, 0)
  match zero:
    case True{}:
      0
    case False{}:
      1
```

```bend
# expect: error cannot scrutinize a computed value
import Base

def split(+x: U32) -> U32 & U32:
  (x, (x + 1 : U32))

def total(x: U32) -> U32:
  (a, b) = split(x)
  (a + b : U32)
```

The fix is always a helper whose **parameter** is the value:

```bend
import Base

def nonzero.k(zero: Bool) -> U32:
  match zero:
    case True{}:
      0
    case False{}:
      1

def nonzero(x: U32) -> U32:
  nonzero.k(U32.is_eq(x, 0))

def split(+x: U32) -> U32 & U32:
  (x, (x + 1 : U32))

def total.k(r: U32 & U32) -> U32:
  (a, b) = r
  (a + b : U32)

def total(x: U32) -> U32:
  total.k(split(x))
```

Other match rules: `match` cannot appear inside a lambda (reported as `a match on a parameter or
field`; `delta/d19_lambda_match.bend`); matching the same value twice in nested cases, or destructuring
a tuple literal (`(a, b) = (acc, 1)`), gives `an undestructed scrutinee` (fold it into the outer case);
a destructure lists every field (`a EC pattern with 8 fields`), so when a record gains a field, grep
`Ctor{` and update every destructure; a one-row destructure `K{..} = v` of a type with several
constructors is `cases for ...`; an erased `-x` cannot be matched in live code (`a live scrutinee`).
(Probes: `tmp/bend-skill/verify/probes.md`, `probes5.md`.)

### 2.5 Native, Metal and stack limits (34)

See section 5. The messages: `Error: an arity over 255` (emit time), `Maximum call stack size exceeded`
(JS under `loadBend`), `bend: memory fault (machine stack overflow?)` (native, Metal, and also the JS
lane of `bend x.bend`), `Error: the machine stack overflowed (a deep recursion, or a literal too large
to expand)` (the checker normalizing huge proof terms or computed Nats),
`bend: out of memory: run again with a bigger span, as in --gpu 8GB`.

### 2.6 Syntax and keywords (32)

**No negative literals.** A `-` glued to a token heads a binder.

```bend
# expect: error expected : a name
import Base

def minus_one() -> F32:
  -1.0
```

```bend
import Base
import ./real.bend as R

def minus_one() -> F32:
  F32.neg(1.0)

def minus_one_b() -> F32:
  (0.0 - 1.0 : F32)

def minus_one_real() -> R.Real:
  R.neg(R.from_f32(1.0))
```

Also: no `if` (`if c:` gives `expected : '='`), no `|>` pipe, spaces around operators (`(a>b : U32)`
fails), constructors always with braces (`True{}`; a bare `True` is `a defined name` as a term),
imports only at the head of the file, and every non-law def declares `-> T`. In `do` blocks, every
bind is typed (`x : T <- m`) and destructuring is not allowed; destructure in a helper def. Prefer an
explicit `IO.bind(...)` over a typed `<-` bind with a compound type (4 mined failures).

### 2.7 Laws and proofs (27)

Live code cannot call a law without a proof def:

```bend
# expect: error a filled definition
import Base

law foo:
  for x: U32
  U32

def g(x: U32) -> U32:
  foo(x)
```

20 of the 27 were proof goals that did not normalize to the stated equation (arithmetic lemmas in
`kernel/laws/spike`). Fix by chaining `Equal.cong`/`Equal.sym` rewrites or splitting into smaller
lemmas. Nothing about F32 is provable: F32 ops are bodiless Base laws. See section 10.

### 2.8 Termination and fuel (21)

Arguments are read **left to right**: each must be passed unchanged until one is a strict subterm of
its parameter's pattern (`t` from `h <> t`, `p` from `1n+p`); every argument after it is free.
`Nat.sub(n, 1n)`, `tail(xs)` and any computed value count as not shrinking.

```bend
# expect: error a decreasing self-call
import Base

def fan(+base: U32, +i: U32, l: Nat) -> List<&2, U32>:
  match l:
    case 0n:
      Nil{}
    case 1n+rest:
      (base + i : U32) <> fan(base, (i + 1 : U32), rest)
```

```bend
import Base

def fan(l: Nat, +base: U32, +i: U32) -> List<&2, U32>:
  match l:
    case 0n:
      Nil{}
    case 1n+rest:
      (base + i : U32) <> fan(rest, base, (i + 1 : U32))
```

When nothing shrinks structurally (halving, Newton, graph walks, fixpoints), add `fuel: Nat` as the
**first** parameter. Fuel exhaustion returns an explicit error value, never a silent truncation
(AGENTS.md: capability errors):

```bend
import Base

type Steps is Data:
  Reached{n: U32}
  OutOfFuel{}

def steps(fuel: Nat, zero: Bool, +x: U32, n: U32) -> Steps:
  match fuel zero:
    case _ True{}:
      Reached{n}
    case 0n False{}:
      OutOfFuel{}
    case 1n+left False{}:
      steps(left, U32.is_eq((x >> 1n : U32), 0), (x >> 1n : U32), (n + 1 : U32))

def halvings(+x: U32) -> Steps:
  steps(33n, U32.is_eq(x, 0), x, 0)
```

Do not use `@unsafe` to dodge descent: the verdict then reads `All terms check, but N defs rely on
unsafe or foreign code` (exit code 0, so `npm run check:bend` stays green: the gate hole in
section 10). The kernel keeps `@unsafe` to the service event loop (`kernel/service/binding/probe.bend`).

### 2.9 CLI and runtime (8)

`bend --version` is an unknown option (use `bend version`); there is no `--target` (the `-o`
extension picks it: `x.c`, `x.js`, or a binary); `--threads` and `--gpu` (`on`, `off` or a size such
as `8GB`) are flags of the built binary, not of `bend` (`bend x.bend --gpu off` is `unknown option`);
building a file without `main` (`-o`) says `Error: no main to run`, while `bend x.bend` just prints
`All terms check.` (use `--check-only`). Runtime traps:
`bend: a Nat past the largest immediate 2^48-1` (native and JS; keep counters in U32 or bound them)
and `runtime fail-stop` (inspect on the JS target first).

---

## 3. Idioms the kernel uses

**The `.k` / `_pick` helper.** Compute a `Bool` (or a `Cmp`, a `Decision`) in the caller, pass it to a
helper that matches its first parameter and computes each arm inside its own case. `kernel/real.bend`
`sqrt -> sqrt_pick`, `atan2 -> atan2_pick`; Base's `U32.div.if`. Define the helper above the caller.

**The `*_done` pair helper.** Container operations return `(container, answer)`. Pass that pair to the
next def as a parameter and destructure it there (`kernel/lib/id-vec.bend` `length_done`, `get_done`;
section 9).

**Carry a decision through the recursion** instead of recomputing it or calling back:
`steps(fuel, zero, ...)` in 2.8, `kernel/tessellate.bend` `refine(fuel, ok, ...)`,
`kernel/sketch-arcs.bend` merge sort with `right_first`.

**Replace mutual recursion** with one recursive def and a selector or a `Task`/`Step` constructor that
says which role runs next; non-recursive halves return the next task instead of calling back
(docs/language/bend-feasibility.md:171-180).

**Tail recursion with a reversed accumulator.** Loops over data-sized lists must be tail calls (4.2):

```bend
# expect-run: 12
# expect-native: 12
import Base

def double_rev(xs: List<&2, U32>, acc: List<&2, U32>) -> List<&2, U32>:
  match xs:
    case Nil{}:
      acc
    case h <> t:
      double_rev(t, (h * 2 : U32) <> acc)

def double(xs: List<&2, U32>) -> List<&2, U32>:
  List.reverse(&2, U32, double_rev(xs, Nil{}))

def sum(xs: List<&2, U32>, acc: U32) -> U32:
  match xs:
    case Nil{}:
      acc
    case h <> t:
      sum(t, (acc + h : U32))

def main() -> IO(Unit):
  IO.print(U32.show(sum(double([1, 2, 3]), 0)))
```

**Multi-column match.** `match fuel arcs:` with one pattern per scrutinee; put the list column first
where it drives recursion; write explicit constructors, no whole-scrutinee binders.

**Explain Bend-forced shapes** in a comment above the def (`kernel/step-pcurves.bend:769-770`,
`kernel/tessellate.bend:41-42`).

---

## 4. Performance

### 4.1 `Bool.pick` evaluates both arms

Evaluation is strict. `Bool.pick(T, c, a, b)` is an ordinary def, so `a` and `b` are both computed
before it picks. `Bool.and`, `Bool.or`, `&&`, `||` also evaluate both sides (verified 2.0.25: a trapping
right side of `Bool.or(True{}, ..)` and `(True{} || ..)` fail-stops on JS and cpu1). Measured: a pick
with a slow arm took 7.6 s against 0.2 s for a match helper on JS
(`tmp/bend-skill/snippets/syntax/v01a_pick.bend` vs `v01b_match.bend`) and 4.9 s against 0.4 s natively
with a runtime condition (`tmp/bend-skill/verify/native/pick_rt*.bend`; only a literal `True{}`
condition gets folded away by the native compiler); in the fillet prototype a comb case went from over 2 min to 277 ms by replacing
picks around recursive calls with `cons_if`/`inc_if` match helpers (docs/fillet/proto-rollingball.md:556-560).

- Fine: `Bool.pick` over cheap, already-computed values (`R.abs`, `R.max`, `R.min` do this).
- Never: a recursive call or an expensive computation in an arm. A walk with a recursive call in a
  pick arm does the recursion even when it is done, and turns exponential with several such arms.
- Also never for short-circuit guards over expensive predicates: write a match helper.

### 4.2 Stack depth

- JS target: Base `List.length`, `List.foldr` and `List.sort` are not tail-recursive. Measured with
  2.0.25 (`tmp/bend-skill/verify/probes4.md`, `verify/loader/len.bend`): `List.length` over a list
  overflows at 10k elements under `loadBend` (5k passes; plain Node stack, `Maximum call stack size
  exceeded`) and at 30k in `bend x.bend` (20k passes; `memory fault (machine stack overflow?)`); cpu1
  handles 100k. docs/proto-exact-plane.md:579-584 reports ~50k with an 8 MB stack. Tail calls use no
  stack on JS (a tail loop over 1M elements runs under `loadBend`).
- Production limits seen: merge overflowed at 2,500 elements until made tail-recursive; prisms with
  1,536+ faces overflowed in `identity.bend` roles (development evidence kept locally).
- Metal: any non-tail recursion over a long list overflows the device stack (`memory fault (machine
  stack overflow?)`); a 240-edge gear polygon did until `poly_keep` became tail-recursive
  (docs/proto-sdf.md:196-199).
- The checker itself overflows (`Maximum call stack size exceeded`) when proofs normalize huge
  `Word`/`U32`/Nat terms: prove over small lemmas, keep big terms opaque.

### 4.3 Fork-join on the CPU pool

Parallel lets `a b = f(x) g(y)` fork. What the measurements in this repo say:

- **Sharing kills scaling.** Each lane that reads a shared `+` value pays an atomic refcount
  operation per read (`bend guide`, "what the lanes share"). Keep single ownership of big data in
  parallel phases (docs/proto-corefine.md:443-446, 590-591).
- **Fork only near the top.** Forking every level of a tree join was 5x slower at 18 threads than
  forking the top 5 levels (docs/proto-recover.md:826-831). After a non-tail self call whose callee
  forked, later parallel lets in that frame ran sequentially (docs/proto-corefine.md:447-452).
- **Hoist per-node bookkeeping out of branch nodes:** 2.15 s to 0.59 s (docs/hardware-performance.md:60-72).
- **Small work does not scale:** 6 threads gave 1.5-1.7x on the planar kernel
  (docs/native-bridge/binding.md:297). Fillets and Booleans run on the CPU pool with `--gpu off`
  (docs/fillet-plan.md:388-393).

A balanced binary fork tree (the depth shrinks first, both halves equal):

```bend
# expect-run: 120
import Base

def tree_sum(depth: Nat, +lo: U32) -> U32:
  match depth:
    case 0n:
      lo
    case 1n+ +d:
      a b = tree_sum(d, (lo * 2 : U32)) tree_sum(d, (lo * 2 + 1 : U32))
      (a + b : U32)

def main() -> IO(Unit):
  IO.print(U32.show(tree_sum(4n, 0)))
```

### 4.4 Metal (`f!(x)`)

- **Never make the whole build the device call.** It overflowed the machine stack on 68 of 70 cases;
  making only the station solve the device call took the build from 504 s to 35 s
  (docs/fillet/proto-rollingball.md:561-564).
- Device work must be flat numeric: flat F32 records, a fork tree, flat loops; no lists, no Big ints.
  List-heavy divergent code is 20-40x slower on Metal (docs/fillet/proto-kpart.md:331-332).
- A `!` after host forks in the same evaluation falls back to the CPU pool: separate stages with
  `IO.now` steps (docs/proto-corefine.md:459-468).
- Fixed costs: ~35 ms per Metal pass, 18.97 s Metal compile vs 1.47 s ARM64
  (docs/hardware-performance.md:86-87). The harness caps the device heap at 1 GB; big jobs need
  `--gpu 8GB`.
- **Prove Metal ran:** count `wonky_metal_passes` / `metalPasses >= 1`; otherwise a silent CPU
  fallback is not a GPU measurement (docs/hardware-performance.md:97-101).

### 4.5 Lists versus collections

`List.get` and list scans are O(n). r10b spent 94% of kernel self time in four list folds; the
IdVec/IdSet rewrite took the kernel from 68.0 s to 2.6 s, byte-identical (docs/collections.md:3-11).
Stop fixpoint loops at the fixpoint, not after E passes (1539 ms to 68 ms,
docs/fillet/proto-kpart.md:333-334). Prepare per-operand data once, not per query.

---

## 5. Targets and native limits

**Order: JS reference first, cpu1 next, cpuN and Metal only in integration/verify.**

| lane | how | use it for |
|---|---|---|
| JS reference | `loadBend` in tests, `bend x.bend` for an IO main | correctness, differential oracle; sequential; 5-35x slower than native |
| cpu1 | `bend x.bend -o out/x`, `out/x --threads 1 --gpu off -- in out` | deterministic native run; catches the 255-word limit and Nat/stack fail-stops |
| cpuN | `--threads N --gpu off` | integration and benchmarks only |
| Metal | `--gpu 1GB` (harness), `!` calls, `-DBEND_METAL=1` builds | verify/bench stage only, one device call per stage |

Never infer native or GPU speed from the JS target (AGENTS.md). Results must agree byte for byte
across js/cpu1/cpuN/metal (`targetsAgree`, docs/bakeoff.md:287-288).

### 5.1 The 255-word limit

The C backend flattens non-recursive records (sum types too) into words; `U32`, `F32` and `Nat` are one
word each, and arity tables are one byte. Emitting C fails with `Error: an arity over 255` when that
byte overflows. `--check-only` and the JS target never report it: **run `-o x.c` whenever you widen a
record.** What was verified with 2.0.25 (`tmp/bend-skill/snippets/errs/` and `snippets/skill/delta/`):

| case | result |
|---|---|
| one constructor with 300 `U32` fields (`errs/x_wide.bend`, `delta/d21`) | checks clean, **fails** at `-o x.c` |
| the same with a never-built recursive constructor added (`delta/d22`) | **still fails**: boxing does not help a single constructor over 255 fields |
| two 150-field sub-records inside one record (`errs/x_nested.bend`) | emits and runs |
| two 150-field records live across a non-tail call, flat or boxed (`delta/d23`, `d24`, `d25`) | emits and runs: the backend boxes multi-word values itself (`lay_wide`, `comp.ts:985-989`) |
| a single 300-operand `( ... : U32)` chain (`tmp/bend-skill/verify/probes5.md` q7) | `-o x.c` succeeds; the binary build `-o x` then **fails in clang**: `bracket nesting level exceeded maximum of 256` |

Rule: no constructor with more than 255 one-word fields. Group scalars into sub-records (below), or
hold long data in a list or an `IdVec`. The kernel also uses a never-built constructor to keep a wide
record boxed (`BlendNil{next: Blend}`, kernel/proto/fillet-rollingball/brep.bend:66-77, "two of them in
one continuation break the backend's 255-word limit"); that failure did not reproduce in these probes,
so treat the boxing trick as **[unverified in 2.0.25]** and check with `-o x.c`. Still blocked in the
kernel: `ports/curved-intersection.bend:intersect` (docs/native-bridge.md, section 1; not re-run here).

```bend
# expect-c: ok
import Base

# Scalars grouped into sub-records: each constructor stays far below 255 fields.
type Frame is Data:
  Frame{ox: F32, oy: F32, oz: F32, nx: F32, ny: F32, nz: F32}

type Station is Data:
  Station{id: U32, left: Frame, right: Frame}

def station_id(s: Station) -> U32:
  Station{id, _, _} = s
  id

def main() -> IO(Unit):
  +f = {Frame{0.0, 0.0, 0.0, 0.0, 0.0, 1.0} : Frame}
  IO.print(U32.show(station_id(Station{7, f, f})))
```

### 5.2 Other native facts

- `Nat` is a 48-bit immediate: past `2^48-1` the runtime fail-stops (JS and native).
- U32 wraps mod 2^32; `a / 0` is 0; `a % 0` is `a`; shifts by 32 or more give 0; `F32.to_u32` truncates
  and gives 0 for negative input ([syntax.md](syntax.md), section 6).
- `match` compiles to if/else with the last arm as the else: an out-of-range tag runs the last arm.
- Only defs reachable from `main` are emitted; there is no library mode or FFI beyond custom effects
  (`def e() -> IO(R)` with `import "./e.c"` / `"./e.js"`).
- Fail-stops on the calling thread are catchable in the native bridge (`BX_FAILSTOP`); on a pool worker
  (threads > 1 or any `!`) the process exits 1 (docs/native-bridge/binding.md:252-262).
- Full kernel relinks are expensive: 27 s and 7 GiB compiler RSS; cold JS compile of the full hull
  394 s (docs/native-bridge/surface.md:316). Import only what a file needs.

### 5.3 F32 across targets

- **Compare by bits, not by text.** `F32.show(20713.8125)` prints `20713.813` on JS and `20713.812`
  natively (verified 2.0.25, `delta/d20_f32_show.bend`).
- Metal flushes subnormals; JS and ARM64 keep them. Decide near-zero by an explicit threshold, and
  range-guard anything that relies on gradual underflow before it runs on Metal
  (docs/research/robust-numerics.md:171-197).
- NaN payload bits differ across targets: compare NaN as a class.
- No FMA anywhere: native C uses `#pragma clang fp contract(off)`, Metal `MTLMathModeSafe`.

---

## 6. Testing lanes

| command | what |
|---|---|
| `npm run -s check:bend` | `bend PROOF.bend`: laws plus type/termination check of every imported kernel file |
| `npm run -s test:fast` | test files recorded under 20 s, fail-fast |
| `npm run -s test:changed` | test files that mention a file changed against HEAD, fail-fast |
| `node scripts/test-lane.mjs files a.test.mjs b.test.mjs` | exactly these files |
| `npm run -s test:slow` | end-to-end, OCCT, corpus |
| `npm test` | `check:bend` + every `test/*.test.mjs` (required before handing off relevant changes) |
| `node --test test/robust-predicates.test.mjs` | exact predicates against a BigInt oracle |
| `node --test test/collections.test.mjs` (`WONKY_COLLECTIONS_NATIVE=1` for native, ~30 s) | adapters |
| `uv run scripts/validate-step.py <prefix> ...` | STEP exports, when geometry/export changes |

`--fail-fast` is for development loops only; integration and verification runs want every failure.
The machine is shared: record load or use `process.cpuUsage` when timing.

---

## 7. R.*: F32x2 reals

`kernel/real.bend` (import as `R`): `Real{hi: F32, lo: F32}`, `from_f32`, `approx`, `renorm`, `neg`,
`add`, `sub`, `mul`, `div`, `less`, `equal`, `abs`, `max`, `min`, `sqrt` (exact 0 for 0), `pi`,
`atan`, `atan2`, `sin`, `cos`, `reduce_angle`. There is no F64 and no I64 in Bend.

```bend
import Base
import ./real.bend as R

def hyp(+a: F32, +b: F32) -> R.Real:
  R.sqrt(R.add(R.mul(R.from_f32(a), R.from_f32(a)), R.mul(R.from_f32(b), R.from_f32(b))))

def clamp_one.k(over: Bool, x: R.Real) -> R.Real:
  match over:
    case True{}:
      R.from_f32(1.0)
    case False{}:
      x

def clamp_one(+x: R.Real) -> R.Real:
  clamp_one.k(R.less(R.from_f32(1.0), x), x)

def hi_word(x: R.Real) -> F32:
  R.Real{hi, _} = x
  hi
```

Limits (docs/research/robust-numerics.md, docs/hybrid-robust.md):

- ~44-46 guaranteed bits; the exponent range stays F32's. It is a filter and evaluation type,
  **never exact**. Exact decisions go through `robust-predicates.bend`.
- `R.add` worst error 2^-46.83 of the operand magnitude, but relative error under cancellation is poor
  (2^-13.5): scale filters by the operands.
- `mul` uses the Veltkamp split (4097); no FMA on any target.
- "Comparing two Reals is exact" assumes canonical `renorm` output, which is not proved. Words that come
  back from Bend are not always the encoder's canonical split: compare round trips by value.
- `0.1 + 0.2` in F32x2 is `0.2999999999999998`: FeatureScript double results are not bit-reproducible.
- F32 facts are not provable (bodiless Base laws), and a value-returning `main` prints stuck F32 terms:
  test F32 code through an IO main, the JS loader, or a native build.

---

## 8. Exact predicates

`kernel/robust-predicates.bend` (docs/robust-predicates.md):

- `point_plane(+normal, +point, +origin) -> Decision` and `classify(point: Point, +origin, +normal)`
  with `Point = Explicit{point} | LinePlane{first, last, origin, normal}` (vectors are `precise.bend`
  `Vec3 = V3{x, y, z: R.Real}`, built with `G.v3(x, y, z)`).
- `Decision{sign: Sign, method: Method}`; `Sign = Negative | ExactlyZero | Positive | Undefined`;
  `Method = FloatFilter | ExactDyadic | IndirectExact | Invalid`. **Always handle `Undefined`**
  (NaN/inf inputs, zero denominator).
- The sign is about the represented words, not a tolerance: callers still choose tolerances.
  `LinePlane` has no float filter and the line is unbounded (segment membership is separate).
- Exact tier: signed base-4096 digit lists decoded from F32 bits (subnormals included, FTZ-immune);
  the fast filter admits exponents 87..167 only. Cost native: exact 1.3-6.0 us, filter 0.10-0.20 us.

```bend
import Base
import ./precise.bend as G
import ./robust-predicates.bend as RP

def side.k(d: RP.Decision) -> U32:
  match d:
    case RP.Decision{RP.Positive{}, _}:
      1
    case RP.Decision{RP.Negative{}, _}:
      2
    case RP.Decision{RP.ExactlyZero{}, _}:
      0
    case RP.Decision{RP.Undefined{}, _}:
      3

def side(p: G.Vec3) -> U32:
  side.k(RP.point_plane(G.v3(0.0, 0.0, 1.0), p, G.v3(0.0, 0.0, 0.0)))
```

---

## 9. bend-collections and kernel/lib

- Never edit `kernel/vendor/bend-collections/src/`; wonky code goes to `kernel/lib/`. Verify the vendor
  tree with `node scripts/vendor/bend-collections.mjs [--offline]`.
- Adapters: `lib/id-vec.bend` (`IdVec<T>`, dense U32 id to T), `lib/id-set.bend` (`IdSet`, bitset of
  ids), `lib/keys.bend` (`IdPair`/`edge`/`pair_cmp`, `Key3`/`vec3_key`/`f32_order`, `then`). The tree map
  is used directly. The hash map is String-keyed only: not for ids.
- `IdVec` and `IdSet` are `is Type` (they own an array): thread them, never `+` them, never store them in
  a `Data` record. Every operation returns `(container, answer)`; pass the pair on as a parameter.
- Out-of-range reads return the caller's fallback; out-of-range writes return `False` and change nothing.
- Collections must not decide output order: keep scan tie-breaks (`put` keeps the last,
  `put_if_absent` the first). `vec3_key` is bit-exact, not a tolerance test.
- Import only what you need: the full 25-module probe costs 13.4 s cold JS compile against 0.1-0.44 s
  per adapter. On the JS target the tree map only wins above a few thousand entries.

```bend
import Base
import ./lib/id-vec.bend as IdVec

def read_answer(r: IdVec.IdVec<U32> & U32) -> U32:
  (_, x) = r
  x

def read_second(r: IdVec.IdVec<U32> & Bool) -> U32:
  (v, _) = r
  read_answer(IdVec.get(U32, v, 1, 0))

def second(xs: List<&2, U32>) -> U32:
  read_second(IdVec.from_list(U32, xs))
```

A native slice that imports changed passes needs `node scripts/native-bridge/build-native.mjs --set planar`.

---

## 10. LAWS.bend and PROOF.bend

- `LAWS.bend` states `law name: for +x: T ... {lhs == rhs : T}`. It, `laws.lock.json` and
  `kernel/laws/spec/**` belong to Marc. Agents write drafts in `kernel/laws/draft/` with a proof and at
  least one killed mutant (docs/laws.md:155-177).
- `PROOF.bend` imports `./LAWS.bend as Laws` and fills each law with `def Laws.name(x, y):` (bare
  names, no types, no `->`). Proof terms: `{==}` (by evaluation), `match` (cases), a recursive call
  (induction), `%e : P` (rewrite; `_` in `P` marks the right side of `e`, which is replaced by its
  left), `?name` (print the goal).
- A law and its proof in one file (the proof def has the law's name):

```bend
import Base

law not_not:
  for b: Bool
  {Bool.not(Bool.not(b)) == b : Bool}

def not_not(b):
  match b:
    case True{}:
      {==}
    case False{}:
      {==}
```

- **Only the exact last line `All terms check.` is green.** Bend exits 0 on `All terms check, but N defs
  rely on unsafe or foreign code:` and `scripts/check-bend.mjs` checks only the exit code, so an
  `@unsafe` def or a foreign import passes `npm test`. Read the output. No `@unsafe`, no `?` holes.
- **What the gate covers (verified for 2.0.25):** every def of every file imported (transitively) by
  `PROOF.bend`, whether reached or not (`delta/d01_reach.bend`, `d02_reach_none.bend`: an unused bad
  def in an imported module fails the check). A new module is gated once `PROOF.bend` imports it,
  directly or through another module. The `*_checked` "reachability" defs at the end of `PROOF.bend`
  are harmless but not needed for checking in 2.0.25; the comment above them predates this.
- F32 facts are unprovable. U32 is `Word(32n)` and provable by induction. Computed Nats of 2^15 or more
  inside a type overflow the checker stack (literals are fine). Evaluation proofs grow about cubically:
  keep instance laws small.
- Use a timeout on checker runs (a probe once hung for over 2 minutes).

---

## 11. Module structure

- Header: `import Base`, then relative imports with short aliases (`import ./real.bend as R`,
  `import ./precise.bend as G`). Imports only at the top.
- Inside a file: types first (leaves before the types that use them), then helpers, then callers.
  `tmp/r20/prism-boolean/reorder.mjs` topologically reorders the top-level blocks of a file.
- Prefix constructors with their type; keep them unique against Base (2.3).
- Errors are values: every helper has an explicit propagation arm; unsupported input returns a
  capability error, never a silent fallback (AGENTS.md).
- Records that cross native calls stay under 255 words; box or nest wide ones (5.1).
- Prototypes: `kernel/proto/<name>/main.bend` exports `run` (ideally `parse`/`solve`/`show`), copies
  `null/native.bend`, marks one device call with `# @bakeoff-device-call`, and answers
  `unresolved <reason>` when it refuses (docs/bakeoff.md:237-261).

---

## 12. Loader and cache

`src/bend-loader.mjs` compiles with the pinned compiler and caches JS in `.tools/bend-js-cache/`
(content-hashed over transitive local imports, compiler, lock and Node version; cold 4,088 ms to warm
333 ms for the bracket CLI). Options: `loadBend(url, { cache: false })`, `cacheDirectory`,
`compilerDirectory`, `lockFile`; `WONKY_BEND_CACHE=0` disables reads and writes globally. Only local
`import ./x.bend as X` lines are followed; import cycles are rejected. Editing a source during its
compile raises `BEND_SOURCES_CHANGED`.

A one-off JS reference run of a scratch file, without touching the cache (verified with
`tmp/bend-skill/snippets/skill/loader/probe.bend`, which prints `{"$":"Real","hi":5,"lo":0}`):

```sh
WONKY_BEND_CACHE=0 node --input-type=module -e "
import { loadBend } from './src/bend-loader.mjs';
const k = await loadBend('tmp/scratch/probe.bend', { cache: false });
console.log(JSON.stringify(k.hyp(3, 4)));"
```

Records come back as `{ $: 'Ctor', field: ... }`; F32 arguments are JS numbers.

---

## 13. Where 2.0.25 differs from the mega skill

The mega skill (`~/.claude/skills/bend2-mega-skill`) was measured on 2.0.13 and audited on 2.0.16.
These differences were checked against the pinned 2.0.25 (probe files `dNN` in the scratch directory
`tmp/bend-skill/snippets/skill/delta/`, output in `run-check.txt`; command
`BEND_NO_TELEMETRY=1 .tools/bend-2.0.25/bin/bend <f> --check-only`). Rows marked with a block below are
also re-checked by `check-snippets.mjs`.

| topic | mega skill says | 2.0.25 does | evidence |
|---|---|---|---|
| version | `bend --version` | `unknown option --version`; use `bend version` | CLI |
| fast check | `scripts/bend-check.sh` (checks through C emission) | `bend f.bend --check-only` checks the file and its imports and runs nothing; cannot be combined with other options | `bend --help` |
| bare operators | a chain without `: T` is `Nat`'s | error `a type for this operator (write (a + b : Nat))`; the compiler notes it changed after 2.0.16 | d08, d09 |
| typed let | `x : T = v` only inside `do` | also works in a def body: `n : U32 = 2`, `g : U32 -> U32 = y => ...` | d07 |
| unsafe verdict | `All terms check, with N unsafe annotation(s)` | `All terms check, but N defs rely on unsafe or foreign code:` plus the list, which includes transitive callers such as `main` | d03, mega `tcp_server` skeleton |
| template instances | counted as unsafe in 2.0.16 | not counted: `List.map` instances and the mega `cli_tool`/`app_headless` skeletons check clean | d04 |
| unused template bodies | typechecked only per instance | type and affinity errors in an unused template body are reported | d13, d15 |
| what a check covers | (PROOF.bend comment in wonky: only reachable defs) | every def of every imported file | d01, d02 |
| constructor namespaces | imported modules may redeclare Base names | true, and it is a trap: the same module fails when checked or loaded as the entry | d18, mods/done.bend |

The three verdict-related rows, as checked files:

```bend
# expect: unsafe - spin
import Base

@unsafe def spin(+x: U32) -> U32:
  spin(x)
```

```bend
import Base

def inc(x: U32) -> U32:
  (x + 1 : U32)

def incs(xs: List<U32>) -> List<U32>:
  List.map(~U32, ~U32, ~inc, xs)
```

```bend
# expect: error expected : U32
import Base

def never_used(~f: U32 -> U32, x: U32) -> U32:
  1.5

def g(y: U32) -> U32:
  y
```

Confirmed unchanged: `1n++p` and `1n+ +p` both bind the predecessor reusable (d05, d06); `F32.show`
still differs between C and JS (d20); `U32` literal patterns work (d12); `--checkup` still exists;
`bend guide shaders` and `bend guide effects` exist.

---

## 14. Unverified claims

Taken from repo docs or transcripts, not reproduced for this guide:

- Metal memory faults and out-of-memory cases (4.4) and all Metal and fork-join timings: repo
  measurements on the shared machine, cited by file.
- Why `a filled definition` was once reported for an ordinary loop helper (transcripts only).
- The native-bridge facts in 5.2 (fail-stop handling, relink costs) come from docs/native-bridge/*.md.
- "Local names may not shadow defs" (development evidence kept locally) did **not** reproduce:
  a parameter and a let with a def's name both check.

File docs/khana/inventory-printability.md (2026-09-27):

# cad_khana printability: complete inventory

Workflow `khana-design`, task `inv-printability` (2026-09-24). Research only: nothing in
wonky changes. This page accounts for every public name of cad_khana's printability side,
states each algorithm with its thresholds, the JSON it writes, how each number depends on
tessellation, what goes wrong (measured and read from code), and what an exact analytic
version on wonky's B-rep (plane, cylinder, cone, sphere, torus faces) would compute
instead.

Evidence labels used throughout:

- **[C]** read from code at the cited `file:line`;
- **[M]** measured by a command recorded in section 7 (oracle runs on copies in
  `tmp/khana/oracle/printability/`, or read-only surveys of `~/Workspace/cad`);
- **[I]** inference (reasoned from code or numbers, not separately tested).

Path prefixes: `U/` = `~/Workspace/cad/cad-khana/src/cad_khana/` (upstream worktree),
`UT/` = `~/Workspace/cad/cad-khana/tests/printability/`, `SK/` =
`~/.claude/skills/cad-khana/`, `B/` = build123d 0.10.0 in the khana tool venv
(`~/.local/share/uv/tools/cad-khana/lib/python3.13/site-packages/build123d/`), `W/` =
this repository. Oracle outputs: `O/` = `W/tmp/khana/oracle/printability/`.

## 0. Provenance: three generations of the code

| gen | what | printability modules | where it runs |
| --- | --- | --- | --- |
| **G0** | installed `khana` 0.0.2 (uv tool) = upstream commit `eee0567` (cyberchitta / restlessronin, 2026-05-25), byte-identical [M] | `inspect`, `methods`, `overhangs`, `wall`, `core/tessellation` only | `~/.local/share/uv/tools/cad-khana` |
| **G1** | `22f0ad0` = G0 + 5 commits by Marc (2026-06-11: `2ac9df9` orientation/bores/min-wall location/epsilons, `f37fd6d` bridges/cantilever/pins/bore notes, `d28c493` skill, `caa01b2` voids/sharp edges/contact ratio, `22f0ad0` skill) [M: `git log`] | + `holes`, `pins`, `structure`, `orientation` | copy `O/src_g1/` |
| **G2** | G1 + uncommitted worktree changes: `floating_solids`, `sharp_rim_edges`, diagonal convexity probe (`U/printability/inspect.py`, `U/printability/structure.py`, `UT/test_structure.py` modified) [M: `git status`, `git diff`] | same modules, more warnings | copy `O/src_g2/` (identical to the worktree, `diff -r` clean [M]) |

All 175 `*-printability.json` files in Marc's projects have the 17-key G2 schema [M,
section 8], so **G2 is what Marc actually runs** (the installed G0 CLI is not his daily
loop). This inventory describes G2 and marks G0/G1 differences. Line numbers are G2
worktree lines unless marked.

G0 → G1 changed behaviour, not only added modules [C: `git diff eee0567 22f0ad0`]:
assertions got the `EPS` (G0 compared `wall >= wall_min` and `angle <= max` exactly);
`detect_overhang` switched from whole-part `_tessellate` to per-face `tessellate_tagged`
plus the bore/bridge exemption and the `+1e-6` threshold; `min_wall` (with location) was
added and `min_wall_mm` became a wrapper.

## 1. Public surface and wonky's current status

Every top-level name of every upstream printability module (AST scan
`O/names.py`, output `O/names.out` [M]). "wonky" = `W/python/cad_khana/...`.

| upstream name | kind | upstream `file:line` | semantics (one line) | wonky today |
| --- | --- | --- | --- | --- |
| `methods.FDM` | frozen dataclass | `U/printability/methods.py:6-10` | print settings `up_axis=(0,0,1)`, `wall_min_mm=1.5`, `overhang_max_deg=45.0` | **provided**, identical fields (`printability/methods.py:10-14`) |
| `inspect.inspect(part, *, method, out="outputs", name="part")` | function | `U/printability/inspect.py:84-156` | run all checks, write `<name>-printability.json`, `SystemExit(1)` if an assertion failed | `checked_call` (`printability/inspect.py:12`): refused, or recorded not-run with `--khana-checks=skip` |
| `inspect.PrintabilityDiagnostics` | frozen dataclass | `inspect.py:32-50` | the JSON record (17 fields) | `refused_type` (`inspect.py:11`) |
| `inspect.EPS` | const `1e-6` | `inspect.py:28` | tolerance of both assertions | provided (`inspect.py:5`) |
| `inspect._wall_assertion`, `_overhang_assertion` | private fn | `inspect.py:53-63`, `:66-81` | build `AssertionResult`s | absent → `AttributeError` (`_wonky.py:148-149`) |
| `wall.min_wall(part)` | function | `U/printability/wall.py:28-36` | `(thickness, triangle-centroid)` of the worst inward ray, or `None` | `refused_call` (`wall.py:11`) |
| `wall.min_wall_mm(part)` | function | `wall.py:39-41` | the thickness only | `refused_call` (`wall.py:12`) |
| `wall.RAY_OFFSET_MM` | const `1e-4` | `wall.py:7` | ray start inside the surface | provided (`wall.py:5`) |
| `wall.SLIVER_HIT_DISTANCE_MM` | const `0.05` | `wall.py:8` | hits closer than this are ignored | provided (`wall.py:6`) |
| `wall._wall_thickness_at` | private fn | `wall.py:11-25` | one ray | absent |
| `overhangs.detect_overhang(part, *, up_axis=(0,0,1), angle_threshold_deg=45.0)` | function | `U/printability/overhangs.py:46-69` | `Overhang(area, max angle)` of flagged triangles, or `None` | `refused_call` (`overhangs.py:11`) |
| `overhangs.Overhang` | frozen dataclass | `overhangs.py:14-17` | `area_mm2`, `max_angle_deg` | `refused_type` (`overhangs.py:10`) |
| `overhangs.BUILD_PLATE_EPSILON_MM` | const `1e-3` | `overhangs.py:11` | plate-face centroid tolerance | provided (`overhangs.py:5`) |
| `overhangs._overhang_angle_deg`, `_build_plate_level`, `_on_build_plate` | private fn | `overhangs.py:20-22`, `:25-37`, `:40-43` | angle, plate height, plate-face test | absent |
| `holes.detect_bores(part, up_axis=(0,0,1))` | function | `U/printability/holes.py:164-236` | concave cylinders, deduped, classified vertical/horizontal/slanted with notes | `refused_call` (`holes.py:20`) |
| `holes.Bore` | frozen dataclass | `holes.py:46-51` | `diameter_mm`, `at`, `axis`, `note` | `refused_type` (`holes.py:15`) |
| `holes.FaceTag` | frozen dataclass | `holes.py:54-61` | per-face tag: bore diameter, planar normal, face bbox | `refused_type` (`holes.py:16`) |
| `holes.bore_face_radius(face)` | function | `holes.py:64-76` | radius if the cylinder face is concave, else `None` | `refused_call` (`holes.py:17`) |
| `holes.tessellate_tagged(part)` | function | `holes.py:79-105` | per-face tessellation with `FaceTag` | `refused_call` (`holes.py:18`) |
| `holes.self_supporting(tag, up, part)` | function | `holes.py:129-152` | `"bore"`, `"bridge"` or `None` | `refused_call` (`holes.py:19`) |
| `holes.VERTICAL_DOT` `0.99`, `HORIZONTAL_DOT` `0.1`, `SMALL_BORE_MM` `12.0`, `BRIDGE_MAX_MM` `10.0`, `CEILING_DOT` `0.985`, `PLATE_TOUCH_MM` `0.3` | consts | `holes.py:38-43` | see section 3 | provided (`holes.py:5-10`) |
| `holes._horizontal_span_dir`, `_axis_label` | private fn | `holes.py:108-126`, `:155-161` | bridge span, axis label | absent |
| `pins.detect_pins(part)` | function | `U/printability/pins.py:33-91` | convex full cylinders below Ø2 or L/D ≥ 8 | `refused_call` (`pins.py:13`) |
| `pins.Pin` | frozen dataclass | `pins.py:25-30` | `diameter_mm`, `length_mm`, `at`, `note` | `refused_type` (`pins.py:12`) |
| `pins.MIN_PIN_DIA_MM` `2.0`, `SLENDER_RATIO` `8.0`, `FULL_SWEEP_RAD` `5.2` | consts | `pins.py:20-22` | see section 3 | provided (`pins.py:5-7`) |
| `structure.enclosed_voids(part)` | function | `U/printability/structure.py:39-41` | number of inner shells | `refused_call` (`structure.py:13`) |
| `structure.floating_solids(part)` | function (G2 only) | `structure.py:44-48` | `(count, volume)` of solids beyond the largest | `refused_call` (`structure.py:14`) |
| `structure.sharp_vertical_edges(part, up_axis)` | function | `structure.py:84-97` | `(count, length)` of convex sharp vertical line edges | `refused_call` (`structure.py:15`) |
| `structure.sharp_rim_edges(part, up_axis)` | function (G2 only) | `structure.py:103-116` | `(count, length)` of convex sharp horizontal/vertical junctions | `refused_call` (`structure.py:16`) |
| `structure._convex_sharp_line_edges` | private generator (G2) | `structure.py:51-81` | shared edge filter | absent |
| `structure.VERTICAL_DOT` `0.99`, `SHARP_INTERIOR_DEG` `91.0`, `MIN_EDGE_LEN_MM` `2.0`, `HORIZONTAL_DOT` `0.95` | consts | `structure.py:34-36`, `:100` | see section 3 | provided (`structure.py:5-8`) |
| `orientation.suggest_orientation(part, *, name="part", out="outputs", overhang_max_deg=45.0)` | function | `U/printability/orientation.py:107-138` | rank six up axes, write `<name>-orientation.json`, return tuple | `refused_call` (`orientation.py:12`) |
| `orientation.score_orientation(part, up_axis, *, overhang_max_deg=45.0, triangles=None)` | function | `orientation.py:57-104` | one `OrientationScore` | `refused_call` (`orientation.py:11`) |
| `orientation.OrientationScore` | frozen dataclass | `orientation.py:43-54` | 8 fields (section 6.2) | `refused_type` (`orientation.py:10`) |
| `orientation.CANDIDATES` | const tuple (6 unit axes) | `orientation.py:32-39` | candidate up axes | **missing**: falls to `module_getattr` → capability error on access (`_wonky.py:153`) |
| `orientation.PLATE_TOL_MM` | const `1e-3` | `orientation.py:40` | plate-contact height tolerance | provided (`orientation.py:5`) |
| `core.tessellation._tessellate(part)` | private fn | `U/core/tessellation.py:28-32` | whole-part triangles | `refused_call` (`core/tessellation.py:13`) |
| `core.tessellation._triangle(a, b, c)` | private fn | `tessellation.py:18-25` | centroid, unit normal, area | `refused_call` (`core/tessellation.py:12`) |
| `core.tessellation.Triangle` | frozen dataclass | `tessellation.py:11-15` | `centroid`, `normal`, `area` | `refused_type` (`core/tessellation.py:11`) |
| `core.tessellation.TESSELLATION_TOLERANCE_MM` `0.1`, `TESSELLATION_ANGULAR_TOLERANCE` `0.3` | consts | `tessellation.py:7-8` | mesh settings (the first is **relative**, section 4) | provided (`core/tessellation.py:5-6`) |

Shared names the printability side uses (owned by other inventories, listed for
completeness): `mechanism.diagnostics.SCHEMA_VERSION = "0.2"` (`U/mechanism/diagnostics.py:12`),
`AssertionResult(name, passed, detail)` (`:43-46`), `BBox(min, max)` (`:17-19`), `_bbox`
(`:65-70`); `_paths.resolve_out` (`U/_paths.py:9-25`); `diff.diff` printability branch
(`U/diff.py:22-23`, `:191-246`).

"Import-through" names: upstream modules re-export what they import (for example
`from cad_khana.printability.inspect import FDM` works upstream because `inspect.py:17`
imports it; likewise `detect_bores`, `Overhang`, `min_wall`, `Triangle`, `Vector`, OCP
classes). In wonky such an access hits `module_getattr` and is a capability error
(`_wonky.py:139-155`), not the object [C]. No corpus file relies on this [I from the
census in `W/docs/python-khana.md:241-246`, which lists only direct names].

Which names real code uses [M: grep over `~/Workspace/cad`, excluding the cad-khana repo]:
only `inspect` and `FDM`, plus `suggest_orientation` in `cad-project-026/assembly.py:21,79`.
The other refused names (`detect_overhang`, `detect_bores`, `detect_pins`,
`enclosed_voids`, `sharp_vertical_edges`) appear only in cad-khana's own tests
(`W/docs/python-khana.md:241-246`).

## 2. `inspect()` step by step

`U/printability/inspect.py:84-156` [C]:

1. `out_path = resolve_out(out)`; `mkdir(parents=True, exist_ok=True)` (`:91-92`).
   Relative `out` is anchored at `sys.modules["__main__"].__file__`'s directory
   (`U/_paths.py:19-25`).
2. `min_wall(part)` → `(wall, wall_at)` or `(None, None)` (`:93-94`).
3. `detect_overhang(part, up_axis=method.up_axis, angle_threshold_deg=method.overhang_max_deg)` (`:95-99`).
4. Two assertions, always both, in this order (`:100-103`):
   - `wall_min:<wall_min_mm>` passes iff `wall >= wall_min_mm - EPS`; `wall is None` fails
     with detail `"min wall could not be computed"` (`:53-63`).
   - `overhang_max:<overhang_max_deg>` passes iff `overhang is None` or
     `max_angle_deg <= overhang_max_deg + EPS` (`:66-81`). Because `detect_overhang` only
     returns triangles above `threshold + 1e-6`, with the same threshold a non-`None`
     overhang always fails; the `EPS` only matters if the thresholds differed [I].
   - The assertion names embed Python's float `repr` (`wall_min:1.5`, `overhang_max:91`
     when an int was passed, `wall_min:0.27999999999999997` [M, section 8]).
5. Warnings, advisory, in this order (`:104-131`): floating solids (G2), enclosed voids,
   sharp vertical edges, undeburred rim edges (G2). Each is a formatted English string.
6. `failed = any(not passed)`; `com = part.center()` (build123d `CenterOf.MASS` for
   solids/compounds, `B/topology/three_d.py:178`, `B/topology/composite.py:563`).
7. Build `PrintabilityDiagnostics` (`:134-150`); **`detect_bores(part, method.up_axis)` and
   `detect_pins(part)` run here**, after the assertions, and never influence `status`.
   `method` is recorded as `type(method).__name__` (duck typing: any object with the three
   attributes works) [C].
8. Write `json.dumps(asdict(diagnostics), indent=2) + "\n"` to `<out>/<name>-printability.json` (`:151-153`).
9. If failed: `raise SystemExit(1)` **after** writing (`:154-155`); else return the dataclass.

Consequences [C/I]: every call fully recomputes (no caching besides OCCT's triangulation
cache on the shape); the JSON is written even on failure; `SystemExit` escapes
`except Exception`, which is why Marc's scripts catch it explicitly
(`cad-project-003/overnight-2026-09-05/family.py:340-343`, recorded in the worklog of this
task).

## 3. Every threshold and default

| constant | value | `file:line` | used by | meaning |
| --- | --- | --- | --- | --- |
| `FDM.up_axis` | `(0, 0, 1)` | `methods.py:8` | overhang, bores, sharp edges, rims | print "up" in part coordinates |
| `FDM.wall_min_mm` | `1.5` | `methods.py:9` | wall assertion | ≈ 3 perimeters at 0.4 mm nozzle (`SK/SKILL.md:567-572`) |
| `FDM.overhang_max_deg` | `45.0` | `methods.py:10` | overhang assertion and flagging | PLA rule of thumb (`SK/SKILL.md:573-578`) |
| `EPS` | `1e-6` | `inspect.py:28` | both assertions (`:57`, `:72`) | "design intent lands exactly on thresholds" |
| overhang flag epsilon | `+1e-6` (literal) | `overhangs.py:61`, `orientation.py:88` | triangle flagging | 45° planar chamfers must not flag |
| `TESSELLATION_TOLERANCE_MM` | `0.1` (**relative**, not mm) | `core/tessellation.py:7` | `_tessellate`, `tessellate_tagged` | `BRepMesh_IncrementalMesh(shape, 0.1, isRelative=True, 0.3, parallel=True)` (`B/topology/shape_core.py:1472-1475`) |
| `TESSELLATION_ANGULAR_TOLERANCE` | `0.3` rad | `core/tessellation.py:8` | same | max angle between adjacent facet normals |
| `RAY_OFFSET_MM` | `1e-4` | `wall.py:7` | wall ray start and result (`+1e-4`) | |
| `SLIVER_HIT_DISTANCE_MM` | `0.05` | `wall.py:8` | wall hit filter (`wall.py:23`) | ignore hits closer than 50 µm |
| ray intersection tolerance | `1e-6` | `B/geometry.py:89` (`TOLERANCE`), `B/topology/two_d.py:234-251` | wall | `BRepIntCurveSurface_Inter` on an **infinite** line (`gce_MakeLin`) |
| `BUILD_PLATE_EPSILON_MM` | `1e-3` | `overhangs.py:11` | `_on_build_plate` (`:41`) | centroid height tolerance |
| plate-face normal | `normal·up < -0.999` (≈ 2.56°) | `overhangs.py:42` | `_on_build_plate` | |
| `holes.VERTICAL_DOT` | `0.99` (≈ 8.1°) | `holes.py:38` | `_axis_label` (`:157`) | bore axis vertical |
| `holes.HORIZONTAL_DOT` | `0.1` (≈ 84.3° from up) | `holes.py:39` | `_axis_label` (`:159`) | bore axis horizontal |
| `SMALL_BORE_MM` | `12.0` (diameter, `<=`) | `holes.py:40` | exemption (`:136`), notes (`:204`, `:211`) | sag/undersize matters; ceilings self-bridge |
| `BRIDGE_MAX_MM` | `10.0` (span, `<=`) | `holes.py:41` | `self_supporting` (`:144`) | flat bridges print reliably |
| `CEILING_DOT` | `0.985` (≈ 9.9° from horizontal) | `holes.py:42` | `self_supporting` (`:141`) | face counts as a flat ceiling |
| anchor probe offsets | `0.5` mm below, `span/2 + 0.5` sideways | `holes.py:147`, `:149` | `self_supporting` | material test at both span ends |
| `PLATE_TOUCH_MM` | `0.3` | `holes.py:43` | elephant-foot note (`:223`) | bore starts on the plate |
| bore degeneracy | radial length `< 1e-9` | `holes.py:72` | `bore_face_radius` | |
| dedupe rounding | direction 3 decimals, axis foot 1 decimal (0.1 mm), radius 2 decimals | `holes.py:189-197`, `pins.py:48-56` | bores, pins | split faces of one cylinder counted once |
| `MIN_PIN_DIA_MM` | `2.0` (`<`) | `pins.py:20` | pin note (`:71`) | |
| `SLENDER_RATIO` | `8.0` (`L/D >=`) | `pins.py:21` | pin note (`:76`) | |
| `FULL_SWEEP_RAD` | `5.2` rad (≈ 298°) | `pins.py:22` | pin filter (`:40`) | fillet strips are partial sweeps |
| `structure.VERTICAL_DOT` | `0.99` | `structure.py:34` | `sharp_vertical_edges` (`:93`) | edge direction vs up |
| `SHARP_INTERIOR_DEG` | `91.0` | `structure.py:35` | `_convex_sharp_line_edges` (`:69`) | right angles and sharper |
| `MIN_EDGE_LEN_MM` | `2.0` | `structure.py:36` | same (`:60`) | ignore micro edges |
| convexity probe distance | `0.2` mm | `structure.py:75`, `:78` | same | bisector + diagonal probes (G2); G1 bisector only |
| `structure.HORIZONTAL_DOT` | `0.95` | `structure.py:100` | `sharp_rim_edges` (`:112`) | one face `|n·up| <= 0.05`, the other `>= 0.95` |
| `is_inside` tolerance | `1e-6`, **on-face counts as inside** | `B/topology/three_d.py:423-440` | bridge anchors, convexity probes | `BRepClass3d_SolidClassifier` |
| `CANDIDATES` | `±X, ±Y, ±Z` | `orientation.py:32-39` | `suggest_orientation` | |
| `PLATE_TOL_MM` | `1e-3` | `orientation.py:40` | plate contact (`:85`) | |
| plate-contact normal | `downward > 1 - 1e-9` | `orientation.py:85` | plate contact | |
| footprint floor | `1e-9` | `orientation.py:102` | `contact_vs_footprint` | |
| ranking key | `(round(support, 1), risky_bores, height)` | `orientation.py:122` | sort | ties keep `CANDIDATES` order (stable sort) |
| `SCHEMA_VERSION` | `"0.2"` | `U/mechanism/diagnostics.py:12` | printability JSON | orientation JSON has none |

## 4. Tessellation: the common approximation

`core/tessellation.py:28-32` [C]: `part.tessellate(0.1, 0.3)` → build123d
`Shape.tessellate` (`B/topology/shape_core.py:1899-1939`) calls `Shape.mesh`
(`:1459-1475`): `if not BRepTools.Triangulation_s(shape, 0.1): BRepMesh_IncrementalMesh(shape, 0.1, True, 0.3, True)`.

- The third argument `True` is `isRelative`: the linear deflection is 0.1 × the size of
  each edge/face, not 0.1 mm. The name `TESSELLATION_TOLERANCE_MM` is misleading [C].
  In practice the 0.3 rad angular limit decides curved faces [I, consistent with the
  measured triangle counts: 164 triangles for a Ø10 × 20 cylinder].
- The triangulation is cached on the `TopoDS_Shape` and reused if its deflection is
  ≤ the request [C: `BRepTools.Triangulation_s`]. A second call on the same object reuses
  it; the oracle builds fresh shapes for each setting for that reason (`O/oracle.py:95-96`).
- Triangle normal = normalized `(b-a) × (c-a)` with the OCCT winding flipped for
  `REVERSED` faces (`shape_core.py:1917-1939`), so it is outward; zero-area triangles keep
  a zero normal (`tessellation.py:19-24`).
- `min_wall` uses the whole-part triangles (`wall.py:32`); overhang and orientation use
  per-face `face.tessellate(...)` (`holes.py:99-101`), which reuses the same cached
  per-face triangulation [I].
- Every curved-face triangle lies inside the true surface by up to the chord sagitta
  (convex faces: inside the material; concave faces: inside the hole). Its normal is the
  chord-plane normal, tilted by up to about half the angular step (≤ 0.15 rad ≈ 8.6°)
  against the true surface normal at the centroid [I]. Both effects drive the false
  results in section 5.

Wonky already has what an exact replacement of this layer would build on, or a
certified approximate one: the certified print mesh `printMesh(kernel, body, deviationMm,
{ tags })` (`W/src/print-mesh.mjs:7-41`, `:183-200`) states the achieved deviation from
Bend (`W/kernel/tessellate.bend:5-29`, `sagitta` `:21`, `arc_sagitta` `:145`,
`grid_bound` `:163`) and can tag triangles with face ids. It covers planes, cylinders and
cones bounded by parallels/rulings, spheres and tori bounded by parallels and meridians,
and refuses ellipse/intersection-curve edges by name (`print-mesh.mjs:40-41`).

## 5. Checks: algorithm, exemptions, failure modes, exact version

### 5.1 Minimum wall (`wall.py`)

**Algorithm [C]** (`wall.py:11-36`): for every triangle of `_tessellate(part)` with
`area > 0`: `inward = -normal`; `origin = centroid + inward·1e-4`; intersect the
infinite line `Axis(origin, inward)` with the part (`find_intersection_points`,
`B/topology/two_d.py:234-275`: `BRepIntCurveSurface_Inter` against all trimmed faces,
tolerance 1e-6, hits sorted by signed distance); keep hits with
`(hit - origin)·inward > 0.05`; thickness = `min(kept) + 1e-4`. `min_wall` returns the
smallest thickness and that triangle's centroid (`min_wall_at`); `None` if no triangle
produced a hit. There is no location for the far hit and no face id.

**What it measures.** The "ray method" of wall thickness: distance from a boundary point
along the inward normal to the next boundary crossing, sampled at triangle centroids.

**Failure modes.**

| case | result | exact | label | cause |
| --- | --- | --- | --- | --- |
| Ø10 boss / cylinder (convex) | 9.984 | 10 | [M] `boss10`, `cyl_vertical_r5` | chord centroid is inside the material by the sagitta: convex curvature under-reads (safe side) |
| Ø1.5 pin at `wall_min_mm=1.5` | 1.4977 → **assertion fails** | 1.5 → passes with `EPS` | [M] `pin_thin_1p5` | same under-read; `EPS = 1e-6` protects planar design intent only |
| bore crown 0.5 mm below top | 0.5140 / 0.5016 / 0.5006 (3 mesh levels) | 0.5 | [M] `bore_near_top` | concave curvature **over-reads** (unsafe side) |
| 0.4 mm web between two Ø10 bores | 0.4277 / 0.4031 / 0.4008 | 0.4 | [M] `web_two_bores` | over-read, and the pinch is only hit if a centroid ray passes near it |
| Ø20 bore 2 mm from a face | 2.0429 / 2.0048 / 2.0012 | 2.0 | [M] `bores_v5_h5_h20` | over-read |
| 20 mm plate with Ø60 / Ø100 through bore | **0.0746 / 0.1243** | 20 | [M] `concave-self-hit.json` | self-hit: the centroid lies inside the hole by the sagitta (> 0.05 once the bore is large), the ray re-enters the bore's own surface |
| block with Ø20 / Ø60 spherical void | 0.0508 / 0.0523 | 20 | [M] same | concave self-hit, clipped just above the 0.05 floor |
| solid sphere Ø10 | **0.49** at the pole (`[-0.35, 0, 9.96]`); 0.16 and 3.91 at finer meshes | 10 | [M] `sphere_r5`, sensitivity | degenerate pole-fan triangles whose normals are far from radial: the inward ray is nearly tangent [I] |
| cone frustum with 45° knife edge at the top rim | 0.0596 at `[5.82, -5.40, 6.0]` (rim radius 7.94 of 8) | 0 (infimum) | [M] `cone_inv_45` | at an edge with interior dihedral angle < 90° the ray thickness → 0; the reported value is wherever the nearest centroid happens to be, clipped by the 0.05 floor |
| wall thinner than 0.05 mm | `None` → `"min wall could not be computed"` | the thickness | [C] `wall.py:23`, `SK/references/printability.md:32-41` | sliver filter |
| diagonal pinch not along any face normal | over-read | smaller | [C] `SK/references/printability.md:42-45` | ray method limitation |

**Real-world signature [M, section 8]:** 30 of 175 of Marc's outputs report
`min_wall_mm < 0.1`, almost all between 0.050 and 0.054 (for example
`cad-project-046/outputs/ball_socket-printability.json` 0.0501 at `wall_min:1.5`; spherical
sockets are concave spheres). This is the `SLIVER_HIT_DISTANCE_MM` floor produced by
self-hits and knife edges, not real walls [I, supported by the probes above]. Marc
answered by lowering `wall_min_mm` to 0.01–0.05 in 17 files, which switches the check off.

**Tessellation dependence.** Entirely: sample positions, the ray directions (facet
normals, not surface normals), the sagitta offset of the start point, and the self-hit
threshold all come from the mesh. Results are not monotone under refinement (sphere:
0.49 → 0.16 → 3.91 [M]).

**Exact analytic version.** On wonky's analytic faces (`W/kernel/analytic.bend:21-26`)
the ray-method quantity is `t(p) = first positive root of the line p - s·n(p) with the
trimmed boundary`, and its infimum over each face has closed-form or certified
candidates:

- Interior critical points are **double normals**: pairs `(p, q)` on faces A, B with
  `q - p` parallel to both normals, opposite orientation, open segment inside the solid.
  For the five surface types these are closed form: plane–plane (parallel, opposed):
  plane distance; plane–cylinder: axis-to-plane distance ∓ r (the bore crown: exactly
  0.5); cylinder–cylinder with parallel axes: axis distance ∓ r1 ∓ r2 (the web: exactly
  0.4); skew axes: common perpendicular; sphere–anything: distance from the centre ∓ ρ;
  cone: through the axis/apex (quadratic); torus: through the tube-centre circle
  (circle–plane and coaxial cases closed form, otherwise a quartic → certified root
  isolation or a capability error).
- Boundary critical points lie on edges/vertices of the trimmed faces (1-D minimization
  along lines, circles, ellipses; certified).
- Every witness must be inside its trimmed face (face membership) and the segment inside
  the solid (solid classification).
- Knife edges must be reported as what they are: an edge with interior dihedral angle
  < 90° has thickness infimum 0 by geometry. An exact tool reports "knife edge E, angle
  α, length L" separately and excludes an explicit neighbourhood from the wall minimum,
  instead of returning a mesh-dependent 0.05–0.06.
- Result: `min_wall_mm` exact (or with a stated certified bound), and `min_wall_at` as a
  witness pair `(p, q)` with face ids, which makes the location unambiguous. Self-hits
  and sagitta errors cannot occur.

Kernel status: line/plane, line/cylinder, line/cone roots exist (`W/kernel/ray.bend:174`,
`:292`, `:297-310`); line/sphere and line/torus return kind 4 "unresolved"
(`ray.bend:320-325`); `ray.bend` does no trims or forward selection (`ray.bend:7-10`).
Face membership exists for planes (`W/kernel/face-classification.bend:9-11`) and trimmed
cylinders (`W/kernel/cylinder-classification.bend:10-12`); solid classification accepts
only plane and cylinder faces (`W/kernel/solid-classification.bend:145-152`). No
double-normal or body-to-body distance primitive exists yet.

### 5.2 Overhang (`overhangs.py` + exemptions in `holes.py`)

**Algorithm [C]** (`overhangs.py:46-69`): `up = normalize(up_axis)`; plate level
`min_up` = min of `corner·up` over the 8 corners of the part's axis-aligned bounding box
(`:25-37`); for every `(triangle, tag)` of `tessellate_tagged(part)` flag it iff

1. `self_supporting(tag, up, part) is None` (not an exempt bore or bridge), and
2. `angle = degrees(asin(clamp(-normal·up, 0, 1))) > threshold + 1e-6` (`:20-22`, `:61`), and
3. not `_on_build_plate`: `|centroid·up - min_up| < 1e-3` and `normal·up < -0.999` (`:40-43`).

Returns `None` if nothing flagged, else `Overhang(sum of flagged triangle areas, max
flagged angle)`. The angle is 0° for a vertical wall and 90° for a downward ceiling.

**Exemption "bore" [C]** (`holes.py:136-137`): every triangle of a cylinder face that
`bore_face_radius` calls concave with diameter ≤ 12 mm is exempt, regardless of up axis.
`bore_face_radius` (`holes.py:64-76`) probes one point, `face.center()` (the uv midpoint
for non-planar faces, `B/topology/two_d.py:1450-1480`): convex if the outward normal
there points away from the axis. Concave partial cylinders (inner fillets) are therefore
"bores" too.

**Exemption "bridge" [C]** (`holes.py:138-152`): planar faces with `-n·up >= 0.985`;
span = the smaller of the face bbox extents along two in-plane directions `u1`, `u2`
derived from a fixed seed (`(1,0,0)` unless up is nearly X, `holes.py:108-126`); if
`span <= 10`, probe two points `bbox_mid - 0.5·up ± (span/2 + 0.5)·u`; both must be
`is_inside` (on-face counts); else it is a cantilever and flags. `self_supporting` runs
per triangle, so these two probes repeat for every triangle of the face [C].

**Measured behaviour [M]** (G2, default mesh unless noted; exact values computed in
`O/oracle.py:97-105`, corrected where noted):

| part | reported area / max angle | exact (same rules) | verdict |
| --- | --- | --- | --- |
| `cube10`, `plate_1mm`, `chamfer45_bottom` (planar 45° chamfer) | none | none | correct; the `+1e-6` keeps the 45° chamfer out |
| `ell_ledge` (10×20 ledge underside) | 200 / 90 | 200 / 90 | correct |
| `slot6_bridge` / `slot20_bridge` | none / 800 / 90 | bridge exempt / 800 | correct by the rules |
| `cantilever6` (6 mm shelf, one side anchored) | 120 / 90 | 120 / 90 | correct: probe finds air |
| `cyl_horizontal_r5` (Ø10×20 lying) | 164.4 → 154.6 → 152.1; max 90 → 90 → 89.29 | band 157.08 / 90 | ±5 %, non-monotone; at fine meshes bottom triangles fall under the plate exemption |
| `sphere_r5` | 51.06 → 44.10 → 45.97; max 83.97 → 88.0 → 89.0 | cap 46.01 / 90 | −14 %..+11 % |
| `torus_R10_r3` flat | 308.9 → 281.9 → 282.0; max 90 → 87.1 → 87.9 | band 296.09 / 90 | converges to the wrong value: the plate test removes a strip along the contact circle |
| `cone_inv_45` (side exactly 45°) | **54.0 → 31.2 → 21.8; max 45.94 → 45.25 → 45.10 → fails** | nothing flagged, 45 passes | **false positive** at every mesh level: facet normals are steeper than the cone |
| countersink from below, cone exactly 45° | **28.1 / 46.1 → fails** | 45 passes | same false positive |
| `cone_inv_46` / `cone_inv_50` | 276.2 → 277.1 / 325.9 → 327.0; max 46.93 / 50.88 at default | 277.11 / 46; 326.97 / 50 | area fine, angle over-read by ~0.9° |
| `bores_v5_h5_h20` | 493.2 → 463.7; max 90 | D20 top band flagged, D5 exempt | Ø20 > 12 so its ceiling flags (by design) |
| 6 mm slot rotated 45° in plan | **491 / 90 → fails** | exempt like the axis-aligned slot | **false positive**: bbox span of a diagonal slot ≫ 6 |
| 6 mm bridge between 0.4 mm walls | **120 / 90 → fails** | a 6 mm bridge | **false positive**: the anchor probe lands 0.1 mm outside the thin wall |
| same with 2 mm walls | none | none | correct |
| ledge with r2 inner fillet at the underside | 160 (was 200) | 200 minus the fillet's non-steep part | fillet treated as a Ø4 "bore": its steep part is exempt (false negative, small) |

Real use confirms the cone/countersink problem: Marc raised the threshold to 66° and 48°
with the comments "countersink-mouth tessellation in the first 0.2 mm above the plate"
and "the 0.42 end-face deburr chamfer wraps the spine fillet arcs at up to 47 deg — <1
mm2 in the first 0.4 mm above the plate" (`~/Workspace/cad/cad-project-026/assembly.py:80-84`).
52 of 175 outputs use `overhang_max_deg` 90/91, i.e. the check disabled [M].

**Further failure modes read from code [C/I]:**

- Plate level from the axis-aligned bbox corners (`overhangs.py:25-37`; same in
  `holes.py:168-174`, `orientation.py:67-73`): for an `up_axis` that is not a coordinate
  axis the minimum over bbox corners can lie below the real part (any part whose bbox
  corner is not a point of the part, for example a cylinder), so the true bottom is not
  "on the plate" and flags [I].
- The plate exemption requires a centroid within 1 µm of the plate and a normal within
  2.56° of straight down: curved bottoms (cylinders, spheres, tori lying on the plate)
  flag almost entirely, except for whatever triangles happen to satisfy both
  (`SK/references/printability.md:92-95` states the first half).
- No support-from-below test: a downward face with material right below it still flags
  (`SK/references/printability.md:88-91`).
- The bore exemption ignores orientation and applies to any concave cylinder ≤ Ø12,
  including a large horizontal *slot* of radius ≤ 6 and inner fillets [C].
- The bridge span uses only two fixed in-plane directions and the face **bbox**: diagonal
  or L-shaped ceilings get spans larger than their real width [C, M].
- The anchor probe samples one point per side at the bbox mid-line: walls thinner than
  0.5 mm, chamfered or filleted wall tops, and ceilings whose bbox centre is not above
  the gap misclassify [C, M].
- The result is one aggregate per part: no location, no face ids
  (`SK/references/printability.md:99-101`).

**Exact analytic version.** With up `u`, outward normal `n(p)` (face `same_sense`
applied) and `c = sin θmax`, the flagged set of a face is `{p : -n(p)·u > c}` (for
`θmax >= 90` it is empty):

- **Plane:** `n` constant, so all or nothing; area = exact trimmed-face area (Green's
  theorem over line, circle and ellipse edges, closed form); max angle `asin(-n·u)`.
- **Cylinder** (axis `a`, radius `r`, `σ = +1` boss / `-1` bore): with
  `u⊥ = u - (u·a)a`, `s = |u⊥|`, `n(φ) = σ e(φ)`, the downward component is
  `-σ s cos(φ - φu)`. Flagged: one angular band of half-width `arccos(c/s)` (empty if
  `s <= c`, so vertical cylinders never flag), centred at the bottom (boss) or the top
  (bore ceiling). Area = `r ∫band (z_hi(φ) - z_lo(φ)) dφ`; with ruling, parallel and
  plane-section (ellipse) trims `z` is `α + β cos φ + γ sin φ`, so it is closed form.
  Horizontal Ø10×20: exactly `5·20·π/2 = 157.08`.
- **Cone** (half-angle `α`): downward component `A cos(φ - φu) + B` with
  `A = -σ s cos α`, `B = σ sin α (u·a)` (sign by opening direction): an exact angular
  sub-band `|φ - φc| < arccos((c - B)/|A|)`; for an axis parallel to up it is constant,
  so a 45° countersink or conical chamfer lands exactly on 45° and passes like a planar
  chamfer.
- **Sphere:** flagged set = a spherical cap of angular radius `90° - θmax` around the
  lowest (convex) or highest (concave) point; `face ∩ cap` is bounded by circles, so its
  area is closed form (Gauss–Bonnet with constant geodesic curvature of small circles).
- **Torus** (`R`, `r`): for `u` parallel to the axis the band depends only on the tube
  angle `v` and the area is closed form (`2π r (R·π/2)` = 296.09 for the oracle torus);
  for a tilted `u` the region in `(φ, v)` is a level set of a trigonometric polynomial →
  certified quadrature with a stated bound (as `W/kernel/volume.bend:5-30` does for
  sphere/torus boundary integrals) or a capability error.
- **Max angle:** exact supremum of `asin(-n·u)` over the face (interior extremum if the
  extreme generator lies inside the trim, else on the boundary).
- **Plate:** exact plate level `h0 = min_p p·u` from the analytic support function (not
  a bbox); "supported by the plate" as an explicit band `p·u - h0 <= first_layer_mm`
  cut by a plane section (`W/kernel/section.bend`), which is what Marc's waiver comments
  describe.
- **Bore exemption:** concavity from `same_sense` (no probe); full circle vs partial
  (fillet) from the summed angular extent and G1 tangency of the trims.
- **Bridge exemption:** exact minimal width of the planar ceiling region (rotating
  calipers over the convex hull of its line and arc edges), and anchoring from topology:
  the faces across the ceiling's boundary edges on both sides of the span go down into
  material. No probes, so thin walls and rotated slots work.
- Output per flagged region: face id, area, angle range, height range, reason
  (`flagged` / `bore` / `bridge` / `plate`), which enables local waivers.

### 5.3 Bores (`holes.py:detect_bores`)

**Algorithm [C]** (`holes.py:164-236`): plate level from bbox corners (`:168-174`); for
each `GeomType.CYLINDER` face: skip if `bore_face_radius(face) is None` (convex or
degenerate, `:182-183`); dedupe by `(sign-folded axis direction rounded to 3 decimals,
axis foot point of the origin rounded to 0.1 mm, radius rounded to 0.01 mm)`
(`:185-200`); classify `|axis·up| >= 0.99` vertical, `<= 0.1` horizontal, else slanted
(`:155-161`); notes:

- horizontal and Ø ≤ 12: `"ceiling sag on horizontal bore — teardrop the top or oversize by 0.1-0.2 mm if a pin/axle must fit"` (`:204-208`);
- slanted (any Ø): `"slanted bore prints elliptical/stepped"` (`:209-210`);
- vertical and Ø ≤ 12: `"vertical bores print 0.1-0.3 mm undersize (nozzle squish) — oversize or ream if a pin/axle must fit"`; plus, if the face's bbox low corner is within 0.3 mm of the plate, `"bore starts on the build plate: elephant foot pinches the first layers — chamfer the hole's bottom edge"` (`:211-227`);
- otherwise `note: null`. Notes are joined with `"; "`.

`at` = `face.center()` = the uv midpoint **on the cylinder wall**, not on the axis
(`:184`, `:231`; [M] `bores_v5_h5_h20`: `at [-2.5, 0, 15]` for a bore whose axis is
`x = 0`).

**Failure modes:** inner fillets are listed as bores [M: r2 fillet → `Ø4 horizontal`
with a sag note]; coaxial equal bores in separate walls (for example both clevis arms)
merge into one entry, and the elephant-foot note looks only at the first face kept [C:
dedupe `:198-200`, note `:216-227`]; only cylinders count (countersink cones, hexagonal
nut traps, teardrops are not bores) [C: `:177`]; `detect_bores` never fails an inspection
(`holes.py:15`). Real outputs list up to 200 bores per part, 1980 in total (vertical 1441,
horizontal 535, slanted 4) [M].

**Tessellation dependence:** none (B-rep face types and OCCT surface data) [C].

**Exact version:** the same classification is already exact on analytic data if
concavity comes from face orientation and grouping from exact coaxiality (with a stated
tolerance, or construction identity of the hole feature); report the axis segment, depth,
through/blind, all faces, and the elephant-foot test from the exact lowest point of the
bore's circle edges (`center·u - r·|u⊥|`).

### 5.4 Pins (`pins.py`)

**Algorithm [C]** (`pins.py:33-91`): for each cylinder face that is **not** a bore
(`:37-38`) and whose OCCT u-range is ≥ 5.2 rad (`:39-41`), dedupe like bores
(`:46-59`); `length` = extent of that face's bbox corners along the axis (`:61-69`);
note if Ø < 2 (`"pin below FDM minimum diameter 2.0 mm — thicken or replace with an insert"`)
and/or L/D ≥ 8 (`"slender pin (L/D x.x) wobbles while printing and snaps in use — fillet the base or shorten"`);
only pins with a note are reported, `at` = `face.center()` on the surface.

**Failure modes [M/C]:** a pin built from two half-cylinder faces is missed (each u-range
π < 5.2) [M]; a stand-alone rod Ø3×30 and the same rod lying horizontally are both flagged
slender — `detect_pins` has no up axis and does not know that the whole part is the rod
[M]; a pin split into several faces reports only the first face's length [C]; the bbox
projection over-reads the length of tilted pins [I]; real outputs contain **zero** pins
over 175 files [M].

**Tessellation dependence:** none.

**Exact version:** convex cylinders grouped by exact axis and radius, sweep summed over
all faces of the group, length from the exact axial extent of the group's edges, free
end detected topologically (a cap face whose normal is the axis), orientation-aware
notes (vertical slender pins wobble; horizontal pins print as ovals).

### 5.5 Structure advisories (`structure.py`)

| check | algorithm [C] | measured [M] | failure modes | exact version |
| --- | --- | --- | --- | --- |
| `enclosed_voids` | `sum(max(0, len(solid.shells()) - 1))` (`:39-41`) | `hollow_cube`: 1 | none known; pure topology | shell count from face connectivity; which shell is outer from the signed volume (`W/kernel/volume.bend`) |
| `floating_solids` (G2) | solids sorted by OCCT volume, count and volume of all but the largest (`:44-48`) | `two_solids`: `1 floating solid(s), 64.0 mm3` | two solids touching at a face may be one or two OCCT solids depending on the Boolean [I] | lump count (connected components) and exact volumes |
| `sharp_vertical_edges` | `_convex_sharp_line_edges` (`:51-81`): LINE edges ≥ 2 mm between exactly two PLANE faces; interior angle `180 - acos(n1·n2) <= 91`; convex iff both 0.2 mm probes `mid + 0.2·norm(n1+n2)` and (G2) `mid + 0.2·norm(n1-n2)` are outside; then `|dir·up| >= 0.99` (`:84-97`) | cube: 4 edges 40 mm; plate with five 0.8×2 mm slide ribs: 24 edges; Ø20 cylinder: 0 | noisy on intentional micro features (`SK/SKILL.md:38-41`); the probe pair is a heuristic (G1 counted the four concave cavity edges of `hollow_cube` as convex: 8 edges vs 4 in G2 [M]); micro edges < 2 mm ignored | dihedral angle and convexity from the two exact normals and the coedge orientation (`sign((n1 × n2)·t)`), no probes; extend to circle and ellipse edges |
| `sharp_rim_edges` (G2) | same generator; one face with `|n·up| <= 0.05` and the other `>= 0.95` (`:103-116`) | cube: 8 edges 80 mm; slide-rib plate: 18 edges 620 mm | cylinder rims (circle edges) never counted [M: Ø20 cylinder 0], although they are the same house-rule case | same exact predicate on line and circle edges; report per edge with location |

Warnings in real outputs [M]: "sharp vertical" in 118 of 175 files, "undeburred rim" in
149 of 175, no void or floating warnings. Warnings are free text (`inspect.py:107-131`);
`diff.py` ignores them (`U/diff.py:214-244`).

**Tessellation dependence:** none, but convexity depends on `is_inside` probes at a
fixed 0.2 mm, which fail on features smaller than that [I].

### 5.6 Orientation (`orientation.py`)

**Algorithm [C]** (`orientation.py:57-138`): `tessellate_tagged` once; for each of the
six `CANDIDATES`: plate = min bbox corner·up; footprint = product of bbox extents along
the two in-plane directions; for each triangle, `height = centroid·up - plate`,
`downward = clamp(-n·up)`:

- `downward > 1 - 1e-9` and `height <= 1e-3` → `plate_contact_mm2 += area`;
- else if `asin(downward) > overhang_max_deg + 1e-6`: exempt (`self_supporting`) →
  `self_bridging_mm2 += area`, otherwise `overhang_area_mm2 += area` and
  `support_demand_mm3 += area·height`;
- `risky_bores` = bores (`detect_bores(part, up)`) not labelled vertical;
- `contact_vs_footprint = contact / max(footprint, 1e-9)`; `height_mm` from the bbox.

Sort by `(round(support, 1), risky_bores, height)` (`:122`), write
`<name>-orientation.json` (no `schema_version`), return the tuple. Geometry is not
rotated; the user copies `best_up_axis` into `FDM(up_axis=...)` (`:14-17`).

**Measured [M]:** a sphere's six scores differ only by tessellation (support 35.2, 35.2,
35.2, 36.8, 42.7, 42.7 mm³), so the "best" axis `(1,0,0)` is mesh noise; a lying
cylinder's end-face contact is 78.247 mm² (inscribed polygon) instead of 78.54; real
winners carry support "dust" such as 0.2 mm³ (`cad-project-026` carriage) and 0.4 mm³
(`cad-project-020/.../pulley_bracket`) that the `round(…, 1)` key still ranks.
9 real orientation files exist, all with six entries of eight fields.

**Tessellation dependence:** every number except `risky_bores` and `height_mm`.

**Exact version:** `support_demand = ∫flagged (p·u - h0) dA` is a first moment of area:
closed form on planes (area × centroid height via Green's theorem), cylinder and cone
bands, sphere caps, and flat tori; `plate_contact` = exact areas of planar faces with
`n = -u` at `h0` (plus the first-layer band if adopted); exact bbox/footprint from the
support function. Exact values make symmetric orientations tie exactly, so ties can be
reported instead of broken by candidate order. Candidates can include "lay flat on
planar face F" (`u = -n_F`) and cylinder axes, not only the six world axes.

### 5.7 Mass properties and validity fields

`bbox` (optimal OCCT box, `B/topology/shape_core.py:1006-1020`), `volume_mm3`
(`part.volume`), `surface_area_mm2` (`BRepGProp.SurfaceProperties_s`,
`shape_core.py:313-319`), `center_of_mass_mm` (`CenterOf.MASS`), `is_valid`
(`BRepCheck_Analyzer`, `shape_core.py:446-452`) [C]. Exact counterparts: volume with a
stated bound exists (`W/kernel/volume.bend:5-30`, host `W/src/volume.mjs:104`
`integrateVolume`); surface area, centre of mass (first moments, same divergence-theorem
machinery) and an analytic bbox do not exist as kernel queries yet [C: grep].

## 6. JSON schemas

### 6.1 `<name>-printability.json`

Written by `json.dumps(asdict(PrintabilityDiagnostics), indent=2) + "\n"`
(`inspect.py:151-153`); key order is the dataclass order (`inspect.py:33-50`); tuples
become arrays; floats use Python `repr`.

| key | type | G0 | G1 | G2 | source |
| --- | --- | --- | --- | --- | --- |
| `schema_version` | string `"0.2"` | ✓ | ✓ | ✓ | `diagnostics.py:12` |
| `kind` | `"printability"` | ✓ | ✓ | ✓ | `diff.py:22-23` detects the kind by this key |
| `status` | `"ok"` \| `"assertion_failed"` | ✓ | ✓ | ✓ | `inspect.py:149` |
| `name` | string | ✓ | ✓ | ✓ | `name=` argument |
| `method` | string (class name, `"FDM"`) | ✓ | ✓ | ✓ | `inspect.py:136` |
| `bbox` | `{min: [x,y,z], max: [x,y,z]}` | ✓ | ✓ | ✓ | `diagnostics.py:65-70` |
| `volume_mm3` | number | ✓ | ✓ | ✓ | OCCT |
| `surface_area_mm2` | number | ✓ | ✓ | ✓ | OCCT |
| `center_of_mass_mm` | `[x,y,z]` | ✓ | ✓ | ✓ | OCCT |
| `is_valid` | bool | ✓ | ✓ | ✓ | OCCT |
| `min_wall_mm` | number \| null | ✓ | ✓ | ✓ | 5.1 |
| `min_wall_at` | `[x,y,z]` \| null (triangle centroid) | – | ✓ | ✓ | 5.1 |
| `overhang` | `{area_mm2, max_angle_deg}` \| null | ✓ | ✓ | ✓ | 5.2 |
| `bores` | `[{diameter_mm, at: [x,y,z], axis: "vertical"\|"horizontal"\|"slanted", note: string\|null}]` | – | ✓ | ✓ | 5.3 |
| `pins` | `[{diameter_mm, length_mm, at, note}]` (only flagged pins) | – | ✓ | ✓ | 5.4 |
| `warnings` | `[string]` | – | ✓ (voids, sharp vertical) | ✓ (+ floating, rim) | 5.5 |
| `assertions` | `[{name: "wall_min:<v>", passed, detail}, {name: "overhang_max:<v>", passed, detail}]` | ✓ | ✓ | ✓ | `inspect.py:53-81` |

Detail strings: `"min wall 0.4928mm below min 1.5mm"`, `"min wall could not be computed"`,
`"overhang 83.9672° exceeds max 45.0°"` [M].

Real G2 example (`O/out_g2/cube10-printability.json`, [M]):

```json
{"schema_version":"0.2","kind":"printability","status":"ok","name":"cube10","method":"FDM",
 "bbox":{"min":[-5.0,-5.0,0.0],"max":[5.0,5.0,10.0]},"volume_mm3":999.9999999999998,
 "surface_area_mm2":599.9999999999999,"center_of_mass_mm":[-3.5e-17,-1.2e-16,5.0],"is_valid":true,
 "min_wall_mm":10.0,"min_wall_at":[-5.0,-1.6666666666666665,3.333333333333333],"overhang":null,
 "bores":[],"pins":[],
 "warnings":["4 sharp vertical edge(s), 40 mm total: the nozzle decelerates at these corners every layer — fillet >= 1 mm for a fluid toolpath",
             "8 undeburred rim edge(s), 80 mm total: sharp horizontal/vertical face junctions — deburr-chamfer them (e.g. 0.42 mm) against elephant foot and sharp skin"],
 "assertions":[{"name":"wall_min:1.5","passed":true,"detail":null},{"name":"overhang_max:45.0","passed":true,"detail":null}]}
```

A full example with three bores, a failed overhang assertion and both edge warnings is
`O/out_g2/bores_v5_h5_h20-printability.json`; pins: `O/out_g2/pin_thin_1p5-printability.json`
(`{"diameter_mm":1.5,"length_mm":8.0,"at":[-0.75,9.2e-17,9.0],"note":"pin below FDM minimum diameter 2.0 mm — thicken or replace with an insert"}`);
floating solid: `O/out_g2/two_solids-printability.json`; void: `O/out_g2/hollow_cube-printability.json`.

G0 example from the installed CLI on a copy of the skill's `pin_hinge`
(`O/pin_hinge_g0/outputs/clevis-printability.json`, [M]): the same first 11 keys plus
`overhang` and `assertions`, no `min_wall_at`/`bores`/`pins`/`warnings`; clevis
`min_wall_mm 2.9999999999999996`, `overhang {area_mm2 22.69, max_angle_deg 90.0}`,
`status "assertion_failed"`; the script stopped with `SystemExit(1)` before the tang was
inspected.

### 6.2 `<name>-orientation.json`

`orientation.py:126-137`: `{"kind": "orientation", "name": <name>, "ranked": [OrientationScore...], "best_up_axis": [x,y,z]}`.
No `schema_version`, so `khana diff` cannot compare two orientation files: `_kind`
classifies any file with a `kind` key as printability (`diff.py:22-23`), and
`_require_current_schema` then raises `schema mismatch` (`diff.py:34-41`) [C].

`OrientationScore` (`orientation.py:43-54`): `up_axis` (the candidate tuple as given,
ints), `support_demand_mm3`, `overhang_area_mm2`, `self_bridging_mm2`, `risky_bores`
(int), `plate_contact_mm2`, `contact_vs_footprint` (">0.7 too sticky for auto-eject;
near 0 adhesion/tipping risk", `:52-53`), `height_mm`.

Example (`O/out_g2/slot6_bridge-orientation.json`, first entry [M]):
`{"up_axis":[0,0,1],"support_demand_mm3":0.0,"overhang_area_mm2":0.0,"self_bridging_mm2":240.0,"risky_bores":0,"plate_contact_mm2":960.0,"contact_vs_footprint":0.8,"height_mm":20.0}`, `best_up_axis [0,0,1]`.

### 6.3 How the JSON is consumed

`khana diff` (`U/diff.py:191-246`) compares `status`, `name`, `method`, `bbox`,
`volume_mm3`, `surface_area_mm2`, `center_of_mass_mm`, `is_valid`, `min_wall_mm`,
`overhang` and `assertions` (regressed/fixed/added); it ignores `min_wall_at`, `bores`,
`pins` and `warnings` [C]. Agents read the JSON directly (skill workflow
`SK/SKILL.md:628-644`).

## 7. Oracle runs (parity reference, never kernel input)

All commands ran on copies in `O/` with the khana tool's interpreter:
`uv run --no-project --python ~/.local/share/uv/tools/cad-khana/bin/python <script>`.

| run | command / script | output | markers |
| --- | --- | --- | --- |
| G2, 22 synthetic parts + tessellation sensitivity | `oracle.py g2 out_g2` | `O/out_g2/{<part>-printability.json, <part>-orientation.json, summary.json, tessellation-sensitivity.json}`, log `O/oracle-g2.log` | `O/oracle-g2.done` = `exit=0` |
| G1, same parts | `oracle.py g1 out_g1` | `O/out_g1/`, `O/oracle-g1.log` | `O/oracle-g1.done` |
| G2 probes (false positives/negatives) | `oracle2.py out_g2_probes` | `O/out_g2_probes/probes.json`, `O/oracle2.log` | `O/oracle2.done` |
| G2 concave self-hit probe | `oracle3.py` | `O/out_g2_probes/concave-self-hit.json`, `O/oracle3.log` | `O/oracle3.done` |
| G0 installed CLI | copy of `SK/references/examples/pin_hinge` | `O/pin_hinge_g0/outputs/` | – |

Correction: `O/oracle.py:104` states an exact minimum wall of 5.0 for
`bores_v5_h5_h20`; the exact value is 2.0 (Ø20 bore at x = 18 ends at x = 28, the face is
at x = 30). The measured sequence 2.043 → 2.005 → 2.001 converges to 2.0.

G2 default run, per part [M, `O/oracle-g2.log`]: `inspect` exit (`returned` or
`SystemExit(1)`), time 0.07–0.88 s per part (torus 3528 triangles: 0.88 s), orientation
0.02–0.20 s.

| part | triangles | exit | min wall | overhang | bores | pins | warnings |
| --- | ---: | --- | ---: | --- | ---: | ---: | ---: |
| cube10 | 12 | ok | 10.0 | – | 0 | 0 | 2 |
| plate_1mm | 12 | fail (wall) | 1.0 | – | 0 | 0 | 1 |
| ell_ledge | 28 | fail | 4.0 | 200 / 90 | 0 | 0 | 2 |
| slot6_bridge | 28 | ok | 10.0 | – | 0 | 0 | 2 |
| slot20_bridge | 28 | fail | 5.0 | 800 / 90 | 0 | 0 | 2 |
| cantilever6 | 20 | fail | 6.0 | 120 / 90 | 0 | 0 | 2 |
| bores_v5_h5_h20 | 528 | fail | 2.043 | 493.2 / 90 | 3 | 0 | 2 |
| boss10 | 180 | ok | 9.984 | – | 0 | 0 | 2 |
| pin_thin_1p5 | 180 | fail (wall 1.4977) | 1.498 | – | 0 | 1 | 2 |
| pin_slender_2p5x25 | 180 | ok | 2.496 | – | 0 | 1 | 2 |
| plate_fillet05 | 124 | ok | 5.0 | – | 0 | 0 | 2 |
| hollow_cube | 24 | ok | 5.0 | – | 0 | 0 | 3 |
| two_solids | 24 | ok | 4.0 | – | 0 | 0 | 3 |
| chamfer45_bottom | 20 | ok | 20.0 | – | 0 | 0 | 2 |
| cyl_horizontal_r5 | 164 | fail | 9.984 | 164.4 / 90 | 0 | 0 | 0 |
| sphere_r5 | 868 | fail | **0.493** | 51.1 / 83.97 | 0 | 0 | 0 |
| cone_inv_45 | 248 | fail | **0.060** | **54.0 / 45.94** | 0 | 0 | 0 |
| cone_inv_46 | 248 | fail | 0.059 | 276.2 / 46.93 | 0 | 0 | 0 |
| cone_inv_50 | 248 | fail | 0.057 | 325.9 / 50.88 | 0 | 0 | 0 |
| torus_R10_r3 | 3528 | fail | 5.962 | 308.9 / 90 | 0 | 0 | 0 |
| cup_wall05 | 28 | fail (wall) | 0.5 | – | 0 | 0 | 2 |
| bore_near_top | 184 | fail (wall) | 0.514 | – | 1 | 0 | 2 |

Tessellation sensitivity (relative linear deflection / angular rad → triangles; `O/out_g2/tessellation-sensitivity.json`, plus torus and web in `probes.json`) [M]:

| part | 0.1/0.3 | 0.05/0.3 | 0.01/0.1 | 0.001/0.05 | exact |
| --- | --- | --- | --- | --- | --- |
| cyl_horizontal_r5 area | 164.41 | 164.41 | 154.57 | 152.09 | 157.08 |
| sphere_r5 area / wall | 51.06 / 0.49 | 51.06 / 0.49 | 44.10 / 0.16 | 45.97 / 3.91 | 46.01 / 10 |
| cone_inv_45 area / angle | 54.01 / 45.94 | same | 31.22 / 45.25 | 21.76 / 45.10 | none / 45 |
| cone_inv_46 area | 276.24 | same | 277.03 | 277.11 | 277.11 |
| cone_inv_50 area | 325.91 | same | 326.86 | 326.95 | 326.97 |
| torus area / angle | 308.91 / 90 | – | 281.86 / 87.14 | 281.96 / 87.86 | 296.09 / 90 |
| bore_near_top wall | 0.514 | 0.514 | 0.5016 | 0.5006 | 0.5 |
| bores_v5_h5_h20 wall | 2.043 | 2.043 | 2.005 | 2.001 | 2.0 |
| web two Ø10 bores wall | 0.4277 | – | 0.4031 | 0.4008 | 0.4 |

The 0.05 relative setting changes nothing against 0.1: the angular tolerance governs [M].

G1 vs G2 differ only in warnings [M, `O/out_g1/summary.json`]: G1 lacks floating and rim
warnings, and counts cavity edges as convex (`hollow_cube` 8 sharp vertical edges vs 4).

## 8. Real-world usage (read-only survey of `~/Workspace/cad`)

`find ~/Workspace/cad -name '*-printability.json'` excluding `.venv` and `worktree`
copies: 175 files (list `O/real-printability-files.txt`), 92 in cad-project-003, 35
cad-project-013, 11 cad-project-046, 11 cad-project-020, 10 cad-project-026, others
≤ 4; dated 2026-08-02 to 2026-09-19 [M]. Aggregates (one `jq -s` over all files) [M]:

- all 175 have the 17-key G2 schema; `is_valid` true everywhere; `min_wall_mm` never null;
- status `ok` 114, `assertion_failed` 61 (failed assertions: `wall_min` 59, `overhang_max` 6);
- `overhang` non-null in only 6 files;
- `overhang_max` thresholds: 45 in 116 files, 90/91 (check disabled) in 52, 48/60.5/66 in 7;
- `wall_min` thresholds: 0.8 ×67, 1.5 ×33, 0.45 ×20, ≤ 0.05 ×17 (0.01 ×2, 0.04 ×5,
  0.05 ×10), 1.2 ×9, and 16 other values;
- `min_wall_mm` < 0.1 in 30 files (typically 0.050–0.054, the sliver floor), 0.1–0.3 in 34;
- bores: 1980 entries (vertical 1441, horizontal 535, slanted 4), max 200 in one file;
  pins: 0; warnings: sharp vertical in 118 files, undeburred rim in 149, no void/floating.

Usage patterns in source [M, grep]: `FDM(wall_min_mm=.8)` dominates (cad-project-003 family);
`overhang_max_deg=91` to disable the overhang assertion (for example
`cad-project-035/assembly.py:55-61`, `cad-project-048/assembly.py:60,66`);
`try: inspect(...) except SystemExit: status = "review"` in the cad-project-003 family
(worklog step 3); waiver comments explaining thresholds (`cad-project-026/assembly.py:69`,
`:76-84`). Reading: the checks are useful enough that Marc runs them on every build, and
noisy enough that a third of the runs switch one of them off globally [I].

## 9. Documentation drift

- `SK/references/printability.md` (identical to the upstream skill copy) describes the
  G0 algorithms: no bore or bridge exemption, no `min_wall_at`, and still says the build
  plate is the only exclusion (`:59-101`) [C].
- `SK/SKILL.md:20-56` documents G1 (bores, pins, bridges, voids, sharp vertical edges,
  contact ratio); neither skill copy mentions the G2 floating-solid and rim warnings [M:
  grep], although 149 of 175 real outputs contain rim warnings.
- `SK/SKILL.md:602-611` lists only the G0 JSON fields.
- The constant name `TESSELLATION_TOLERANCE_MM` hides that the value is relative (section 4).

## 10. wonky today

- Policy: `W/docs/python-khana.md:97-117` (refused names; printability rows `:109-110`),
  decision 12 `--khana-checks=skip` for `check()`/`inspect()` only (`:125-163`); `FDM`
  provided as plain settings (`:29`).
- Implementation: every public printability and tessellation function is a
  `refused_call`, every result type a `refused_type`, `inspect` a `checked_call`
  returning `NotRun` under skip (`W/python/cad_khana/_wonky.py:38-48`, `:113-136`); all
  numeric constants are provided with upstream values (section 1). **Gap:**
  `orientation.CANDIDATES` is missing; private helpers raise `AttributeError`
  (`_wonky.py:148-149`), which matches CPython behaviour for a missing private name.
- Corpus: 27 files import cad_khana; refused printability calls: `inspect` 20,
  `detect_overhang` 2, `detect_bores` 2, `detect_pins` 1, `enclosed_voids` 1,
  `sharp_vertical_edges` 1 (`W/docs/python-khana.md:241-246`).
- Kernel pieces reusable for an exact implementation: section 11.

## 11. Kernel primitives this area needs

| primitive | exactness required | exists in wonky? |
| --- | --- | --- |
| outward normal field `n(p)` per face with `same_sense` | exact (closed form) | surface data yes (`analytic.bend:21-35`); orientation helper in the host only (`print-mesh.mjs:52-60`) |
| exact trimmed-face area (plane, cylinder, cone closed form; sphere, torus closed form for circle-bounded regions, else certified quadrature) | exact or stated bound | no (volume uses the same Green/Stokes machinery, `volume.bend:5-30`) |
| face ∩ angular band `{-n·u > c}` and its area / first moment (∫h dA) | exact (arccos band limits, closed-form integrals) | no |
| line/sphere and line/torus roots | exact quadratic; certified quartic isolation | no: kind 4 unresolved (`ray.bend:320-325`) |
| forward ray to the first trimmed-boundary crossing | exact with face membership | roots yes (`ray.bend`), trims/forward selection no (`ray.bend:7-10`) |
| face membership for cone, sphere, torus faces | exact | planes and cylinders only (`face-classification.bend`, `cylinder-classification.bend`) |
| solid point classification for all five surfaces | exact | plane and cylinder only (`solid-classification.bend:145-152`) |
| double-normal pairs between quadric/torus faces + edge-constrained minima | closed form; certified root isolation otherwise | no |
| support function / exact plate level and bbox along any `u` | exact | no |
| plane section at height `h` (first-layer band, section spans) | exact contours | yes (`section.bend`) |
| edge dihedral angle and convexity from normals + coedge orientation | exact sign predicate | no (topology data exists) |
| shells and lumps (face connectivity), inner/outer shell via signed volume | exact topology | volume yes; connectivity queries no |
| volume, centre of mass | stated bound | volume yes (`volume.bend`, `volume.mjs:104`); COM no |
| coaxiality / equal-radius grouping of split faces | exact predicate with stated tolerance, or construction identity | no |
| minimal width of a planar region (lines + arcs) | exact | no |
| face across an edge (adjacency) | exact topology | data yes, query no |
| certified tagged print mesh (fallback and viewer overlay) | stated deviation | yes (`print-mesh.mjs:183`, `tessellate.bend`) |

## 12. Improvement ideas over cad_khana

1. **Exact per-face overhang** with angular sub-bands on cylinders and cones, caps on
   spheres and bands on tori: 45° countersinks and conical chamfers pass exactly like
   planar ones (removes the measured false positives and Marc's 48°/66° waivers).
2. **Explicit first-layer band** (`first_layer_mm`) instead of the 1 µm centroid test:
   what is within the first layer is supported by the plate; exact via a plane section.
3. **Well-posed wall thickness:** double-normal thickness (exact witnesses `p, q`, face
   ids) plus a separate **knife-edge report** (edges with dihedral < 90°). Removes the
   0.05 floor that 30 of 175 real outputs show and makes `wall_min_mm` meaningful again.
4. **Topological bridges:** exact minimal width and anchoring from adjacent faces; fixes
   rotated slots, thin walls, L-shaped ceilings.
5. **Findings with locations, not one aggregate:** every flagged region, bore, pin and
   edge with face ids and coordinates, so the viewer can highlight it and a design can
   waive it locally ("this countersink mouth is fine") instead of raising a global
   threshold (52 of 175 runs disable overhang, 17 disable wall).
6. **Exactness label per metric** (`exact` / `bounded ±e` / `approximate, deviation d`)
   following AGENTS.md and `W/src/exactness.mjs`; anything not computable exactly is a
   capability error or explicitly labelled, never a silent mesh number.
7. **Bores and pins from analytic data and construction identity:** concavity from
   `same_sense`, grouping across split faces, through/blind and depth, fillets excluded
   by tangency, orientation-aware pin notes.
8. **Edge advisories on curved edges** (cylinder rims) with exact convexity; group
   repeated micro features (slide ribs) into one finding with a count.
9. **Orientation from exact integrals:** exact ties reported, lay-flat candidates from
   planar faces and cylinder axes, per-orientation bore report; `schema_version` on
   `orientation.json` so it can be diffed.
10. **Compatible output:** keep the 17 G2 keys and the assertion names so Marc's
    `watch.py`, `khana diff` and agents keep working; add new data under new keys
    (`findings`, `exactness`, `knife_edges`), and keep `SystemExit(1)` semantics.
11. **Parity oracle as regression set:** `O/` (22 synthetic parts, probes, the 175 real
    outputs once their models build in wonky) with a documented list of intended
    differences.
12. **Record in `brep.json`:** the host records each `inspect()` result as it already
    records not-run entries (decision 12), so a build is "checked" only when the checks
    actually ran.

## 13. Open questions

- Parity or improvement: should wonky reproduce the ray-method number (with its mesh
  artifacts) for comparability, or only the well-posed exact metrics? Product decision.
- Defaults for the new parameters (`first_layer_mm`, knife-edge angle) and whether the
  heuristics `SMALL_BORE_MM = 12`, `BRIDGE_MAX_MM = 10`, `PLATE_TOUCH_MM = 0.3` stay
  fixed or become `FDM` fields (upstream `FDM` has only three fields).
- G2's floating-solid and rim checks are uncommitted upstream, but Marc's outputs show he
  runs them: treat G2 as the reference?
- Warning texts are free English strings; do consumers parse them, or can wonky switch to
  structured findings with the old strings kept for compatibility?
- Tilted-up tori and cone/torus wall pairs: certified quadrature/root isolation or
  capability errors at first?
- Where the analysis runs: AGENTS.md puts geometry in Bend; printability metrics are
  geometric queries, so they belong in `kernel/` with the host only carrying results.
- `orientation.json` without `schema_version`: add it (breaks byte parity) or not?

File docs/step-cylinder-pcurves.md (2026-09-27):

# Explizite PCurves für getrimmte Zylinderflächen

`kernel/step-cylinder-pcurves.bend` plant die STEP-PCurves eines ganzen Körpers
atomar. `step-cylinder-pcurves-geometry.bend` erzeugt die Parameterkurven und
Fehlerschranken. Die bestehenden Vollband-Module aus
[`step-pcurves.md`](step-pcurves.md) bleiben unverändert.

Der neue Pfad erhält die analytischen 3D-Kurven, Trims, Vertices, geteilten
Kanten und Coedges. Ausschließlich die zweidimensionalen PCurves werden als
explizite B-Splines dargestellt. Der räumliche Gesamtfehler darf höchstens
`1e-8 mm` betragen. OCCT dient ausschließlich der unabhängigen Prüfung bereits
exportierter Artefakte; es konstruiert oder heilt keine Produktionsgeometrie.

## Unterstützte Körper und Domänen

Vor der Planung prüft der native `curved-validate`-Audit den ganzen Körper mit
seinem aufgezeichneten Quellbudget. Unterstützt sind ebene und zylindrische
Flächen, wobei jede Cylinder-Fläche genau einen äußeren Loop besitzt. Inward
Cylinder-Flächen sind eingeschlossen. Die Zylindergrenzen bestehen aus
Circle-, Ellipse- und Generator-Line-Kanten. Ein Generator darf als Seam zweimal
in entgegengesetzter Richtung vorkommen. Zwei unterschiedliche Cylinder-Flächen
dürfen eine Kante teilen.

AutoDomain löst Lines auf endliche Intervalle und geschlossene Koniken auf eine
Periode ab ihrem tatsächlichen Kantenvertex auf. `GivenDomain{Untrimmed}` ist
ebenfalls nur bei geschlossenen Koniken zulässig. Explizite Intervalle werden
ohne Umskalieren oder individuelles Winkel-Wrapping erhalten. Negative Werte
und Werte über `2*pi` sind zulässig. Periodische Intervalle müssen nach der
bestehenden Domänenregel innerhalb `±8*pi` liegen und kürzer als eine Periode
sein; der Export lehnt zusätzlich die numerische Guard-Zone direkt an einer
vollen Periode ab. Explizite Vollperioden-Intervalle werden somit klar abgewiesen.

Mehrere Zylinderloops, fehlende Trims offener Koniken, unauflösbare Charts,
inkonsistente Seams, mehr als zwei Kantenassoziationen oder unzureichende
Fehlerbudgets ergeben `Unresolved`. Auch bei einer späten Ablehnung enthält die
Rückgabe keine teilweise erfolgreiche PCurve-Liste. Der native Pfad besitzt
keinen automatischen Ausweichpfad zum impliziten Reader-PCurve-Fitting.

## API und Assoziationen

Der synchrone Adapter serialisiert und decodiert ausschließlich:

```js
const native = await loadStepCylinderPCurves();
const plan = cylinderPCurves(native, bodyOrSolid, {
  budgetMm: 1e-8,
  // optional: domains, inputTolerance
});
```

Die entsprechende native Funktion ist
`for_cylinders_domains(solid, domains, tolerance, source_budget, budget)`.
`curveRange` am B-rep bleibt gegenüber einem optionalen AutoDomain-Override
verbindlich. Der Adapter prüft die Repräsentationsfelder; geometrische
Domänenauflösung, Audit, Chartwahl und alle Assoziationen entstehen in Bend.

Ein aufgelöstes Ergebnis hat diese Struktur:

```text
{ status: 'Resolved', maxTotalBoundMm,
  charts: [{ faceIndex, closureBoundMm,
    pcurves: [{ edgeIndex, loopIndex, useIndex,
      forward, increasing, periodLift,
      first, last, degree, points, knots, multiplicities,
      approximationBoundMm, supportBoundMm, normalizationBoundMm,
      numericGuardMm, totalBoundMm }] }],
  edges: [{ edgeIndex, kind: 'Ordinary' | 'Seam',
    associations: [{ faceIndex, pcurveIndex }] }] }
```

`periodLift` ist eine nativ bestimmte ganzzahlige Periodenzahl. Sämtliche
ausgegebenen Pole sind bereits verschoben; der Host darf daraus keine neuen
Geometrieentscheidungen ableiten. `first/last` sind immer natürliche
3D-Kurvenparameter. `increasing` bezeichnet separat die Loop-Traversierung.
Der aktuelle einzelne Loop trägt `loopIndex: 0` aus dem nativen Ergebnis.

Eine Ordinary-Kante besitzt eine Assoziation bei Cylinder/Plane oder zwei bei
Cylinder/Cylinder. Eine Seam besitzt zwei Assoziationen auf derselben Fläche.
Ihre beiden geraden PCurves unterscheiden sich genau um eine U-Periode. Bend
liefert die niedrigere U-Lage zuerst. Ordinary-Assoziationen folgen der nativen
Flächenreihenfolge. Der Host serialisiert diese Referenzen über `SURFACE_CURVE`
beziehungsweise `SEAM_CURVE`, jeweils mit der unveränderten analytischen
3D-Kurve als primärer Geometrie (`CURVE_3D`). Kein zusätzlicher `EDGE_CURVE` wird
für eine Seam erzeugt.

Fehler liefern `{ status: 'Unresolved', reason, ...indices }`; vorhandene
`faceIndex`, `loopIndex`, `useIndex` und `edgeIndex` lokalisieren den Fehler.

## Chart und kontinuierliche Schranke

Für natürliche Konikenparameter gilt:

```text
u(t) = phase + sign*t + 2*pi*periodLift
v(t) = z0 + zc*cos(t) + zs*sin(t)
```

Die vollständigen radialen Konikkoeffizienten bestimmen und prüfen diese
Darstellung. Lines erhalten konstantes U und affines V. Bei der Loop-Wanderung
bedeutet `coedge.forward == edge.sameSense` zunehmenden natürlichen Parameter.
Die Flächenorientierung `face.sameSense` ändert diese Regel nicht.

Bend hebt jeden anschließenden Use nur um ganzzahlige Perioden an und prüft die
räumlich gewichteten UV-Joins sowie den Loop-Schluss. Endpunkte oder Phasen
werden nicht passend verschoben. Der größte Join-/Schlussfehler geht in die
Supportschranke aller PCurves des Charts ein. Für eindeutige, numerisch begrenzte
Charts gelten `radius > 4*budget` und `abs(periodLift) <= 16`. Schleifen mit
nichtschließendem Lift werden abgewiesen.

Die V-Komponente einer Konik verwendet kubische Hermite-Segmente mit
`amplitude*h^4/384`, `amplitude = sqrt(zc²+zs²)`, und höchstens 1024 dyadisch
gewählten Segmenten. U ist exakt linear. Endknoten werden direkt aus der
admittierten Domäne übernommen. Lines sind Grad-1-B-Splines über derselben
Domäne; dadurch bleiben ihr Parametermaßstab und ihre affine V-Komponente
erhalten.

Die Gesamtschranke ist die Summe folgender getrennter Beiträge:

| Beitrag | Bedeutung |
| --- | --- |
| `approximationBoundMm` | analytische Hermite-Ganzintervallschranke, bei Lines null |
| `supportBoundMm` | vollständige radiale Koeffizienten-/Line-Endpunktschranke, Kantenvertex- und Chart-Joins |
| `normalizationBoundMm` | räumliche Schranke für STEP-normalisierte Kurven-/Flächenframes und Line-Richtungen |
| `numericGuardMm` | operativer F32x2-Guard `8*angular_guard*scale` |

STEP normalisiert Richtungen in `AXIS2_PLACEMENT_3D` und `DIRECTION`. Bend bildet
diese vorhandene Serialisierungssemantik für die PCurve-Berechnung ab und
schließt ihre Abweichung vom unveränderten Input ein. Bei einer Line beträgt
die Parameterabweichung höchstens
`max(abs(first),abs(last))*norm(D-unit(D))`. Eine materielle Abweichung ergibt
`ParameterMismatch`; Trims werden niemals still umskaliert. Das Quellbudget
und die STEP-Modellunsicherheit erhöhen das PCurve-Budget nicht.

Die Hermite-Schranke ist analytisch. Ihre F32x2-Auswertung samt Guard ist kein
nach außen gerundeter Intervallbeweis. Abgetastete Testmessungen sind zusätzliche
Beobachtungen und ersetzen die native Ganzintervallschranke nicht.

## Nachweise

`test/step-cylinder-pcurves.test.mjs` prüft negative und überperiodische Trims,
Line-Parameteroffsets, umgekehrte Koniken und Seams, inward und transformierte
Bohrungen, eine geteilte Kante zwischen zwei Cylinder-Flächen, explizite
Untrimmed-Domänen, Normalisierung, Budgettrennung und atomare Fehler.

Die Ausgangsdiagnose unter `out/step-pcurves/partial-diagnostics.json` isoliert
die Reader-Fehler der beiden echten P10-Schnitte. Alle 34 Cylinder-Charts und
21 Seam-Paare waren bereits topologisch passend. Die ursprünglichen STEP-Dateien
bestanden die abgetastete B-rep-Prüfung, scheiterten aber an der exakten
CurveOnSurface-Prüfung; rekonstruierte Ellipsen-PCurves wichen bis
`2.57735e-5 mm` von den präzisen 3D-Ellipsen ab.

Die ersten neuen nativen P10-Pläne lösen beide Schnitte vollständig auf und
melden höchstens `5.017e-9 mm` Gesamtfehler. Fokusartefakte und Messungen stehen
unter `out/step-pcurves/cylinder-focused/`. Die unabhängigen Prüfungen des normal
integrierten STEP-Exporters sind eine separate Abnahme; eine erfolgreiche native
Planung allein belegt noch keinen gültigen STEP-Import.

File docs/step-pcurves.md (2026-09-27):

# Explizite STEP-PCurves aus Bend

`kernel/step-pcurves.bend` erzeugt eng begrenzte 2D-Parameterkurven für volle
Kreis-/Ellipsenränder eines Zylinderbandes. Die analytischen 3D-Kurven bleiben
unverändert. Nur ihre Darstellung im Parameterraum der Zylinderfläche wird
explizit approximiert, mit einem räumlichen Gesamtbudget von höchstens
`1e-8 mm`.

Anlass war ein unabhängig reproduzierter STEP-Lesefehler: OCCT rekonstruierte
zu einer präzisen 3D-Ellipse eine Zylinder-PCurve mit etwa `0.000149 mm`
Abweichung, obwohl die importierte Kantentoleranz `1e-7 mm` betrug. Die
standardmäßig abgetastete B-rep-Prüfung übersah dies; die exakte
CurveOnSurface-Prüfung lehnte das Ergebnis ab. Siehe
[`truck-step-review/README.md`](../out/boolean-ports/truck-step-review/README.md).
Der neue Pfad liefert die PCurve selbst aus Bend, ohne Reader-Heilung oder
Geometriekonstruktion durch OCCT.

## Unterstützte Domäne

Der Produktionseinstieg `for_edge_domains` prüft den gesamten Körper mit dem
gemeinsam genutzten nativen Bandvalidator aus `ports/truck-cylinder.bend`:

- zwei Vertices, zwei vollständige periodische Kreis-/Ellipsenränder und eine
  gerade gemeinsame Seam;
- zwei ebene Caps, eine nach außen orientierte Cylinder-Fläche und vollständig
  gepaarte Kantenuses;
- disjunkte globale axiale Wertebereiche der beiden Ränder;
- ausschließlich automatische Kantendomänen.

Die Kanten-/Flächenindizes müssen einen vorhandenen periodischen Rand und seine
Zylinderfläche bezeichnen. Explizite `GivenDomain`-Werte einschließlich voller
Perioden werden derzeit abgewiesen. Der Hostadapter erhält `curveRange` aus
decodierten B-reps als explizite Domäne; er darf diese Information nicht beim
Serialisieren verwerfen. Teilbögen, allgemeine importierte Schalen, Bohrungen,
mehrere Zylinderwände und andere Flächentypen sind nicht abgedeckt.

`cylinder_round` ist zusätzlich als primitives Kurve/Fläche-Werkzeug verfügbar.
Es prüft die Kurveninzidenz, aber keinen ganzen Körper. Es ist kein Ersatz für
den Bandvalidator und keine allgemeine Export-Ausweichstrategie.

## Parameter, Seam und Fehlerbudget

Für den unveränderten natürlichen 3D-Kurvenparameter `t` gilt auf einem
Zylinder:

```text
u(t) = u_start + sign * (t - first)
v(t) = z0 + zc*cos(t) + zs*sin(t)
first <= t <= first + 2*pi
```

`first` stammt vom tatsächlichen periodischen Kantenvertex. Ein Ellipsenrand
kann dort beispielsweise den Parameter `pi` oder `pi/2` haben; ein pauschaler
Start bei null wäre falsch. Eine gemeinsame räumliche Seam bestimmt den
U-Bereich beider Ränder. Positives Winding läuft von `seam_angle` nach
`seam_angle+2*pi`, negatives in umgekehrter Richtung. Dies behandelt auch
unterschiedliche Kurvenframes, umgekehrte Kurvensinne und verschobene
Zylinderframes.

Die U-Komponente ist linear. Für die V-Komponente werden kubische
Hermite-Segmente aus den nativen Funktionswerten und Ableitungen gebildet.
Bei Segmentbreite `h` ist die mathematische Interpolationsschranke

```text
amplitude = sqrt(zc*zc + zs*zs)
interpolation_error <= amplitude * h^4 / 384
```

Bend wählt durch Halbieren höchstens 1024 Segmente und gibt einen kubischen
B-Spline mit `3*N+1` Kontrollpunkten, `N+1` Knoten, Endmultiplizität vier und
innerer Multiplizität drei aus. Die konstanten axialen Kreisränder benötigen
ein Segment; die untersuchten schrägen Ränder benötigen bei `1e-8 mm` Budget
128 Segmente.

Die ausgegebene Gesamtschranke enthält drei getrennte Beiträge:

| Feld | Bedeutung |
| --- | --- |
| `approximation_bound` | Hermite-Ganzintervallschranke für die Höhenfunktion |
| `support_bound` | Normschranke der radialen Koeffizientendifferenzen plus Randvertex-/Seam-Inzidenz |
| `numeric_guard` | vorhandener operativer F32x2-Guard, skaliert mit Koordinaten, Kurvenzentren und Radien |
| `total_bound` | Summe dieser Beiträge, höchstens das explizite Budget |
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

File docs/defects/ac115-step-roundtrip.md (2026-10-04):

# AC115: observer re-export erased a representable analytic wall

The defect was in the CAD-Acid observer's OCCT STEP **re-export**, not the native
B-rep or wonky's STEP writer. `STEPControl_Writer.Write` serialized REALs with
12 significant digits. At V1's placement it erased the bore's positive wall;
the second OCCT import then split the cap boundary edges and rings at artificial
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

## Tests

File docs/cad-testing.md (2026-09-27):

# CAD-Tests mit FeatureScript und Bend

Der Ansatz eignet sich für eine lokale, reproduzierbare Testplattform. Eine
allgemeine CAD-Prüfbibliothek ist der heutige Kern noch nicht: Fähigkeiten und
Messbasis müssen im Bericht ausdrücklich stehen. Das vollständige
`singleStepR10b` scheitert weiterhin an allgemeinen Booleschen Operationen.

## cad-project-043 als Ausgangspunkt

Untersucht wurden `../cad/cad-project-043/pruefstand`, insbesondere `SPEC.md`,
`src/pruefstand/results.py`, `kernel.py` und `primitives/same_as.py`, sowie
`knowledge/foundations/verification.md` und der bestehende Ansichtenrenderer.
Prüfstand hat bereits Spezifikationen für Abstand, Überdeckung, Überstand,
Gleichheit, Schnittstellen, Bewegungsraum, Schraubketten, Zugänglichkeit,
Drucklage, Stabilität und Form. Diese fachlichen Verträge sind wertvoller als
eine zweite Sammlung ähnlich benannter Einzeltests.

Der vorhandene Python-`Body.solid` erwartet build123d/OCP-Objekte. Ein
Bend-Backend lässt sich deshalb nicht einfach als anderes Objekt einsetzen.
Sinnvoll ist eine explizite Backend-Schnittstelle für Messungen und
Geometrieartefakte, mit Fähigkeiten und klaren Fehlern pro Operation. Die
pytest-, Spezifikations- und Berichtsschicht kann darüber weiterverwendet
werden. OpenCascade bleibt ein unabhängiger Prüfer exportierter Artefakte.

Leere Messmengen, nicht aufgelöste Anforderungen, technische Fehler und eine
bestandene Anforderung sind verschiedene Ergebnisse. Auch abgeschnittene
Prüffenster müssen erkennbar bleiben: deren künstliche Ränder können Abstands-
und Kontaktmessungen verfälschen.

## Bereits ausführbare Messungen

`wonky-compare` misst für zwei koaxiale Zylinder mit Bend:

| Messung | Bedeutung |
|---|---|
| Hinzugefügtes / entferntes Volumen | Materialänderung in beide Richtungen |
| Symmetrische Differenz | Summe beider Änderungen; gleiche Gesamtvolumina reichen nicht |
| Gemeinsames Volumen | Volumetrische Überschneidung |
| Mindestabstand | Trennung im unterstützten Zylinderfall |
| Deckflächenkontakt | Exakt zusammenfallende Stirnflächen, mit Kontaktfläche |
| Axiale Überlappungslänge | Kein allgemeiner Eindring- oder Verschiebeabstand |

```sh
node bin/wonky-compare.mjs examples/compare-before.fs examples/compare-after.fs \
  --geometry --out out/comparison-demo
```

Der Bericht enthält Quellenhashes, Toleranz, Messbasis, Grenzen und optional
STEP/B-rep-Dateien für hinzugefügtes, entferntes und gemeinsames Material.
`status: measured` bedeutet, dass eine Messung vorliegt. Ob sie eine
Anforderung erfüllt, entscheidet erst deren separat festgelegter Grenzwert.
Nicht koaxiale oder allgemeine Körper werden explizit abgewiesen.
Vollständig eingeschlossene Hohlräume können skalar verglichen werden; deren
Differenzgeometrie ist noch nicht implementiert.

Abstand null beweist keine Durchdringung. Ein vollständig enthaltener Körper
benötigt auch dann eine Innen/Außen-Klassifikation, wenn sich keine Ränder
schneiden. Prüfstands bestehendes `same_as` verwendet Stichproben auf Netzen;
eine B-rep-Volumendifferenz ist eine zusätzliche, anders begründete Messung.
Für allgemeine Freiformflächen fehlen uns noch die nötigen Algorithmen.

## Standardisierte Bilder

`scripts/render-comparison.py` verwendet den bestehenden cad-project-043-Renderer
und dieselbe orthografische Kamera, Skalierung, Beleuchtung und Auflösung für
Vorher und Nachher. Vier Ansichten, Differenzbilder und eine Übersicht werden
zusammen mit Quellen-, Renderer- und Umgebungshashes gespeichert. Eine
gespeicherte `camera.json` kann für spätere Revisionen wiederverwendet werden;
Geometrie außerhalb des Bildraums führt zu einem Fehler.

```sh
node bin/wonky.mjs examples/bracket.fs --param 'thickness=8*millimeter' --out out/visual-before
node bin/wonky.mjs examples/bracket.fs --param 'thickness=12*millimeter' --out out/visual-after
uv run scripts/render-comparison.py out/visual-before.stl out/visual-after.stl --out out/visual-comparison
uv run scripts/render-comparison.py out/visual-before.stl out/visual-before.stl \
  --camera out/visual-comparison/camera.json --out out/visual-identical
```

Der identische Kontrolllauf hat in allen vier Ansichten **null abweichende
Pixel**, auch vor Anwendung des Schwellwerts. Beim Dickenwechsel bleibt die
Draufsicht unverändert, während Vorder-, Seiten- und Isoansicht Unterschiede
zeigen. Bilder ergänzen deshalb Geometriechecks; innere Änderungen können
unsichtbar bleiben. Dieser Versuch verwendet planare Bend-STLs.

Für analytische B-reps nutzt `scripts/render-brep-comparison.mjs` dieselbe
Tessellierung wie der Review-Viewer. Unterstützt sind auch getrimmte
Zylinderflächen mit Löchern und periodischen Übergängen, vollständige
Kegelbänder und planare Flächen mit Kreis-/Ellipsenrändern:

```sh
node scripts/render-brep-comparison.mjs before.brep.json after.brep.json \
  --out out/curved-visual-comparison --tolerance 0.02
```

Der Export verlangt Anzeigedreiecke für jede Quellfläche. Eine fehlende,
unsichere oder degenerierte Fläche bricht den gesamten Export ab. Die
`.display.stl`-Dateien sind ausdrücklich Anzeigedaten mit deklarierter
Näherungstoleranz. Das Manifest bindet B-rep, Displaynetz und einzelne
Flächen über Hashes und Zuordnungen. Sie ersetzen weder das analytische
Modell noch einen Fertigungs- oder Geometrienachweis.

Der B-rep-Renderer veröffentlicht Bilder, Netze, Kamera und eine Berichtskopie
zusammen unter `generations/<id>/`. Erst danach ersetzt er `report.json`
atomar. Vorhandene Generationen bleiben erhalten; ein Fehler beim letzten
Schritt kann eine vollständige unreferenzierte Generation hinterlassen,
beschädigt aber keine Bilder des bisherigen Berichts. `assetGeneration`
bezeichnet die Ablage, `cameraFile` die wiederverwendbare Kameradatei.
Im Ausgabeverzeichnis verbliebene ältere Bilder werden nicht überschrieben
und gehören nicht automatisch zum aktuellen Bericht.

Beim unabhängig über STEP geprüften gebohrten Zylinder ändert sich der
Innenradius von 2 auf 3 mm, bei gleichem Außenradius 5 mm und Höhe 10 mm.
Vorder- und Seitenansicht bleiben identisch; oben ändern sich 7.297 Pixel
(4,95 %), isometrisch 2.674 (1,81 %). Der identische Kontrolllauf hat in allen
vier Ansichten null abweichende Pixel, auch ohne Schwellwert. Nachweise:
`out/curved-visual-comparison/report.json`,
`out/curved-visual-identical/report.json` und
`out/viewer-qa/curved-step-validation.json`.

Der P10/Box-Diagnoseeingang exportiert 195 Flächen mit 2.980 Displaydreiecken
ohne ausgelassene Fläche; darunter alle 26 P10-Zylinderflächen. Der Bericht
`out/viewer-qa/p10-display-export.json` beschreibt die Anzeige der
Boolean-Eingänge, kein Ergebnis der noch fehlenden Operation.

## Frontends und Ausbaureihenfolge

FeatureScript bleibt der Weg für unveränderte Onshape-Quellen. Der zusätzlich
vereinbarte build123d-Algebra-Frontend ist als begrenzter realer Python-Weg
implementiert: Box, Cylinder, Pos, Boolesche Operatoren und Volumen laufen
über denselben Bend-Kern. Python selbst wertet die Python-Syntax aus.
Das echte build123d/OCP liefert dabei keine Produktionsgeometrie.
Builder-Kontexte, Selektoren und Fillets benötigen eigene, ausdrücklich
implementierte Fähigkeiten. Schon heute können Python-/pytest-Tests
FeatureScript-Dateien testen, ohne den Python-Modellierungsfrontend zu nutzen.

Als gemeinsame Basis bieten sich stabile Körperreferenzen, Einheiten,
Fähigkeitsabfragen und strukturierte Fehler an. Caches müssen Quelltext,
Parameter, eingefrorene Imports, Kernrevision, Numerik und Backend einbeziehen;
Rendercaches zusätzlich Kamera, Netztoleranz und Rendererumgebung. Gleiche
Dateinamen oder Körpernamen allein sind kein Identitätsnachweis.

Zunächst lohnen sich unabhängige Modell- und Prüfbatches auf der CPU. Die
GPU sollte große, regelmäßige numerische Aufgaben übernehmen, sobald die
gemessenen Laufzeiten das rechtfertigen. Ein serieller Featurebaum lässt sich
nicht durch mehr Threads beliebig beschleunigen. Die separaten
Hardwaremessungen stehen in `out/hardware/report.json` und werden mit
`npm run bench:hardware` reproduziert.

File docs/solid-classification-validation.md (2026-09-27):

# Independent solid-classification validation

The reusable runner compares Bend's point-in-solid results with OpenCascade's
`BRepClass3d_SolidClassifier` reading the exported STEP files. Bend builds or imports
the production bodies, applies the placement, evaluates probe coordinates and
exports STEP. OpenCascade only reads those artifacts and provides independent
observations; it does not build, repair or replace production geometry.

Run from the repository root:

```sh
node scripts/check-solid-classification.mjs
```

All generated models, probes, logs and reports are written to
`out/solid-classification-validation/`. The runner rebuilds the three small
examples and freshly imports frozen P10 on every invocation. It does not reuse a
previous classification result.

## Corpus and observed results

The run completed at `2026-09-21T23:25:01.661Z` with 56/56 matches, zero
mismatches, zero unresolved results, zero oracle-unknown results and zero errors.

| Model | Construction and coverage | Inside | Outside | Boundary | Matches |
|---|---|---:|---:|---:|---:|
| Box | `examples/box.fs`, 40 × 20 × 5 mm; interior, exterior, faces, edge and vertex | 4 | 6 | 6 | 16/16 |
| Concave bracket | `examples/bracket.fs`, L-shaped extrusion, 8 mm thick; both arms, concave notch, faces, edges and vertex | 4 | 6 | 6 | 16/16 |
| Bored spacer | `examples/bored-spacer.fs`, outer radius 5 mm, bore radius 2 mm, height 10 mm; material, bore, exterior, planar and cylindrical boundaries | 4 | 6 | 6 | 16/16 |
| P10 in `g0` | Fresh frozen import and the actual placement in r10b line 215 | 1 | 3 | 4 | 8/8 |
| Total | Deterministic coordinates shared by both classifiers | 13 | 21 | 22 | 56/56 |

The P10 probes are two remote points at ±[500, 500, 500] mm, Bend-evaluated
points on edges 248 and 254, the mean of face 0's referenced vertices with
normal offsets −1, 0 and +1 mm, and transformed source vertex 0. The three face
probes classified as Inside, Boundary and Outside respectively. The two edge
probes and source vertex classified as Boundary. Exact coordinates and selection
metadata are preserved in [probes.json](../out/solid-classification-validation/probes.json).

P10 uses this frozen `g0` transformation, with translation in millimetres:

```text
R = [[1, 0, 0],
     [0, 0.9063077870366499, -0.42261826174069944],
     [0, 0.42261826174069944,  0.9063077870366499]]
t = [0, 85.7915071334, -183.980480768]
```

This is the placed P10 input body. It is not a Boolean result or a completed
`singleStepR10b` assembly.

The existing STEP validation also passed for every model: a valid B-rep,
one solid, expected exported topology and positive volume. The three small
volumes agree with Bend. P10's 189 source face areas were independently checked;
its STEP volume was measured as 275773.8409333894 mm³, without a Bend volume
comparison. P10's exported topology is 189 faces, 529 edges and 348 vertices;
the frozen source contains 189 faces, 513 edges and 316 vertices before the
importer's explicit periodic-edge normalization.

## Optional Python interface

The existing invocation and report fields remain available:

```sh
uv run scripts/validate-step.py out/solid-classification-validation/box
```

Add `--points` to classify points on already exported STEP artifacts:

```sh
uv run scripts/validate-step.py --points out/solid-classification-validation/probes.json \
  out/solid-classification-validation/box \
  out/solid-classification-validation/bracket \
  out/solid-classification-validation/bored-spacer \
  out/solid-classification-validation/p10-g0
```

The input format is:

```json
{
  "schema": "wonky-solid-probes/1",
  "toleranceMm": 1e-7,
  "models": [
    {
      "prefix": "out/solid-classification-validation/box",
      "points": [
        {"id": "box.1", "pointMm": [20, 10, 2.5]}
      ]
    }
  ]
}
```

Prefixes are resolved relative to the working directory. The probe file must
cover every requested prefix exactly once and contain no other prefixes. Every
model needs at least one probe; IDs must be nonempty, globally unique strings.
Each coordinate must be a finite number, with exactly three coordinates per
point. Booleans are rejected as numeric coordinates or tolerances. The tolerance
must be finite and positive. Invalid requests fail instead of skipping probes.

With `--points`, each original STEP report gains `pointClassification` containing
the oracle and package version, tolerance, solid count, per-point state,
per-solid observations and SHA-256 hashes of the STEP, B-rep and probe file.
States are `Inside`, `Outside`, `Boundary` or `Unknown`. The oracle package is
pinned to `cadquery-ocp==8.0.1.0.0`.

For multiple solids the Python API combines their observations as a union:
Inside takes precedence over Outside, and Boundary over Outside. Any Unknown
observation, or a mixture of Inside and Boundary, produces Unknown. The current
comparison corpus requires exactly one solid per model.

## Acceptance and negative control

Only equal, resolved Inside/Outside/Boundary results count as matches. A Bend
`Unresolved` result is incomplete evidence, even if the oracle resolves it;
oracle `Unknown` is also incomplete. Execution errors and mismatches fail the
comparison. A model or suite passes only when every requested probe matches.
The Python command supplies observations; the Node runner performs this
acceptance decision.

The runner exits with 0 for all probes matched, 2 for incomplete evidence, and
1 for a mismatch or execution/input/source-change failure. Bend options for
this corpus are `linear: 1e-7`, `angular: 1e-10`, `inputTolerance: 0`; the STEP
classifier tolerance is `1e-7` mm.

Every run includes a negative control through the same comparison function.
In the recorded run, `box.1` was independently Inside for both classifiers.
Changing its Bend result to Outside produced exactly one mismatch,
`accepted: false` and `status: failed`. This verifies that a deliberately wrong
observation cannot be accepted by the comparison layer.

Focused interface checks also passed: 20 invalid requests were rejected by the
original request-loader function, a valid request was accepted, a real CLI
call rejected an unknown prefix, and the default CLI report exactly matched the
original fields of the corresponding oracle report. Details, method and
validator hash are in [api-checks.json](../out/solid-classification-validation/api-checks.json).
JavaScript and Python syntax checks passed.

## Source binding and limits

The report records hashes of all relevant implementation files, example inputs,
frozen fixture/provenance/manifest inputs and generated artifacts. Implementation
hashes were equal before and after the run. Classification also left each Bend
model unchanged. The Python oracle checks that the input STEP, B-rep and probes
remain byte-identical during validation; the runner checks their hashes and
exact probe IDs/coordinates against its own records.

Recorded SHA-256 values:

| Input | SHA-256 |
|---|---|
| Implementation snapshot | `0f6fbb9f3c5ede853b6d0d65e03fe4fe15959ec49815a26c838c93e5c9344e5f` |
| Kernel snapshot | `e5c4988051583fa8f868a68542482e07f3014d1ce02b3c0c4b6c54d9104dfbe8` |
| Frozen r10b FeatureScript | `219ee9630f37f9e54fe7e1b4e09094ab25748a811ed8f9e8b9ebf4892d8b8349` |
| Frozen P10 source body | `b78a8546970e360ee2a3a22661c87d4f9e835d24fe50cedeedde6a19add20dc9` |
| Probe file | `5ea0487f738bbd5701f8b1f34a2e58c078b58ea65cefc5cabbaf231ee3523d6f` |

The frozen-source check also confirmed r10b's 404086 bytes and 1417 lines
against its provenance. P10's hash agrees with the frozen dependency manifest.
The full observations, per-file hashes, topology/area checks and negative
control are in [report.json](../out/solid-classification-validation/report.json),
with a compact [report.md](../out/solid-classification-validation/report.md) and
the separate [STEP oracle report](../out/solid-classification-validation/step-oracle.json).

These finite probes provide evidence for the recorded bodies, placements,
coordinates and implementation. They do not prove global numerical correctness,
general Boolean support or full r10b acceptance. Unresolved results must remain
visible when the corpus or implementation changes.

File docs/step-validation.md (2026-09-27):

# Strict independent STEP validation

`scripts/validate-step.py` reads already exported geometry using OpenCascade.
It does not construct or repair production bodies. The validator now explicitly
requests `BRepCheck_Analyzer(shape, True, False, True)`: geometric checks with
the exact CurveOnSurface method. Successful reports record this method.

## Why the previous default check was insufficient

On a newly constructed oblique full cylinder, the default sampled check reports
validity although the STEP reader's reconstructed cylinder pcurve misses the
3D edge by up to about 0.000149 mm at the measured samples. Its reported edge
tolerance is only 0.0000001 mm. The stronger check rejects the imported shape.

The 3D ellipse itself remains precise. Independent whole-conic coefficient
bounds from high-precision arithmetic place its cylinder residual at about
7e-15 mm for this case. The reader creates a cubic B-spline for the corresponding
2D curve on the cylinder; that representation introduces the observed mismatch.
Changing STEP uncertainty and eight documented reader configurations did not
resolve it. This separates a native geometry check from consumer interoperability.

The reader also measures a shifted volume. Tighter adaptive integration does
not remove the difference. The pcurve inconsistency is established; a complete
numerical attribution of the volume shift is still open. The small integration
error reported by the reader is not an overall geometry error bound.

Evidence and reproduction:

- `out/boolean-ports/truck-step-review/README.md`
- `out/boolean-ports/truck-step-review/pcurve-diagnostics.json`
- `out/boolean-ports/truck-step-review/pcurve-error-bound.json`
- `out/boolean-ports/truck-cylinder-review/native-conic-incidence.json`

The continuous pcurve bound in this diagnostic uses analytic derivative bounds
and a Lipschitz argument with a floating-point guard. It is not a formal
interval-arithmetic proof. No production tolerance was enlarged to accept it.

## Consequences for existing results

Earlier default-check reports remain historical evidence of that weaker check.
In particular, the nine Truck-cylinder exports previously reported as valid
must not be presented as nine successes under the strengthened check. In the
first strict rerun, straight axial cuts passed and oblique cases failed. The
full-band repair and its fresh evidence are described below. Both newly
constructed curved P10 exports currently fail the strict check.

The nine solid-intersection exports, including planar concavity, contact chains
and axial cylinders, have been rerun and passed the stronger validator.
Other historical exports need their relevant strict validation rerun before
promotion. Native success, standard-reader success and strict-reader success
are separate outcomes; the comparison must keep failed exports visible.

A Bend-generated pcurve with an explicit approximation budget is now integrated
for full cylindrical bands with circular/elliptical rims and automatic domains.
All nine Truck full-band exports pass the strict check through the normal
exporter: `out/step-pcurves/integrated-step-validation.json`. Analytic 3D curves
and surfaces are preserved. The pcurve's declared total budget is at most
1e-8 mm and includes the native support and operational arithmetic guards.
Arbitrary imported shells and explicit partial trims remain outside this slice;
the two P10 exports still lack strict independent acceptance.

The volume validator now requests adaptive closed-shell Gauss integration with
relative target 1e-10 and records the returned error estimate. This resolves a
separate fixed-quadrature accuracy limit in the repaired oblique cases. That
estimate describes integration of the imported representation; it does not
certify all source/representation error or replace CurveOnSurface validation.

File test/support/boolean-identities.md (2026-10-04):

# Boolean measure sweep

`test/rust-boolean-identities.test.mjs` builds real operands and results with
Rust. Both identities use canonical BigInt rationals. Planar measurements
publish `volumeExactMm3` (decimal integer numerator/denominator); the value
comes from the audited authoritative world boundary, including replayed
rational construction points, not the rounded projection or f64 volume.
Non-polynomial/radical measurements keep their existing certified bounds.
Explicit enclosure endpoints, or `volumeMm3 ± volumeMm3 * volumeRelBound`,
are converted from binary64 to exact rationals before any interval arithmetic.
A certified point enclosure (equal endpoints or zero radius) is exact as well.
No f64 tolerance is added. The report counts exact and enclosure checks.

There are 94 mandatory pairs and 229 pairs with
`WONKY_BOOLEAN_IDENTITY_LARGE=1`. Fixed scales are 0.005, 1 and 100; the larger
sweep adds 0.01, 0.125, 0.5, 2 and 10. Fixed seed labels 17, 41 and 73 select
precomputed dyadic offsets. Tests never consult a random source. Contacts
include shared faces, edges, vertices and coplanar overlaps. Nesting,
disjointness, thin walls and long bars are explicit generated cases.

The following routing coverage follows `analytic::boolean` and its
`family_boolean` dispatcher. Report route labels name the operand mechanism;
output certificates are counted separately. They do not pretend to be a
runtime dispatch trace. Replayed operands exercise continuation routing.

| Mechanism | Generator |
| --- | --- |
| Orthogonal exact cells | `box-*`, `seed-*` |
| General rational plane arrangement | `convex-*`, `different-axis-*`, `frame-*` |
| General model Boolean (concave leaves) | `concave-*` |
| Exact rational placement plus plane arrangement | `rational-345-*`, `rational-51213-*` |
| Coaxial axial profile | `coaxial-*` |
| Parallel cylinder arrangement, separation/contact | `parallel-*`, `cylinder-contact-*`, `cylinder-disjoint-*` |
| Columns, perforation/holes and shared prism arrangement | `cylinder-box-*` |
| Sphere equatorial box intersection | `sphere-halfspace-*` |
| Cylinder tee union and bicylinder intersection | `cross-cylinder-*`, `tee-unequal-*` |
| Sphere axial cylinder subtraction | `sphere-cylinder-*`, `axial-pythagorean-*` |
| Sphere lens intersection | `sphere-sphere-*` |
| Replayed holed operand/tools | `holed-recut`, `holed-prism-recut` |
| Replayed column operand | `column-recut`, `column-cylinder-recut` |
| Continued arc/line prism arrangement | `stack-recut` |
| Cylinder/box pocket subtraction | `cylinder-pocket` |
| Continued coaxial profile | `coaxial-recut` |
| Coaxial revolution Boolean | `revolve-coaxial` |
| Revolution cutter through prism | `box-revolve` |
| Polynomial-profile shared arrangement | `polynomial-boss` |

`frame-*` uses ordinary FeatureScript Pythagorean direction vectors. Its
normalized axes are binary64 construction values. For **exact** 3/5, 4/5
and 5/13, 12/13 frames, `rational-*` builds the original FeatureScript
operands, applies the existing public rational placement API, registers them
in a fresh modeling context, then executes the unchanged `opBoolean` statement
with the normal parser, interpreter and host builtins. There is no test-only
Boolean implementation or alternative modeling language.

The refusal baseline is per pair and operation, with a named reason; a newly
refusing previously built operation fails even if another operation improved.
Total refusals are also bounded by the recorded baseline. Refusals are not
identity passes. Independently available identities are checked even when the
third operation refused. Operand and measurement errors fail immediately;
only typed `opBoolean` refusals enter the baseline. An empty-result verdict
is counted as a named refusal, never replaced by an invented empty model.
`tmp/boolean-identities/report.json` contains the complete counts, certificates,
refusal reasons and violations; console output omits the large refusal map.
The `built` and `refused` counts denote operations (three attempted per pair),
while `cases` denotes operand pairs and `violations` denotes failed identities.
`completeCases` counts pairs with all three results; `refusedCases` counts pairs
with at least one named refusal. The report is saved after each completed pair
so an unexpected later construction failure does not erase earlier evidence.

`rust/wonky-ops/tests/boolean_identity_measure.rs` builds an actual overlapping
box union and verifies both exact identities plus integer closed forms. It
then drops a contributing boundary face and moves one vertex coordinate by
one binary64 ulp, bypassing topology re-audit deliberately: exact integration
must detect both. The JS checker separately rejects a one-ulp exact mismatch
and verifies closed interval endpoints. These are planted geometry defects,
not mock models presented as live results.

**No claim:** volume identities do not prove topology or shape. A wrong but
volume-preserving result can pass, including a missing face with zero signed
volume contribution. This sweep complements CAD-Acid's closed forms and
independent STEP checks.

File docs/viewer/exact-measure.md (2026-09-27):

# exact-measure: exact geometry, multi-select and closed-form measurement

Package of wave 1 (spec section 12, P0). Reference for the APIs, formulas
and UI. Delivery evidence, open integration steps and gaps are in
`docs/viewer/package-exact-measure.md`.

## Principle

The server computes; the browser formats. Every value is a closed form over
the stored analytic parameters of the `.brep.json` revision (plane origin and
normal, cylinder/cone origin, axis, radius and angle, circle and line
parameters, vertex points), evaluated with `kernel.precise` and `kernel.real`
(double-F32 `Real` arithmetic in Bend). Display triangles and polylines are
never measured. Each value carries its exactness (spec section 8):

- `exact-parameters` with tolerance t: the recorded entity tolerance
  (`validation.toleranceMm`, `vertexTolerancesMm`), or the arithmetic guard
  (one unit in the last place of the stored precision times the body's
  coordinate magnitude), whichever is larger. A face takes the largest
  tolerance of its boundary vertices.
- Parallel, coaxial, coplanar and concentric decisions use the pair angular
  tolerance (below) and the larger entity tolerance t; each row echoes both.
- Relations are evaluated at points of the selected entities, never at the
  stored surface origin: a plane at the centroid of its face's boundary
  vertices (projected onto the plane), a cylinder or cone at the foot of that
  centroid on its axis, a circle at its center, a line at its start.
- `unsupported` with a reason when no closed form exists. Nothing is guessed.

Values print to the decade of their tolerance (`core/format.js`): t = 0.0003
mm gives four decimals, the planar F32 bracket (t = 4.8e-5 mm) five.

## Server

### `GET /api/models/:id/geometry[?aliases=B1.F3,B1.L2&page=N]`

`src/viewer/geometry.mjs` (`geometryEntities`), route
`src/viewer/routes/geometry.mjs`. Without `aliases`: one page of 500
entities (faces, then edges, then vertices), `page` counted from 0, `pages`
in the response. With `aliases`: exactly those entities (face `F`, edge `E`,
vertex `V`, logical face `L`). Unknown alias 404, malformed alias, body alias
or bad page 400, unknown model 404.

| Entity | Fields |
|---|---|
| face | `alias, bodyId, index, logical, fragments, surface, outwardNormal, hole, axisPointNearestOrigin, toleranceMm, exactness` |
| plane surface | `normal` (outward, `sameSense` applied), `offsetMm` (origin·normal), `frame {x, y}`, `originMm` |
| cylinder surface | `radiusMm, diameterMm, sense` (hole/boss from `sameSense`), `axis {direction, pointNearestOriginMm}`, `normalSense` |
| cone surface | `halfAngleDeg, radiusAtOriginMm, rimRadiiMm, apexMm, axis, sense` |
| edge | `curve` (line: `startMm, endMm, direction`; circle: `centerMm, normal, radiusMm, diameterMm, sweepDeg, full`), `range`, `lengthMm`, `class` (from `classifyEdges`), `start, end` |
| vertex | `point, toleranceMm` |
| `logicalFaces[]` | for `L` aliases: `fragments` and the support of the first fragment |

The response also carries `bounds` (union of the recorded body bounds, or
`minMm: null` with "not evaluated: Bn has no recorded bounds") and `bodies`
(per body tolerance and recorded bounds). The axis point nearest the world
origin is p = o − (o·a) a. Arc length of an ellipse has no closed form and
is `unsupported`. The edge `class` comes from `classifyEdges(model)`
(topology-classes, exact model only, cached per model), so the route never
prepares the display scene of a lazily loaded revision.

### `POST /api/models/:id/measure {entities, logical?}`

`src/viewer/measure.mjs` (`measureEntities`), route
`src/viewer/routes/measure.mjs`. `entities` (2 to 8 measured, in selection
order) are aliases, `{alias, modelId}` or selection references
`{modelId, bodyId, entityType, entityIndex}`. A face fragment is measured as
its logical face (`logicalFaces(model)` of topology-classes) unless
`logical: false`. Every pair gets the rows of its type pair:

| Pair | Rows |
|---|---|
| plane / plane | angle between outward normals; parallel (across both faces); parallel offset \|(o2 − c1)·n2\|, or the offset of the smaller face from the other plane when the planes are parallel across it only; coplanar; normals opposed or same |
| line / line | angle; distance between infinite lines; parallel; nearest endpoint gap |
| axis / axis (cylinder, cone, circle, line) | axis angle; axis distance; parallel; coaxial; concentric (circles); radii |
| hole / boss, boss circle inside the hole circle (d + r_boss ≤ r_hole) | coaxial: radial gap r_hole − r_boss and diametral clearance 2·(r_hole − r_boss); parallel: minimum radial clearance r_hole − r_boss − d |
| hole / boss of **one body**, hole circle inside the boss circle (d + r_hole ≤ r_boss) | wall thickness r_boss − r_hole (coaxial) or minimum wall thickness r_boss − r_hole − d (a tube wall, a screw hole in a standoff) |
| hole / boss of **two bodies**, hole circle inside the boss circle | radial gap or minimum radial clearance as above, negative, note "negative: interference of two bodies over X mm of axial overlap" |
| any parallel cylinder pair whose faces do not overlap axially (overlap ≤ t) | axial gap g; **minimum distance between the faces** `faceDistance` = √(D² + g²), D = max(\|r1 − r2\| − d, d − r1 − r2, 0), with exact witness points on the facing rims; or unsupported with the reason; no wall or interference is stated; coaxial pairs also keep the radius difference |
| wall or interference case with an unknown axial range (a boundary edge is not a rim) | coaxial: radius difference with the note; off-axis: unsupported with the reason |
| any two parallel cylinders with disjoint circles (d ≥ r1 + r2) | gap between the surfaces d − r1 − r2 ("Wall between holes", "Gap between cylinders", "Distance between cylinder surfaces") |
| coaxial hole/hole, boss/boss, circles | radius difference |
| one circle inside the other otherwise (non-coaxial) | minimum distance between cylinders r_big − r_small − d |
| crossing circles | no clearance row; the extrema row is unsupported unless the faces do not overlap axially (then `faceDistance`) |

d is the axis offset (0 for coaxial pairs); the containment tests use the
entity tolerance t. "Interference" is only claimed for two different bodies:
within one body the region between a hole and the boss around it is
material, so it is a wall. (Before the 2026-09-23 Regression review every hole/boss
pair used r_hole − r_boss − d, which read the 3 mm wall of the bored spacer
as a −3 mm interference and a separate boss 10 mm away as −16 mm.)

Trim checks (Regression review 2, 2026-09-23), both from exact edge data, never the
display mesh:

- **Axial overlap.** A wall thickness or an interference is only stated when
  the faces overlap along the axis by more than t. The axial range of a face
  is [min, max] of (v − p)·d over its vertices (p, d: the evaluated entity's
  axis), known only when every boundary edge is a line along the axis or a
  circle across it (a rim). Example: a washer resting on a plate over its Ø4
  hole (`scripts/viewer/qa/fixtures/stack-washer.fs`) was reported as a
  −4 mm "interference"; it now reads "Minimum distance between the faces
  4.0000 mm" (OCCT: 4.0000, common volume 0).
- **Faces without axial overlap** (Regression review 3). Every parallel pair whose
  faces do not overlap by more than t gets the axial gap g and the exact
  minimum distance between the trimmed faces, `faceDistance`, the first
  primary quantity. Proof: on a cylinder the height is linear in the surface
  parameters, so every face point lies within the face's vertex range, and
  |p − q|² splits into the cross-section part (≥ D², D the distance between
  the full circles) and the axial part (≥ g²): √(D² + g²) is a lower bound.
  It is stated only when it is attained: the closest points of the circles
  (along the axis offset u; for crossing circles one of the two intersection
  points; for coaxial pairs a direction both rims cover) must lie on the
  facing rim edges (the ones at the facing ends of the two ranges, chosen by
  the range midpoints, so an overlap between 0 and t still joins the near
  rims). Those points are the witness (`segment`, exact anchors, selection
  order); the witness length must equal the value within t. Otherwise the
  pair is refused with a named reason: no rim at the facing end, closest
  points not on the facing rims, axes deviating by more than t over the span
  of the faces, or a witness self-check failure. Before, the coaxial formula
  √((r1 − r2)² + g²) was applied to off-axis pairs too: a Ø4 hole under a
  Ø12 washer offset by 1 mm read 4.0000 with a witness point off the washer
  (`offset-washer.fs`; now 3.0000 between (−2, 0, 6) and (−5, 0, 6), as
  OCCT BRepExtrema). `crossing-stack.fs`: 2.0000 at (2/3, √32/3, 6) and
  (…, 8), as OCCT. `offset-half-boss.fs`: refused ("… not on the facing
  rims of B1.F7 and B2.F3"; OCCT 4.0828 at the arc ends). Corpus check
  (147 models, 24 with STEP): 771 face distances, all within 1e-9·t of
  BRepExtrema, every witness point on its face.
- **Angular coverage.** An off-axis relation (minimum radial clearance,
  minimum wall, gap between cylinders, minimum distance between cylinders)
  needs its closest points, along the axis offset, on the angular coverage
  of both faces (slack t / r); a coaxial relation (radial gap, wall,
  interference) needs a direction both faces cover. Otherwise the row is
  dropped and the extrema row says why ("… lie outside the trimmed arc of
  B1.F4"). Example: the two end caps of the arc slot face away from each
  other; the 10 mm between their supporting circles is solid material
  (OCCT: 20.0000 mm between the faces).
  *Refix 2:* where the faces overlap axially (by more than t), the coverage
  is taken **at one common height of the overlap** (`coverageAt`), not as
  the union of every circle edge of the face. Unrolled, a face bounded by
  rims and axial lines is a rectilinear region of the (angle, height)
  strip; at a height between its vertex heights its coverage is the set of
  intervals between the cut angles (axial lines spanning the height, arc
  ends) whose middle has an odd number of rims above it, at a vertex height
  the union of the bands below and above (the closure). Coverages only
  change at vertex heights, so the check runs at the vertex heights of both
  faces inside the overlap, its ends and the midpoints between them. Faces
  without overlap keep the union of their rim arcs (the rows are relations
  of the supporting cylinders there, next to `faceDistance`). An off-axis
  relation of a face with an unknown axial range (a boundary edge that is
  not a rim or an axial line) is refused with that reason (before, the
  circle edges alone were trusted). Example: `notch-base.fs` with B1.F3
  given an end notch in memory (missing for |angle| < 30° above z 6; the
  kernel cannot cut it yet): the notch-floor arc at z 6 covers the
  direction toward B2.F3, but the faces overlap only at z 7..10. Before,
  "Gap between cylinders 2.0000" exact; now unsupported ("… lie outside the
  trimmed arc of B1.F3 at every height of the axial overlap of the faces");
  OCCT BRepExtrema on the same geometry: 2.2360680 between (5, 0, 6) and
  (7, 0, 7). With the notch floor at z 7 the gap is 2.0000 again (the face
  reaches the direction where B2.F3 starts). Corpus (147 models, 3888
  parallel cylinder pair orders): no row gained or lost; 288 refusals only
  name the overlap in their reason.

Parallel and coaxial decisions use `pairAngularTolerance(bodies, t,
span)` from `geometry.mjs`: max(1e-9 rad, the stored-precision guard of
both bodies, t / max(1 mm, span)). For two planes or two axes (cylinder,
cone, circle, line) the span is the bounding-box diagonal of **both**
entities together (faces: vertices plus the exact boxes of their circle
edges; a face with another curve is padded by its body's extent); for an
axis/plane pair it is the extent of the axis entity, since that relation is
read along the axis. Values are still read at the smaller entity (the
evaluated entity: the smaller of two planes or two axes by extent, ties by
body and alias, never by selection order; the axis of an axis/plane pair),
against the other's support. The decision rows carry `toleranceMm` =
max(t, angular tolerance × span), which exceeds t only when the precision
guard dominates, and a note "decided across both entities (bounding-box
diagonal X mm): the planes deviate from parallel by at most Y mm across
them", Y = |n1 ∓ n2| × span (the chord bounds how far any reading moves over
the span). So:

- **Parallel yes** means: at every point of both faces the distance to the
  other plane lies within the decision tolerance of the stated offset. The
  parallel offset |(o2 − c1)·n2| is exact at c1, the smaller face's centroid
  on its plane (note "evaluated at the centroid of <alias>, varies by at most
  Y mm across both faces").
- **Coplanar** needs offset + Y ≤ the decision tolerance, **coaxial** axis
  distance (at the evaluated entity) + Y ≤ it, so both hold across both
  entities.
- Planes that are parallel within t across the smaller face only (a small,
  slightly tilted pad far out on a large plate) read **Parallel no** and get
  the scoped row `faceToPlaneOffset`, "Offset of <smaller> from the plane of
  <other>", exact at the centroid, with the note "the planes are not parallel
  within t across both faces; … varies by at most Z mm across it" (Z over the
  smaller face's extent, never more than t). It is a supporting-plane
  distance and primary after the parallel offset.
- Two cylinder or cone faces whose axes are parallel within t across the
  smaller face only get no parallel or coaxial relation; the unsupported row
  says so: "(the axes of B2.F3 and B1.F3 are parallel within t across B2.F3
  but deviate by up to 1.02e-2 mm across both faces)".
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

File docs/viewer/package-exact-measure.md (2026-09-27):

# Package exact-measure: delivery report

Wave 1, P0 (spec section 12). Reference for the APIs, formulas and UI:
`docs/viewer/exact-measure.md`. This file covers what the package delivers,
how to use it, the evidence for each acceptance criterion, the integration
steps it still needs, and the gaps.

## What it does

- **Exact geometry API.** `GET /api/models/:id/geometry[?aliases=…&page=N]`
  returns faces (outward normal with `sameSense` applied, plane offset and
  frame, cylinder/cone hole or boss, radius, axis direction, the axis point
  nearest the world origin, logical face and fragments), edges (line and
  circle parameters, parameter range, closed-form length, edge class) and
  vertices, in pages of 500 or by alias (`F`, `E`, `V`, logical `L`). Every
  value is a closed form over the stored analytic parameters with
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

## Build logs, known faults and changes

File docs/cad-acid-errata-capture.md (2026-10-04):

# CE13 / CE14: prepared Onshape captures

Consumer: Claude, the CAD-Acid catalog owner. This brief gates removal of the
AC111/AC129 DISPUTED overlay (errata CE13, CE14). It keeps two FeatureScript
twin defects from being presented as Onshape geometry failures. Delete it once
both corrected live captures are frozen and the two errata resolve. The builder
makes no Onshape requests.

Upload the two corrected Feature Studios. The originals stay frozen history for
the other zones of their groups:

| Erratum | Corrected file | Custom feature | Zone enum | Only change against the original |
|---|---|---|---|---|
| CE13 | `fixtures/cad-acid/fs/acid-boolean-z1-errata.fs` | `acidBooleanZ1` | `AcidBooleanZ1Zone.AC111` | `fSphere(center: Vector)` becomes `opSphere` with the same center (10,2,10) mm and radius `4 + acidRadiusDelta(variant)` mm |
| CE14 | `fixtures/cad-acid/fs/acid-sweep-zw1-errata.fs` | `acidSweepZW1` | `AcidSweepZW1Zone.AC129` | loft connection vertices come from `qAdjacent(qSketchRegion(sketch,false), VERTEX, VERTEX)` (one region vertex per corner) instead of `qCreatedBy(sketch, VERTEX)` |

Neither `onshape-push.mjs --groups` nor the N24 `capture.mjs` can be used
unchanged: both upload the catalog's group default file. Use the corrected
studios and the immutable namespaces returned when they are compiled.

Capture exactly eleven isolated features (never ALL):

| Zone | Variants | Feature parameters |
|---|---|---|
| AC111 | V0, V1, V2, V3, V4 | `variant` = `AcidVariant.<V>`, `zone` = `AcidBooleanZ1Zone.AC111` |
| AC129 | V0, V1, V2, V3, V4, V5 | `variant` = `AcidVariant.<V>`, `zone` = `AcidSweepZW1Zone.AC129` |

Feature write (POST `/api/v9/partstudios/d/<d>/w/<w>/e/<ps>/features`), as in
the N24 capture:

```json
{
  "btType": "BTFeatureDefinitionCall-1406",
  "feature": {
    "btType": "BTMFeature-134",
    "featureType": "<acidBooleanZ1|acidSweepZW1>",
    "name": "<group>-<variant>-<zone>",
    "namespace": "e<corrected-studio>::m<immutable-microversion>",
    "parameters": [
      {"btType":"BTMParameterEnum-145","parameterId":"variant","enumName":"AcidVariant","namespace":"<same>","value":"<V>"},
      {"btType":"BTMParameterEnum-145","parameterId":"zone","enumName":"<AcidBooleanZ1Zone|AcidSweepZW1Zone>","namespace":"<same>","value":"<AC111|AC129>"}
    ],
    "suppressed": false
  }
}
```

Freeze per cell the write response and feature status, STEP, parts, grouped
mass properties, bodydetails and bounding boxes, with the immutable microversion
checked across STEP translation. For a failed cell, also freeze
`getFeatureError` and, if available, the feature status message: N24 recorded
only the enum, so the AC129 throw site is inferred from source, not observed.
Record genuine errors rather than omitting cells. Freeze provenance, the current
catalog bytes, the corrected FS bytes and SHA256SUMS in a new
`fixtures/cad-acid/onshape-ext/<batch>/`. Keep N24 unchanged.

Predictions from the unchanged contracts. These are not substitutes for a live
result:
- AC111 V0-V3: one body, V = 4000 - 36π mm³ ≈ 3886.9027, topology B1 S1 F7 E15
  V10. V4 has its own closed form (radius 161/40).
- AC129 V0-V3, V5: one body, V = 256 + 64√2 mm³ ≈ 346.5097, topology B1 S1 F6
  E12 V8 (four nonplanar lateral strips). V4 has its own closed form (half-width
  4.025).

If a corrected twin still fails, that capture is the Onshape outcome for the
zone and the erratum resolves to it. Both zones stay DISPUTED for every kernel
until then, with reason "awaiting live Onshape re-capture of the corrected twin".
The admission binding needs one catalog step at resolution time: the zone's
`twin.fs` must name the corrected file, as CE9 did for its OCCT twin.

Not an erratum: AC115 V0-V3 `BOOLEAN_NON_MANIFOLD_RESULT` is genuine. The bore
axis sits 2^-30 mm (≈ 9.3e-10 mm) from the front face, below Parasolid's linear
resolution and the std `TOLERANCE.zeroLength` = 1e-8 m (`math.fs:35-38`). V4
(radius +0.025 mm) breaks through and builds. `acid-ac115.fs` keeps the same
`fSphere` call in its AC111 copy, but that file is the twin only for AC115.

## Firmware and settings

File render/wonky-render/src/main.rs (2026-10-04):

mod camera;
mod input;
use bytemuck::{Pod, Zeroable};
use serde::{Deserialize, Serialize};
use std::{io::Read, time::Instant};
mod scene;
mod viewer;
#[derive(Deserialize)]
struct Request {
    vertices: Vec<[f64; 3]>,
    triangles: Vec<[usize; 3]>,
    edges: Vec<Vec<usize>>,
    bounds: [[f64; 3]; 2],
    views: Vec<String>,
    resolution: [u32; 2],
    atlas: u32,
    #[serde(default)]
    perspective: bool,
    #[serde(default)]
    file: Option<String>,
}
#[repr(C)]
#[derive(Clone, Copy, Pod, Zeroable)]
struct Vertex {
    position: [f32; 3],
    normal: [f32; 3],
}
#[derive(Serialize)]
struct Metadata {
    views: Vec<camera::Camera>,
    triangles: usize,
    edges: usize,
    edge_segments: usize,
    width: u32,
    height: u32,
    silhouette_bounds_px: Vec<Option<[u32; 4]>>,
    timings_ms: Timings,
    adapter: String,
}
#[derive(Default, Serialize)]
struct Timings {
    initialize: f64,
    tessellate: f64,
    upload: f64,
    render: f64,
    readback: f64,
    encode: f64,
}
fn ms(t: Instant) -> f64 {
    t.elapsed().as_secs_f64() * 1000.
}
fn main() {
    if std::env::args().nth(1).as_deref() == Some("--build-identity") {
        println!("{}", env!("WONKY_RENDER_SOURCE_HASH"));
        return;
    }
    if let Err(e) = run() {
        eprintln!("{e}");
        std::process::exit(2);
    }
}
fn run() -> Result<(), String> {
    if std::env::args().nth(1).as_deref() == Some("--view") {
        return viewer::run();
    }
    let output = std::env::args().nth(1).ok_or("render/output-required")?;
    let mut json = String::new();
    std::io::stdin()
        .take(256 * 1024 * 1024)
        .read_to_string(&mut json)
        .map_err(|e| e.to_string())?;
    let mut req: Request =
        serde_json::from_str(&json).map_err(|e| format!("render/invalid-input:{e}"))?;
    let t = Instant::now();
    if let Some(file) = req.file.clone() {
        input::load(&file, &mut req)?;
    }
    let tessellate = ms(t);
    validate(&req)?;
    let mut meta = pollster::block_on(render(&req, &output))?;
    meta.timings_ms.tessellate = tessellate;
    println!("{}", serde_json::to_string(&meta).unwrap());
    Ok(())
}
fn validate(req: &Request) -> Result<(), String> {
    if req.views.is_empty()
        || req.views.len() > 16
        || req.atlas == 0
        || req.atlas > 16
        || req.resolution.iter().any(|n| *n < 16 || *n > 4096)
    {
        return Err("render/invalid-layout".into());
    }
    let width = req.resolution[0] * req.atlas;
    let height = req.resolution[1] * (req.views.len() as u32).div_ceil(req.atlas);
    if width > 8192 || height > 8192 {
        return Err("render/image-budget-exceeded".into());
    }
    if req.vertices.is_empty()
        || req.triangles.is_empty()
        || req
            .vertices
            .iter()
            .flatten()
            .chain(req.bounds.iter().flatten())
            .any(|v| !v.is_finite() || v.abs() > 1e30)
        || (0..3).any(|k| req.bounds[0][k] > req.bounds[1][k])
    {
        return Err("render/invalid-geometry".into());
    }
    if req
        .triangles
        .iter()
        .flatten()
        .chain(req.edges.iter().flatten())
        .any(|i| *i >= req.vertices.len())
        || req.edges.iter().any(|e| e.len() < 2)
    {
        return Err("render/invalid-index".into());
    }
    for p in &req.vertices {
        if (0..3).any(|k| p[k] < req.bounds[0][k] - 1e-6 || p[k] > req.bounds[1][k] + 1e-6) {
            return Err("render/bounds-do-not-enclose-mesh".into());
        }
    }
    Ok(())
}
async fn render(req: &Request, output: &str) -> Result<Metadata, String> {
    let initialize_start = Instant::now();
    let instance = wgpu::Instance::new(&wgpu::InstanceDescriptor {
        backends: wgpu::Backends::METAL | wgpu::Backends::VULKAN,
        ..Default::default()
    });
    let adapter = instance
        .request_adapter(&wgpu::RequestAdapterOptions::default())
        .await
        .ok_or("render/no-headless-adapter")?;
    let adapter_name = adapter.get_info().name;
    let (device, queue) = adapter
        .request_device(
            &wgpu::DeviceDescriptor {
                label: Some("wonky renderer"),
                required_features: wgpu::Features::empty(),
                required_limits: wgpu::Limits::default(),
                memory_hints: wgpu::MemoryHints::MemoryUsage,
            },
            None,
        )
        .await
        .map_err(|e| format!("render/device:{e}"))?;
    let mut timings = Timings {
        initialize: ms(initialize_start),
        ..Default::default()
    };
    let start = Instant::now();
    let cameras = req
        .views
        .iter()
        .map(|v| camera::camera(v, req.perspective, req.bounds, req.resolution))
        .collect::<Result<Vec<_>, _>>()?;
    let scene = scene::Scene::new(
        &device,
        req,
        &cameras.iter().map(|c| c.matrix).collect::<Vec<_>>(),
        wgpu::TextureFormat::Rgba8Unorm,
    );
    let width = req.resolution[0] * req.atlas;
    let height = req.resolution[1] * (req.views.len() as u32).div_ceil(req.atlas);
    let texture = |format, usage| {
        device.create_texture(&wgpu::TextureDescriptor {
            label: None,
            size: wgpu::Extent3d {
                width,
                height,
                depth_or_array_layers: 1,
            },
            mip_level_count: 1,
            sample_count: 1,
            dimension: wgpu::TextureDimension::D2,
            format,
            usage,
            view_formats: &[],
        })
    };
    let color = texture(
        wgpu::TextureFormat::Rgba8Unorm,
        wgpu::TextureUsages::RENDER_ATTACHMENT | wgpu::TextureUsages::COPY_SRC,
    );
    let depth = texture(
        wgpu::TextureFormat::Depth32Float,
        wgpu::TextureUsages::RENDER_ATTACHMENT,
    );
    let color_view = color.create_view(&Default::default());
    let depth_view = depth.create_view(&Default::default());
    let stride = (width * 4).div_ceil(256) * 256;
    let readback = device.create_buffer(&wgpu::BufferDescriptor {
        label: None,
        size: stride as u64 * height as u64,
        usage: wgpu::BufferUsages::COPY_DST | wgpu::BufferUsages::MAP_READ,
        mapped_at_creation: false,
    });
    timings.upload = ms(start);
    let start = Instant::now();
    let mut encoder = device.create_command_encoder(&Default::default());
    scene.draw(
        &mut encoder,
        &color_view,
        &depth_view,
        req.resolution,
        req.atlas,
    );
    queue.submit(Some(encoder.finish()));
    device.poll(wgpu::Maintain::Wait);
    timings.render = ms(start);
    let start = Instant::now();
    let mut copy = device.create_command_encoder(&Default::default());
    copy.copy_texture_to_buffer(
        wgpu::TexelCopyTextureInfo {
            texture: &color,
            mip_level: 0,
            origin: wgpu::Origin3d::ZERO,
            aspect: wgpu::TextureAspect::All,
        },
        wgpu::TexelCopyBufferInfo {
            buffer: &readback,
            layout: wgpu::TexelCopyBufferLayout {
                offset: 0,
                bytes_per_row: Some(stride),
                rows_per_image: Some(height),
            },
        },
        wgpu::Extent3d {
            width,
            height,
            depth_or_array_layers: 1,
        },
    );
    queue.submit(Some(copy.finish()));
    let (send, recv) = std::sync::mpsc::channel();
    readback.slice(..).map_async(wgpu::MapMode::Read, move |r| {
        let _ = send.send(r);
    });
    device.poll(wgpu::Maintain::Wait);
    recv.recv()
        .map_err(|e| e.to_string())?
        .map_err(|e| format!("render/readback:{e}"))?;
    let mapped = readback.slice(..).get_mapped_range();
    let pixels: Vec<u8> = mapped
        .chunks(stride as usize)
        .flat_map(|row| row[..width as usize * 4].iter().copied())
        .collect();
    drop(mapped);
    readback.unmap();
    timings.readback = ms(start);
    let start = Instant::now();
    let silhouette = (0..req.views.len())
        .map(|i| {
            let mut bbox = [u32::MAX, u32::MAX, 0, 0];
            let mut any = false;
            for y in 0..req.resolution[1] {
                for x in 0..req.resolution[0] {
                    let ox = (i as u32 % req.atlas) * req.resolution[0] + x;
                    let oy = (i as u32 / req.atlas) * req.resolution[1] + y;
                    if pixels[((oy * width + ox) * 4 + 3) as usize] > 0 {
                        any = true;
                        bbox[0] = bbox[0].min(x);
                        bbox[1] = bbox[1].min(y);
                        bbox[2] = bbox[2].max(x + 1);
                        bbox[3] = bbox[3].max(y + 1);
                    }
                }
            }
            if any {
                Some(bbox)
            } else {
                None
            }
        })
        .collect();
    let file = std::fs::File::create(output).map_err(|e| e.to_string())?;
    let mut png = png::Encoder::new(std::io::BufWriter::new(file), width, height);
    png.set_color(png::ColorType::Rgba);
    png.set_depth(png::BitDepth::Eight);
    let mut writer = png.write_header().map_err(|e| e.to_string())?;
    writer
        .write_image_data(&pixels)
        .map_err(|e| e.to_string())?;
    writer.finish().map_err(|e| e.to_string())?;
    timings.encode = ms(start);
    Ok(Metadata {
        views: cameras,
        triangles: req.triangles.len(),
        edges: req.edges.len(),
        edge_segments: scene.line_count as usize / 2,
        width,
        height,
        silhouette_bounds_px: silhouette,
        timings_ms: timings,
        adapter: adapter_name,
    })
}

#[cfg(test)]
mod tests;

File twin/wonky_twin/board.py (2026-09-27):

"""SKR Pico endpoint: validation order and texts match the pinned firmware."""
import json
import struct
import time
from .framing import Frame
from .motion import Stepper

NAMES = {
    "feeder": ["c_channel_1_rotor", "c_channel_2_rotor", "c_channel_3_rotor", "carousel"],
    "distribution": ["chute_stepper", "distribution_aux_1", "distribution_aux_2", "distribution_aux_3"],
}
INPUT_PINS = (4, 3, 25, 16)
OUTPUT_PINS = (21, 23, 17, 18, 20)
# (name, request struct format or None for variable length, channel count)
COMMANDS = {
    0x00: ("INIT", "", None), 0x01: ("PING", None, None),
    0x02: ("REBOOT_BOOTLOADER", "", None), 0x03: ("GET_OBSERVABILITY", "", None),
    0x04: ("GET_VERSION", "", None),
    0x10: ("MOVE_STEPS", "i", 4), 0x11: ("MOVE_AT_SPEED", "i", 4),
    0x12: ("SET_SPEED_LIMITS", "II", 4), 0x13: ("SET_ACCELERATION", "I", 4),
    0x14: ("IS_STOPPED", "", 4), 0x15: ("GET_POSITION", "", 4),
    0x16: ("SET_POSITION", "i", 4), 0x17: ("HOME", "iB?", 4),
    0x18: ("JITTER", "iiii", 4), 0x19: ("IS_JITTERING", "", 4),
    0x1A: ("ENABLE_STALL_DETECTION", "?", 4), 0x1B: ("GET_STALL_STATUS", "", 4),
    0x1C: ("CLEAR_STALL", "", 4), 0x20: ("SET_ENABLED", "?", 4),
    0x21: ("SET_MICROSTEPS", "H", 4), 0x22: ("SET_CURRENT", "BBB", 4),
    0x28: ("READ_REGISTER", "B", 4), 0x29: ("WRITE_REGISTER", "BI", 4),
    0x30: ("READ", "", 4), 0x31: ("WRITE", "?", 5), 0x32: ("WRITE_PWM", "H", 5),
    0x40: ("MOVE_TO", "H", 0), 0x41: ("SET_SPEED_LIMITS", "HH", 0),
    0x42: ("SET_ACCELERATION", "H", 0), 0x43: ("GET_POSITION", "", 0),
    0x44: ("IS_STOPPED", "", 0), 0x45: ("STOP", "", 0),
    0x46: ("SET_ENABLED", "?", 0), 0x47: ("SET_DUTY_LIMITS", "HH", 0),
    0x48: ("MOVE_TO_AND_RELEASE", None, 0),
}


def json_bytes(value):
    return json.dumps(value, separators=(",", ":")).encode()


class Board:
    def __init__(self, role, revision="dev", reboot_seconds=1.0):
        self.role = role
        self.revision = revision
        self.reboot_seconds = reboot_seconds
        self.offline_until = 0.0
        self.steppers = [Stepper(name) for name in NAMES[role]]
        self.inputs = [1] * 4
        self.outputs = [0, 0, 65535, 0, 0]
        self.output_modes = ["digital"] * 5
        self.initialize()

    def initialize(self):
        # initialize_hardware changes configuration, not absolute position or
        # actual pose (Stepper::initialize itself only configures GPIO).
        for stepper in self.steppers:
            stepper.set_limits(16, 4000)
            stepper.acceleration = 20000
            stepper.initialize_driver()
            stepper.stall_enabled = False
        self.outputs[:] = [0, 0, 65535, 0, 0]
        self.output_modes[:] = ["digital"] * 5

    def handle(self, request):
        if request.address != 0 or time.monotonic() < self.offline_until:
            return None
        command, channel, payload = request.command, request.channel, request.payload
        length = request.declared_length if request.declared_length is not None else len(payload)

        def reply(data=b"", error=False):
            return Frame(0, command | (0x80 if error else 0), channel, data)

        def nack(message):
            return reply(message.encode("ascii"), True)
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

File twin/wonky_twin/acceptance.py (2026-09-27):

"""Re-runnable live A2-A5 observations, not independent certification.

Run with --run-file from `wonky-twin up --with-backend`. The real backend
routes own initialization/homing/jogs. Missing observations fail, not skip.
"""
import argparse
import asyncio
import json
from pathlib import Path
import re
import subprocess
import time
import urllib.request
import urllib.error

from .backend import BACKEND, TMP_ROOT


def http(url, payload=None):
    request = urllib.request.Request(url, data=json.dumps(payload).encode() if payload is not None else None,
                                     headers={"Content-Type": "application/json"})
    with urllib.request.urlopen(request, timeout=3) as response:
        return json.load(response)


def wait_for(fn, timeout=60):
    deadline = time.monotonic() + timeout
    while time.monotonic() < deadline:
        try:
            result = fn()
            if result:
                return result
        except (urllib.error.URLError, TimeoutError):
            pass
        time.sleep(.05)
    raise AssertionError("Live acceptance condition timed out")


def command(args):
    result = subprocess.run(args, capture_output=True, text=True)
    print("$", " ".join(args), "\n" + result.stdout + result.stderr, flush=True)
    return {"command": args, "code": result.returncode, "stdout": result.stdout, "stderr": result.stderr}


async def websocket_observation(url, epoch):
    import aiohttp
    async with aiohttp.ClientSession() as session:
        async with session.ws_connect(url) as ws:
            samples = []
            start = time.monotonic()
            for _ in range(31):
                message = await ws.receive_json(timeout=2)
                assert message["schema"] == "wonky.twin-snapshot/1" and message["epoch"] == epoch
                samples.append(message["sim_ns"])
            assert all(a < b for a, b in zip(samples, samples[1:]))
            return {"frames": len(samples), "elapsed_s": time.monotonic()-start,
                    "first_sim_ns": samples[0], "last_sim_ns": samples[-1]}


def safety_observation(run, report):
    api, pid = run["backend_url"], str(report["backend_pid"])
    report["network"] = command(["lsof", "-nP", "-a", "-p", pid, "-i"])
    fields = command(["lsof", "-nP", "-a", "-p", pid, "-i", "-Fn"])
    assert fields["code"] == 0, fields
    sockets = [line[1:] for line in fields["stdout"].splitlines() if line.startswith("n")]
    assert sockets, "No live backend sockets observed"
    for connection in sockets:
        for endpoint in connection.split("->"):
            assert re.fullmatch(r"(?:127\.0\.0\.1|\[::1\]):\d+", endpoint), connection
    report["files"] = command(["lsof", "-nP", "-p", pid])
    files = report["files"]["stdout"]
    assert report["files"]["code"] == 0
    actual_ptys = set(re.findall(r"/dev/ttys\d+", files))
    assert actual_ptys == set(run["ptys"].values()), actual_ptys
    assert not re.search(r"/dev/(?:cu|tty)\.", files), "Real serial device opened"
    # Inspect regular writable descriptors, not read-only dylibs and source.
    for line in files.splitlines()[1:]:
        columns = line.split(None, 8)
        if len(columns) == 9 and columns[4] == "REG" and columns[3].endswith(("w", "u")):
            assert Path(columns[8]).is_relative_to(TMP_ROOT), line
    report["environment"] = command(["ps", "eww", "-p", pid, "-o", "command="])
    env_text = report["environment"]["stdout"]
    for name in ("HOME", "TMPDIR", "XDG_CACHE_HOME", "XDG_CONFIG_HOME", "LOCAL_STATE_DB_PATH",
                 "LOCAL_METRICS_DB_PATH", "DIAGNOSTICS_DB_PATH"):
        assert f"{name}={run['backend_state']}/" in env_text, name
    assert "SORTER_BASE_REPORTING_OFF=1" in env_text
    assert "LEGOSORTER_DISABLE=servos" not in env_text, "SC acceptance must not disable servos"
    assert "SORTER_MCU_BAUD=115200" in env_text
    report["camera_config"] = http(api + "/api/cameras/config")
    assert all(value in (None, -1) for role, value in report["camera_config"].items() if role != "layout")
    report["camera_health"] = http(api + "/api/cameras/health")
    assert report["camera_health"], "No camera-health observation"
    assert all(value["status"] == "unassigned" and value["last_frame_at"] is None
               for value in report["camera_health"].values()), report["camera_health"]
    report["hive_targets"] = http(api + "/api/hive/targets")
    assert report["hive_targets"] == []
    report["sandbox_profile"] = (Path(run["backend_state"]) / "backend.sb").read_text()
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

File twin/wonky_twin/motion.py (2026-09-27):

"""Integer 1 kHz motion / 10 kHz pulse FSM, ported from pinned Stepper.cpp.

Only the pulse accumulator drives mechanical revolutions. A counter rebase or
microstep change cannot teleport the plant. No torque/contact physics claimed.
See fixtures/firmware-license.txt for the original MIT notice.
"""
from dataclasses import dataclass, field


@dataclass
class Stepper:
    name: str
    position: int = 0
    revolutions: float = 0.0
    state: str = "STOPPED"
    speed: int = 0
    speed_frac: int = 0
    steps_frac: int = 0
    steps_moved: int = 0
    direction: int = 1
    target_direction: int = 1
    distance: int = -1
    target_speed: int = -1
    brake_distance: int = 0
    min_speed: int = 16
    max_speed: int = 4000
    acceleration: int = 20000
    microsteps: int = 8
    enabled: bool = False
    home_channel: int | None = None
    home_active_high: bool = False
    position_reset: bool = False
    position_reset_ns: int | None = None
    jitter_remaining: int = 0
    jitter_amplitude: int = 0
    saved_limits: tuple = ()
    stall_enabled: bool = False
    registers: dict = field(default_factory=dict)
    current: tuple = (0, 0, 0)
    chopconf: int = 0
    chopper_on: bool = False

    def initialize_driver(self):
        # TMC2209.cpp's shadow is independent of raw WRITE_REGISTER calls.
        self.chopconf = 0x150100C3  # INTPOL, MRES=5, TBL=2, HEND=1, HSTRT=4, TOFF=3
        self.registers.update({0x00: 0x1C0, 0x6C: self.chopconf, 0x10: 0})
        self.microsteps, self.current = 8, (0, 0, 0)
        self.enabled, self.chopper_on = False, True  # nEN high, chopper on

    def set_enabled(self, enabled):
        if not enabled or not self.chopper_on:
            self.chopconf = (self.chopconf & ~0xF) | (3 if enabled else 0)
            self.registers[0x6C] = self.chopconf
            self.chopper_on = enabled
        self.enabled = enabled

    def set_microsteps(self, microsteps):
        self.microsteps = microsteps
        self.chopconf = (self.chopconf & ~(0xF << 24)) | ((8 - (microsteps.bit_length() - 1)) << 24)
        self.registers[0x6C] = self.chopconf

    @property
    def jittering(self):
        return self.jitter_remaining > 0

    def set_limits(self, minimum, maximum):
        minimum, maximum = min(minimum, 60000), min(maximum, 60000)
        if minimum <= maximum:
            self.min_speed, self.max_speed = minimum, maximum

    def _begin_distance(self, distance):
        self.distance = abs(distance)
        self.target_direction = 1 if distance > 0 else -1
        self.target_speed = -1
        self.home_channel = None
        self.speed, self.speed_frac = self.min_speed, 0
        self.direction = self.target_direction
        self.steps_moved = self.steps_frac = 0
        self.brake_distance = self.distance // 2
        self.state = "ACCELERATING"

    def move_steps(self, distance):
        if self.jittering or self.state != "STOPPED":
            return False
        if distance:
            self._begin_distance(distance)
        return True

    def move_at_speed(self, speed):
        if self.jittering:
            return False
        self.home_channel = None
        self.steps_moved = self.steps_frac = 0
        self.distance = -1
        if speed == 0:
            self.target_speed = 0
            self.target_direction = self.direction
            if self.state == "STOPPED":
                self.speed = self.speed_frac = 0
            else:
                self.state = "BRAKING"
            return True
        self.target_direction = 1 if speed > 0 else -1
        self.target_speed = min(abs(speed), 60000)
        if self.state == "STOPPED":
            self.direction = self.target_direction
            self.speed, self.speed_frac = self.min_speed, 0
            self.state = "ACCELERATING"
        elif self.direction != self.target_direction or self.speed > self.target_speed:
            self.state = "BRAKING"
        elif self.speed == self.target_speed:
            self.state = "CRUISING"
        else:
            self.state = "ACCELERATING"
        return True

    def jitter(self, amplitude, cycles, speed, acceleration):
        if self.jittering or self.state != "STOPPED" or min(amplitude, cycles, speed, acceleration) <= 0:
            return False
        self.saved_limits = self.min_speed, self.max_speed, self.acceleration
        self.acceleration = acceleration
        self.set_limits(self.min_speed, speed)
        self.jitter_remaining = cycles * 2
        self.jitter_amplitude = amplitude
        self._begin_distance(amplitude)
        return True

    def home_check(self, inputs, sim_ns):
        if self.home_channel is not None and bool(inputs[self.home_channel]) == self.home_active_high:
            self.state = "STOPPED"
            self.speed = 0
            self.position = 0
            self.position_reset = True
            self.position_reset_ns = sim_ns
            self.home_channel = None
            return True
        return False
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

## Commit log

2026-09-27 wonky: public export
    Rust CAD kernel with FeatureScript front end. CAD-Acid on the Rust kernel:
    35/48 strict and practical, 0 WRONG (three-tier verdicts CORRECT/TOLERANT/WRONG),
    STL export and the wonky-cli/v1 JSON contract, acid-perf benchmark harness.
    History reset to a single sanitized snapshot.
    [boolean-box-face-tangent-intersect.step, boolean-box-face-tangent-intersect.stl, boolean-box-near-disjoint-intersect.step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]
2026-10-04 wonky: public export
    [analytical.step, curved-patch.step, model.step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]
